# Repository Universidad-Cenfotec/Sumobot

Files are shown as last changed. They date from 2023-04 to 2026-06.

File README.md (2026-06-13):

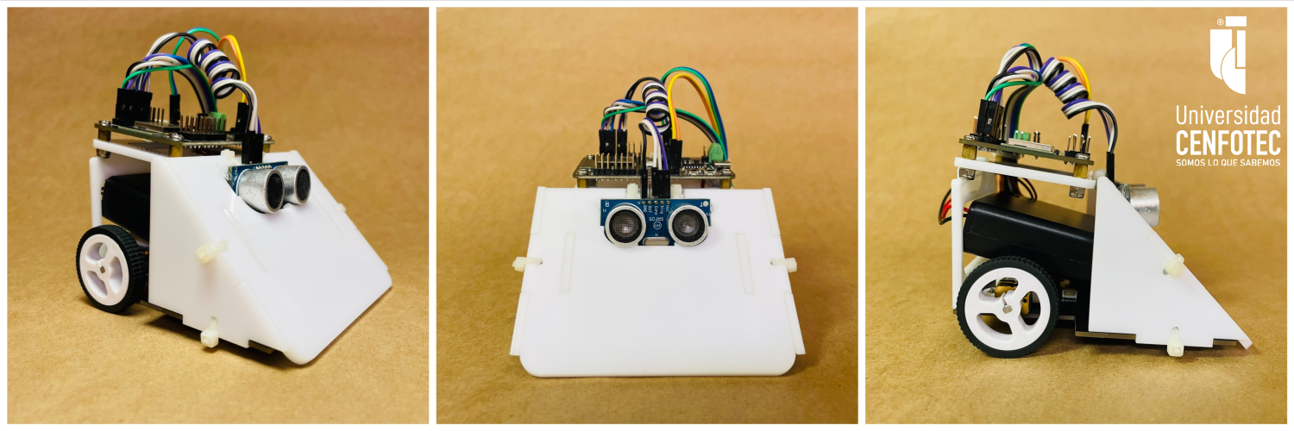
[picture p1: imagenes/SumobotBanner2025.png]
SumoBot


# ¿Que es el SumoBot de CENFOTEC? (o CenfoBot)

El Sumobot es un robot simple, 100% desarrollado en Costa Rica, para competencias colegiales de Sumobot. Fue diseñado por el profesor Tomás de Camino Beck para la Universidad Cenfotec como parte de un programa de transformación educativa, con el objetivo de ampliar las capacidades de pensamiento computacional tanto en estudiantes de colegio como en estudiantes universitarios.

> [En este enlace puede leer sobre la historia del Sumobot en sus 3 primeros años](https://crhoy.com/sumobot-una-historia-de-tecnologia-hecha-en-costa-rica/)  
> [Articulo técnico del Sumobot como plataforma de enseñanza](https://www.researchgate.net/publication/400625563_El_Sumobot_como_herramienta_de_aprendizaje_tecnologico_diseno_implementacion_y_evaluacion_en_torneos_colegiales)

El Sumobot utiliza la placa [IdeaBoard](https://github.com/CRCibernetica/circuitpython-ideaboard/wiki), desarrollada por CrCibernética. Esta placa de código abierto (Open Source) incorpora un microcontrolador ESP32 y permite la conexión sencilla de sensores y motores, así como su programación mediante USB o Wi‑Fi.

Para el montaje del robot, se emplea un *shield* de robótica especialmente diseñado por la Universidad CENFOTEC (por el profesor Tomás de Camino Beck) en colaboración con CrCibernética. Este componente puede [adquirirse en este enlace](https://www.crcibernetica.com/sumobot-shield/).

Puede ver este [video resumen](https://youtu.be/L98O-mApjXQ) de la primera competencia de Sumobot de Costa Rica, celebrada en el Maker Faire San José 2023. Y acá pueden ver un [video resumen](https://youtu.be/9zarR0cKY90?si=D4UTzPx91h4megWT) de la segunda edición en el 2024, y de la [tercera edición 2025](https://youtu.be/qRWDWPndxq8?si=iimM-hLvY60RDaJC)

[Documento técnico explicando los elementos pedagógicos del Sumobot](https://www.researchgate.net/publication/400625563_El_Sumobot_como_herramienta_de_aprendizaje_tecnologico_diseno_implementacion_y_evaluacion_en_torneos_colegiales)

---

## Contenidos de este Repositorio

- [EL espíritu del Torneo Sumobot](https://github.com/Universidad-Cenfotec/Sumobot/blob/main/espiritu_sumobot.md)
- [Componentes del Sumobot](https://github.com/Universidad-Cenfotec/Sumobot/blob/main/componentes2025.md)
- [Armado del Sumobot](https://github.com/Universidad-Cenfotec/Sumobot/blob/main/Armado%20paso%20a%20paso.md)
- [Conexiones del Sumobot](https://github.com/Universidad-Cenfotec/Sumobot/blob/main/conexiones.md)
- [Programación del Sumobot](https://github.com/Universidad-Cenfotec/Sumobot/blob/main/programacion.md)
- [Un buen código de inicio con explicaciones](https://github.com/Universidad-Cenfotec/Sumobot/tree/main/c%C3%B3digos_de_ejemplo/codigo%20inicio)
- [Códigos de ejemplo y códigos IdeaBoard](https://github.com/Universidad-Cenfotec/Sumobot/tree/main/c%C3%B3digos_de_ejemplo)
- [Sobre los 4 sensores infrarrojos](https://github.com/Universidad-Cenfotec/Sumobot/blob/main/c%C3%B3digos_de_ejemplo/sensores_infrarrojos.md)
- [Cómo calibrar los sensores infrerrojos, grabando los datos](https://youtu.be/5G9ZTyPEq5s?si=Cqf4HQZEF9e04VTD)
- [Especificaciones del Dojo](https://github.com/Universidad-Cenfotec/Sumobot/blob/main/dojo.md)
- [Reglas del Torneo Sumobot](https://github.com/Universidad-Cenfotec/Sumobot/blob/main/reglas%20de%20competencia.md)
- [Preguntas frecuentes](https://github.com/Universidad-Cenfotec/Sumobot/blob/main/FAQ.md)
- [Playlist de Videos de Sumobot](https://www.youtube.com/watch?v=Cxlyzh-E9kE&list=PLySA0noR1JGVZg5L3hGVwRD3PP2ibNYMT)

## Contenidos Avanzados
- [Programación en C/C++ (Avanzado)](https://github.com/Universidad-Cenfotec/Sumobot/tree/main/c%C3%B3digos_de_ejemplo_c%2B%2B/sumobot)
- [Control PDI de motores y navegación](https://github.com/Universidad-Cenfotec/Sumobot/blob/main/c%C3%B3digos_de_ejemplo/Control_Movimientos.md)
- [Almacenamiento de datos en el robot para análisis posterior](https://github.com/Universidad-Cenfotec/Sumobot/blob/main/c%C3%B3digos_de_ejemplo/almacenando_datos.md)
- [Ejemplo de automatización de vehiculos asistidos](https://github.com/Universidad-Cenfotec/Sumobot/tree/main/c%C3%B3digos_de_ejemplo/AGVs)
- [Sumobot con planificación autónoma con Modelos de Lenguajes (Gemini)](https://github.com/Universidad-Cenfotec/Sumobot/tree/main/c%C3%B3digos_de_ejemplo/LLM_in_the_Loop_Robotics)
- [Programación del Sumobot con bloques a través de una aplicación web](https://github.com/Universidad-Cenfotec/Sumobot/tree/main/c%C3%B3digos_de_ejemplo/codigo_bloques)

## Asistente IA para programar el Sumobot

- [GPT entrenado para programación Sumobot](https://chatgpt.com/g/g-6863f71f27b8819192a51ed05df367b0-asistente-de-programacion-sumobot-cenfotec)

## Retos

- Hacer una estrategia de "scan" del contrincante más eficiente
- Hace movimientos oscilatorios para tratar de levantar al oponente
- Utilizar giroscopios para movimientos exactos ([ver este código](https://github.com/Universidad-Cenfotec/Sumobot/blob/main/c%C3%B3digos_de_ejemplo/Control_Movimientos.md))
- Utilizar el "botón 0" para que arranque el robot apenas suelten el botón ([ver este código](https://github.com/Universidad-Cenfotec/Sumobot/blob/main/c%C3%B3digos_de_ejemplo/code_boton0.py))
- Entender que cada combate inicia diferente y aprovechar esas posiciones
- Estudiar comportameinto de sensores almacenando los datos ([ver este código](https://github.com/Universidad-Cenfotec/Sumobot/blob/main/c%C3%B3digos_de_ejemplo/almacenando_datos.md))

## Algunos Saberes Escenciales de el Sumobot

| Área de Conocimiento | Saberes Esenciales | Ejemplos desde el Kit Sumobot |
| --- | --- | --- |
| **1. Pensamiento Computacional** | - Estructuras de control<br>- Modularidad<br>- Algoritmos<br>- Programación de eventos | `code.py`, `retroceso.py`, `code_boton0.py`, `code_set_pixel_to.py`, uso de funciones en todos los scripts |
| **2. Robótica y Electrónica** | - Lectura de sensores<br>- Control de motores<br>- Interacción hardware-software <br>- Precepción del entorno  <br>- Calibración de sensores <br>- Interacción con otros agentes  <br>- Menjo de incertidumbre  | `code_ultrasonic.py`, `code_acc_motor_move.py`, `Control_Movimientos.md`, `Pixel_colores.py` |
| **3. Ciencia de Datos** | - Registro de datos<br>- Análisis y visualización<br>- Experimentación <br>- Desiciones basadas en datos | `code_storage.py`, `code_storage_IR.py`, `almacenando_datos.md`, ejemplo de uso con Google Sheets |
| **4. Matemáticas Aplicadas** | - Lógica binaria<br>- Cálculo de gradientes<br>- Estimación de distancia <br>- Sistemas de control <br>- Integral y derivada | `code_lecturaIR_4Bit.py`, `code_gradiente.py`, `Calculo _Gradiente.md`, `code_ultrasonic.py` |
| **5. Ingeniería de Sistemas** | - Diseño e integración de componentes<br>- Diagnóstico y prueba de sistemas <br>- Verificación de errores <br>- Interacción humano máquina <br>- Sistemas complejos  <br>- Programación Asistida IA <br>- Inteligencia Artificial | `code_diagnostic.py`, `SumoBot_Device_Files.zip`, `movimiento_base.md`, `libreria IdeaBoard.md` |
| **6. Habilidades Transversales (STEAM)** | - Resolución de problemas<br>- Trabajo en equipo<br>- Comunicación técnica <br>- Autodeterminación | Uso de Markdown (`*.md`), documentación clara, posibilidad de trabajo colaborativo y creativo con el robot |

---

# Una plataforma Open Source

## ¿Por qué un robot open source?

El Sumobot fue diseñado como una plataforma educativa abierta para el aprendizaje de robótica, programación y sistemas autónomos. Un robot open source permite que cualquier persona —estudiantes, docentes, clubes de robótica o investigadores— pueda construirlo, modificarlo y adaptarlo a sus propias necesidades.

En robótica educativa es fundamental que los estudiantes no solo usen la tecnología, sino que puedan comprender cómo funciona. Un robot abierto permite estudiar todos sus componentes: electrónica, sensores, control de motores, algoritmos de comportamiento y diseño mecánico. Esto convierte al robot en un laboratorio completo de aprendizaje.

Además, un diseño abierto reduce las barreras de acceso. Las instituciones educativas pueden reproducir el robot localmente utilizando componentes accesibles, lo que facilita su adopción en escuelas y colegios.

## ¿Por qué el diseño open source?

El diseño mecánico del robot también es abierto para que pueda ser reproducido mediante fabricación digital. Esto incluye archivos de diseño que permiten imprimir o fabricar las piezas del robot en impresoras 3D, cortadoras láser u otros métodos de fabricación.

Esto tiene varias ventajas educativas y técnicas:

* Permite que los estudiantes comprendan cómo el diseño físico afecta el comportamiento del robot.
* Facilita modificaciones y mejoras en la estructura del robot.
* Permite adaptar el robot a diferentes materiales o tecnologías de fabricación.
* Promueve la cultura *maker* y la experimentación.

Un robot de competencia no es solo software; el diseño físico influye directamente en su desempeño en el dojo. Tener el diseño abierto permite explorar estas decisiones de ingeniería.

## ¿Por qué el código open source?

El comportamiento del robot es controlado por software. Hacer el código open source permite que los estudiantes y participantes del torneo puedan estudiar cómo se toman las decisiones dentro del robot.

Esto permite:

* Aprender algoritmos de control para robots autónomos.
* Experimentar con diferentes estrategias de combate.
* Comprender cómo se integran sensores, actuadores y lógica de decisión.
* Desarrollar nuevas versiones del comportamiento del robot.

El objetivo no es que todos los robots ejecuten exactamente el mismo programa, sino que cada equipo pueda desarrollar su propia estrategia a partir de una base común.

## ¿Por qué un torneo open source?

El torneo también se basa en una filosofía abierta. En lugar de esconder las tecnologías o estrategias, se promueve compartir conocimiento entre equipos, docentes y estudiantes.

Esto genera varios beneficios:

* acelera el aprendizaje colectivo
* permite mejorar el robot y el torneo con el tiempo
* fomenta la colaboración entre instituciones
* convierte el torneo en una comunidad de aprendizaje

El objetivo del torneo no es solo competir, sino aprender robótica de forma práctica. Cada edición del torneo genera nuevas mejoras en el robot, en el código y en las estrategias de control.

De esta manera, el Sumobot no es solo un robot ni solo una competencia. Es una plataforma abierta de aprendizaje en robótica.

---

# Licencia

Sumobot es un robot desarrollado con el propósito de potenciar el aprendizaje de computación en colegios. Este proyecto está abierto a contribuciones y estamos encantados de recibir nuevas ideas.

Este robot está protegido por una licencia Creative Commons. Específicamente, se trata de la licencia CC BY‑NC‑SA 4.0, que significa Atribución‑NoComercial‑CompartirIgual 4.0 Internacional.

Bajo esta licencia, se permite el uso, distribución y modificación del robot, pero con las siguientes condiciones:
- **Atribución** — Debes dar el crédito correspondiente, proporcionar un enlace a la licencia e indicar si se han realizado cambios.
- **NoComercial** — No puedes utilizar el material para una finalidad comercial.
- **CompartirIgual** — Si remezclas, transformas o creas a partir del material, debes distribuir tus contribuciones bajo la misma licencia que el original.

Para obtener más detalles sobre la licencia, por favor visita [https://creativecommons.org/].

CC


# Contribuciones

Si estás interesado en contribuir al Sumobot, por favor revisa las guías de contribución disponibles en la sección de "Documentación". Todas las contribuciones son bienvenidas, sin importar cuán pequeñas sean. Juntos podemos hacer que Sumobot sea mejor para todos.

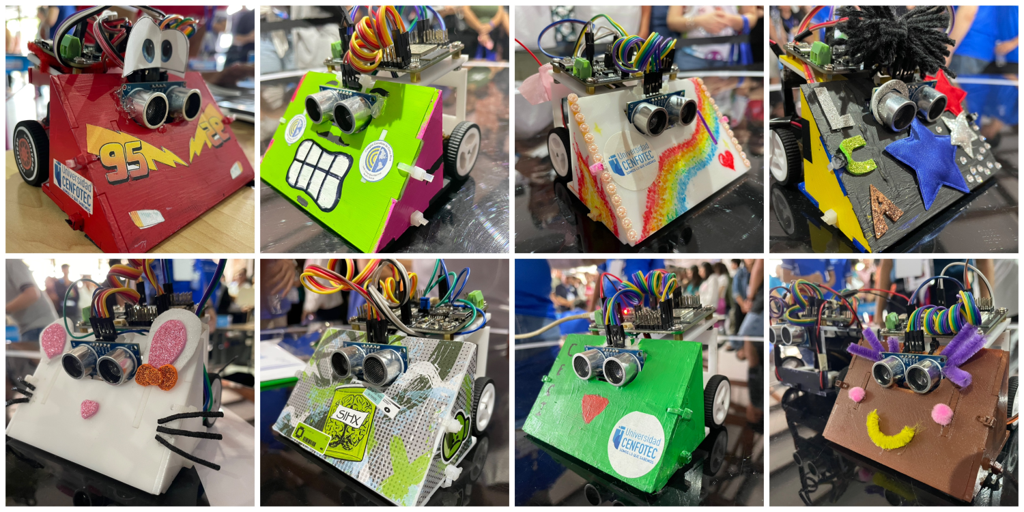
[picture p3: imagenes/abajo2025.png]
SumoBot1


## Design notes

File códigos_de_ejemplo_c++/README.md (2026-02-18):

# C++ con el FrameWork de Arduino 🍝
C++ es un versátil lenguaje de "bajo nivel", lo que significa que habla casi directo con los circuitos del chip. El framework de Arduino funciona como un traductor amigable que envuelve a C++ para que no tengas que ser un genio de la computación para encender un LED, este se encarga de exponer funciones útiles como lecturas de pines, comunicación Serial, Etc.

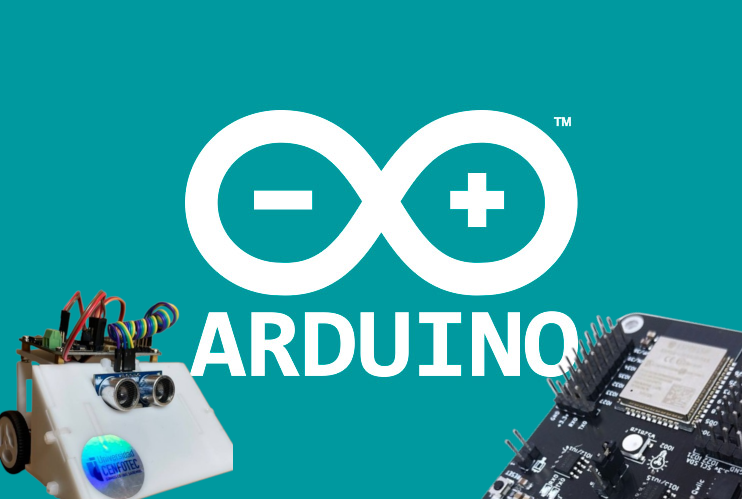
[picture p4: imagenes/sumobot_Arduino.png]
SumobotArduino


# Programar el IdeaBoard con C/C++

## Instalación de Arduino IDE
Para programar el ideaboard con C/C++ puede utilizar el Arduino IDE. [En este video se Explica como instalar y utilizar el Arduino IDE](https://youtu.be/Gd5cj3yKtPM?si=9Gexbs7unJ-1I55R)

## Dirección de Pines del IdeaBoard
Todos sketchs usan las conexiones estandar que se encuentran en el archivo [conexiones.md](https://github.com/Universidad-Cenfotec/Sumobot/blob/main/conexiones.md) para el sumobot version 2025.

Ya que no se está usando la libreria ideaboard.py para la desobfuscación de ciertos pines, tienes que referirte a los pines del ESP32 conectada a la placa en el código 

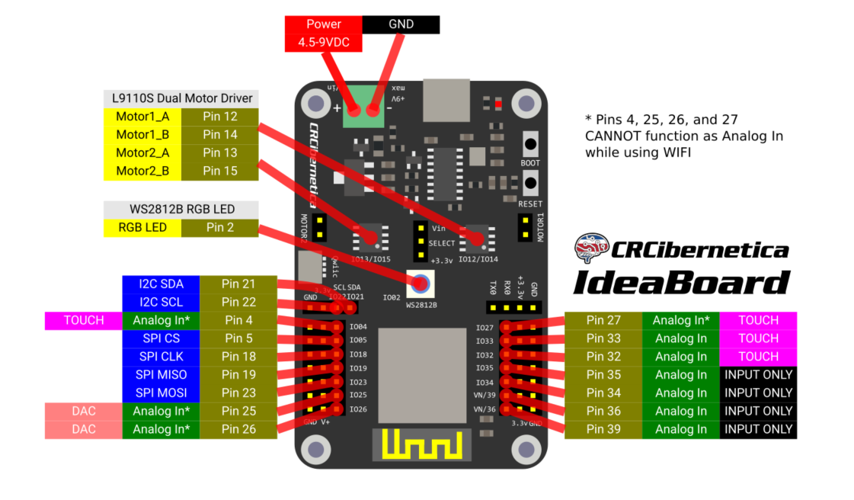
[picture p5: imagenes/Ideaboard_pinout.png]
pinout


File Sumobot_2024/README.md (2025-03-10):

## Componentes del Sumobot 2024
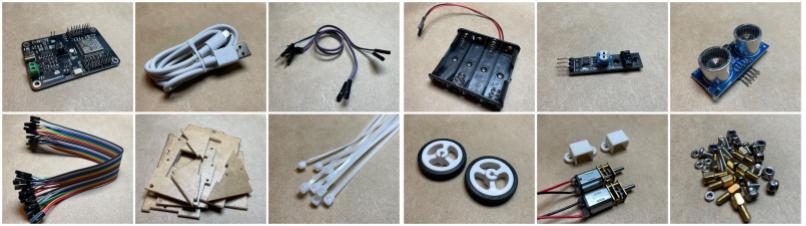
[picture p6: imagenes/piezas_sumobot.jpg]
SumoBot Parts


- [IdeaBoard (ESP32)](https://www.crcibernetica.com/crcibernetica-ideaboard/)
- Cable USB C
- Tiras de plástico de 2.5 mm
- Tornillos y tuercas para colocar la placa IdeaBoard
- Tornillos adicionales para sostener los motores
- 2 x soportes de motor microgear
- 2 x [micro motores](https://www.crcibernetica.com/micro-gearmotor/) de 200 RPM
- 2 x ruedas
- Soporte de 4 baterías AA
- [Sensor IR](https://www.crcibernetica.com/track-sensor-module/)
- [Sensor ultrasónico](https://www.crcibernetica.com/hc-sr05-ultrasonic-distance-sensor/) de distancia (HCSR04)
- Piezas de acrílico de 3 mm ([Ver archivo de corte láser](https://github.com/Universidad-Cenfotec/Sumobot/blob/main/archivos_de_fabricacion/chasis_sumobot.svg))

Todos los componentes se pueden encontrar en Costa Rica en [CrCibernética](https://www.crcibernetica.com/sumobot-universidad-cenfotec/). [Aquí pueden ver un video](https://youtu.be/N60gXp_uzeo?si=2TApsz6n20wZ9ZoX) de los componentes que vienen como parte del kit.

---

## Chasis del Sumobot 2024

El archivo "Sumobot_Chasis.svg" está en formato SVG para corte láser del chasis de Sumobot. Se puede cortar tanto en acrílico, MDF u otro material de 3 mm de espesor.

También, con el archivo [chasis_sumobot_2025_3D.stl](https://github.com/Universidad-Cenfotec/Sumobot/blob/main/archivos_de_fabricacion/chasis_sumobot2025_3D.stl) pueden imprimir el chasis en una impresora 3D. Esto facilita agregar estructuras más complejas que no son posibles en 2D.

El chasis del robot se une con tiras (gasas/zip ties) de plástico de 2.5 mm, lo que facilita el armado, la reparación o la modificación de algunas partes.

---

# Armando el Sumobot 2024

Pueden ver [este video detallado](https://youtu.be/m4y3BSPjgoc?si=vLK6NNjRJQF1DbDc) de cómo armar el Sumobot.

## Kit Sumobot
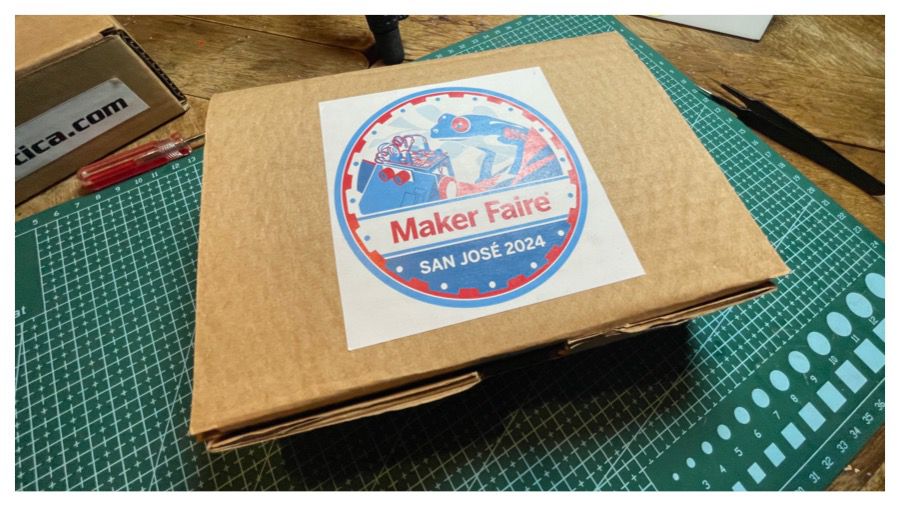
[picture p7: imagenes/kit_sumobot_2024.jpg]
Kit Sumobot


El Kit Sumobot es creación de la Universidad CENFOTEC y lo distribuye CrCibernetica.com. Si desean adquirir el kit, pueden contactar libremente a CrCibernetica.

## Esquema de conexiones Sumobot 2024

- El sensor infrarrojo se conecta en el IO033.
- El sensor ultrasónico se conecta en el IO026 (trig) e IO025 (echo).
- Los motores se conectan en Motor 1 y Motor 2 (con posiciones invertidas).

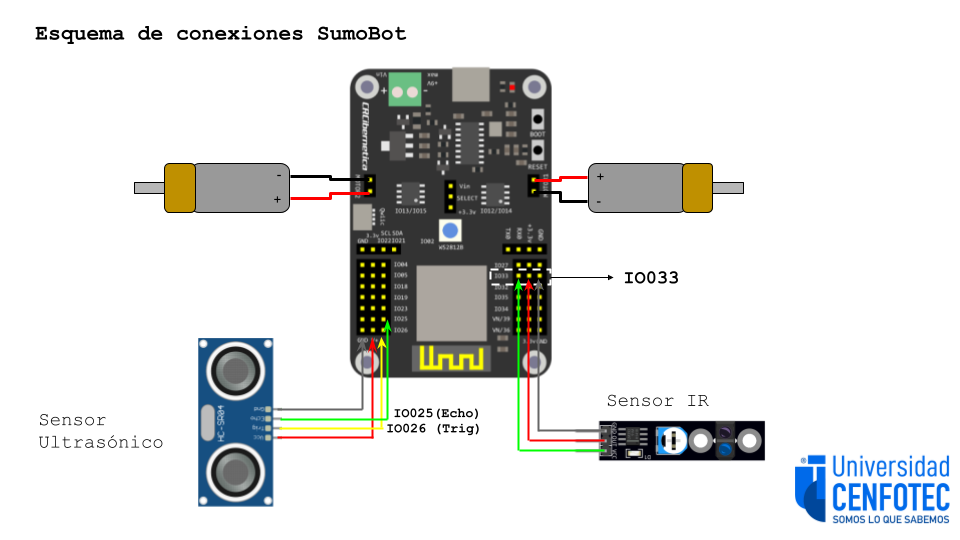
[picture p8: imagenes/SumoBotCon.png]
SumoBot_Conexions


## Baterías
Las baterías se conectan: el cable rojo al pin marcado como "+" y el negro al pin "-", como se muestra en el siguiente esquema:

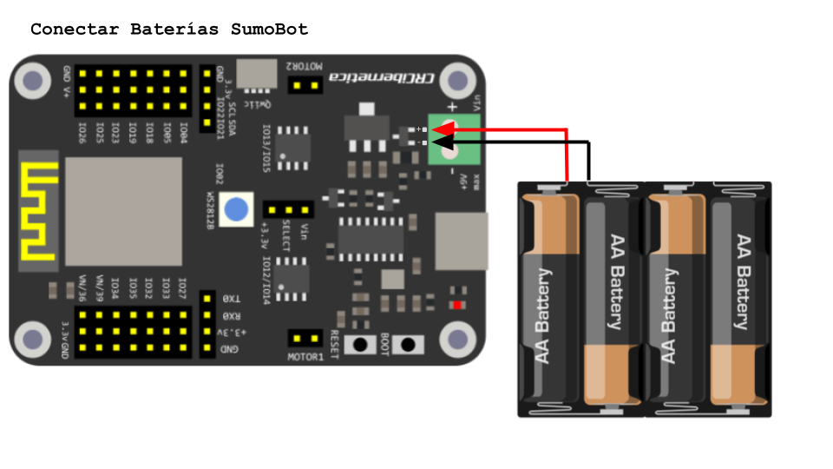
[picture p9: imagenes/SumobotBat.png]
SumoBot_baterías


## Software para programar el Sumobot 2024

Para programar el Sumobot se utiliza Thonny, el cual se puede descargar desde este [enlace](https://thonny.org/).

### Instrucciones:
- Descargar la última versión de Thonny.
- Instalar.
- Una vez instalado, ir al menú "Herramientas > Opciones" o "Tools > Options" en inglés.
- En la pestaña "Intérprete" (o "Interpreter" en inglés), seleccionar "CircuitPython (Generic)".
- ¡Listo!
- [Video con detalles](https://youtu.be/Zc3oaAbVAdc)

## Código 2024

El código "code.py" está desarrollado en CircuitPython. CircuitPython es un subconjunto de Python desarrollado para microcontroladores y facilita la portabilidad y programabilidad de dispositivos como el ESP32, entre otros. El Sumobot ya viene preparado para trabajar con CircuitPython y no es necesario cargar archivos adicionales. Si por alguna razón se debe "reflashear" el IdeaBoard, siga las instrucciones en este [enlace](https://github.com/CRCibernetica/circuitpython-ideaboard/wiki/3.-Installation).

El código "hcsr04.mpy" corresponde a la librería para el sensor de distancia, el cual se utiliza para detectar otro robot que esté al frente del Sumobot.

### Funciones Básicas 2024

- **wiggle(t, n, speed):** Hace que el bot se mueva de izquierda a derecha durante _t_ segundos, a velocidad _speed_, repitiéndolo _n_ veces.
- **forward(t, speed):** Mueve el bot hacia adelante durante _t_ segundos a velocidad _speed_.
- **backward(t, speed):** Mueve el bot hacia atrás durante _t_ segundos a velocidad _speed_.
- **left(t, speed):** Mueve el bot hacia la izquierda durante _t_ segundos a velocidad _speed_.
- **right(t, speed):** Mueve el bot hacia la derecha durante _t_ segundos a velocidad _speed_.
- **stop():** Detiene el bot.
- **randomTurn(t, speed):** Gira al azar a la izquierda o a la derecha durante _t_ segundos a velocidad _speed_.
- **lookForward():** Realiza la lectura del sensor ultrasónico y retorna la distancia en cm de lo que esté en frente del bot.
- **scan():** Rota hacia un lado hasta que detecta algo adelante o hasta que gire un número determinado de veces.
- **forwardCheck(t, speed):** Mueve hacia adelante, pero verifica, mediante el sensor IR, que no se salga del dojo. Cuando detecta el borde, realiza un movimiento hacia atrás y luego gira.

### Recuperar la configuración inicial

Si por alguna razón se desea resetear el Sumobot a los archivos iniciales, cargue, a través de Thonny en el dispositivo CircuitPython (con el Sumobot conectado), todos los archivos que vienen en el archivo ZIP "SumoBot_Device_Files.zip".

---

## Videos Instructivos 2024
- [Cómo instalar Thonny](https://youtu.be/Zc3oaAbVAdc)
- [Conectar el Sumobot a Thonny](https://youtu.be/SpIcqRKmczk)
- [Instalando las baterías del Sumobot](https://youtu.be/ndWJ0q0M8CI)
- [Calibrando el sensor infrarrojo](https://youtu.be/XXJbzzaVefk) 
- [El código principal del Sumobot](https://youtu.be/86sQCr-bjjk)
- [CircuitPython: Programando el LED RGB](https://youtu.be/5ezFqexHwQE)
- [Programando el sensor infrarrojo](https://youtu.be/1JA3G-FPpJ4)
- [Programando el sensor ultrasónico](https://youtu.be/RwY2lEPkyg8)
- [Motores DC con el Sumobot](https://youtu.be/MybJACeDIgA)

---

# Competencia SumoBot 2024
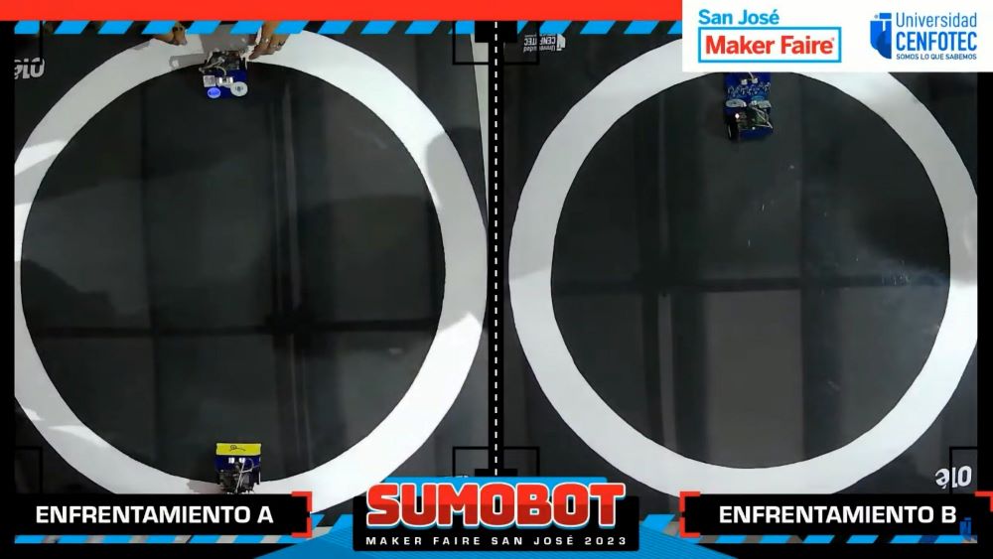
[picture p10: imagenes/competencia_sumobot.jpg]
SumoBot_Dojo


## Formato de competición 2024

- El torneo SumoBot se estructura como un torneo por eliminatoria.
- Dos robots compiten en un "dojo". El robot que sea sacado del ring, que deje de funcionar o que no tenga posibilidad de movimiento, pierde.
- Se define una llave previa en la que los equipos serán asignados al azar.
- Denominamos "set" a cada encuentro entre dos robots.
- Cada set consiste en 3 juegos (matches) de un minuto y medio, con una pausa de un minuto entre cada juego para ajustes o cambios de estrategia.
- El "dojo" es un ring circular de 80 cm de diámetro, con fondo negro y una línea de borde blanca de 5 cm. De esta manera, los robots pueden identificar cuándo están dentro o fuera del ring y detectar el borde mediante un sensor infrarrojo.
- Este archivo PDF contiene el diseño del [Mini‑Dojo](https://github.com/Universidad-Cenfotec/Sumobot/blob/main/circulo_10cmEspesor.pdf). El Mini‑Dojo se puede utilizar para probar diferentes ideas y garantizar que el robot funcione, pero siempre se debe tener en cuenta que el dojo de la competencia es mucho más grande y, además, cuenta con una lámina de acrílico de 3 mm.

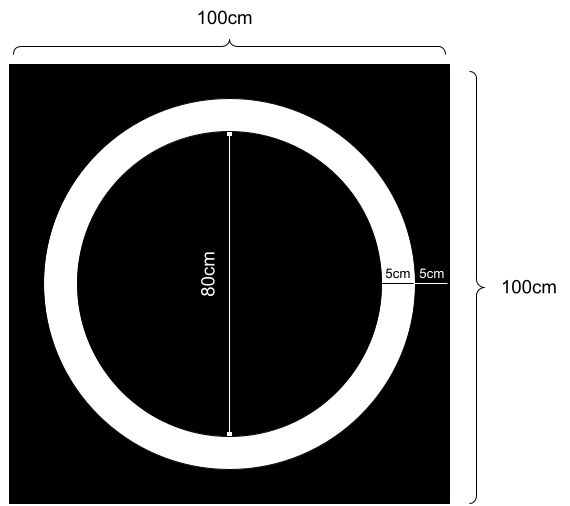
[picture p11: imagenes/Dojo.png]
Dojo


## Principios del juego 2024

- La mesa de arbitraje revisará el robot para determinar que cumple con las especificaciones requeridas.
- Son tres combates por partida, y se gana por puntos.
- Un robot perderá si es removido del dojo más allá de la línea blanca del borde o si no ejecuta ningún movimiento durante el tiempo asignado.
- Cada batalla tiene una duración máxima de 1 minuto y 30 segundos.
- En caso de empate (si ninguno de los robots es sacado del dojo), la mesa de arbitraje considerará ganador al robot con mayor número de ataques.
- Las tres acciones de batalla son: atacar, defender y buscar.
- La competencia es por eliminación, y los equipos se clasifican en pares hasta la final.
- El código de los dos primeros lugares será publicado de forma abierta en este GitHub, con el fin de ir mejorando el nivel año con año.

---

# Reglamento 2024

## DEFINICIONES:
1. **Sumobot:** El robot Sumobot es un robot de combate autónomo programado por el usuario, que deberá sacar a su rival del área de combate (dojo), ya sea empujándolo, arrastrándolo o dejándolo inhabilitado.
2. **Partida:** Enfrentamiento entre 2 robots de diferentes equipos, dividido en 3 combates.
3. **Maker Space:** Laboratorio de innovación de la Universidad CENFOTEC.
4. **GitHub:** Plataforma para crear proyectos abiertos de herramientas y aplicaciones, caracterizada, sobre todo, por sus funciones colaborativas que ayudan a que todos puedan aportar su granito de arena para mejorar el código.
5. **Mesa de arbitraje:** Persona o grupo de personas con autoridad, responsables de presidir el juego desde un punto de vista neutral y de tomar decisiones sobre la marcha que hagan cumplir las reglas de este reglamento.
6. **Dojo:** Área de combate, el espacio formado por la tarima circular y un espacio circundante denominado "área exterior de seguridad".
7. **Ronda:** Sistema en torneos en el que el perdedor de un encuentro queda inmediatamente eliminado de la competición, mientras que el ganador avanza a la siguiente fase. Se juegan rondas y, en cada una de ellas, se elimina a la mitad de los participantes hasta dejar un único competidor que se corona como campeón.

## ESPECIFICACIONES DEL ROBOT 2024
1. Los robots son entregados por la Universidad CENFOTEC. Los colegios deben armar los robots siguiendo las instrucciones publicadas por la Universidad CENFOTEC en GitHub.
2. El peso del robot, incluyendo la caja y las baterías, es de 260 g. El peso debe mantenerse siempre entre 260 y 290 gramos. Al agregar otros sensores, el peso puede aumentar ligeramente (por ejemplo, un sensor ultrasónico pesa aproximadamente 8.5 gramos).
3. No se permiten modificaciones estructurales en el robot. Se puede adaptar para colocarle más sensores, pero no se permiten agregar puntas o extensiones para otros propósitos.
4. Se pueden agregar sensores adicionales que no impliquen modificaciones en la estructura del robot.
5. No se pueden cambiar los neumáticos o las ruedas del robot, para asegurar condiciones de igualdad entre los robots y que el ganador se determine por estrategia.
6. No se pueden cambiar los motores.
7. No se puede utilizar otro tipo de baterías.
8. Cada robot será revisado antes de cada competencia.
9. En situaciones especiales respecto a las especificaciones del robot, su estructura y funcionamiento, que no estén claramente definidas en las reglas, se decidirá a criterio unificado de los jueces.

## REGLAS DEL JUEGO 2024
1. Un fiscal revisará cada robot para asegurarse de que cumple con las especificaciones requeridas. En caso de duda, será verificado por los jueces.
2. Cada partida consta de tres combates. En cada combate, a cada equipo se le asignan 3 puntos por ganar, 1 punto en caso de empate y 0 puntos por perder.
3. Al iniciar la partida, el equipo debe programar el robot para que espere 3 segundos antes de comenzar sus movimientos y actividades.
4. Un robot pierde si es removido del dojo más allá de la línea blanca del borde, si no ejecuta ningún movimiento durante el tiempo asignado o si queda inmovilizado por el oponente.
5. Cada batalla tiene una duración máxima de 1 minuto y 30 segundos.
6. En caso de empate en un combate, cada equipo gana 1 punto.
7. La competencia inicia por grupos, y las siguientes rondas son por eliminación, en las que los equipos avanzan en pares hasta la final.
8. Cada combate comienza de manera diferente: primero, con los robots frente a frente a una distancia aproximada de 10 cm; luego, espalda con espalda; y, finalmente, lado a lado, con los robots viendo en direcciones opuestas.
9. Entre cada combate se dispone de 1 minuto para revisar el robot y realizar posibles cambios.
10. Si en una partida los equipos quedan empatados por puntos, se hará la rifa por moneda.
11. De todos los equipos que perdieron en la primera ronda, se escogerá (por definir) un número de los segundos mejores.
12. Si en una partida uno de los equipos no se presenta, ganará automáticamente el que sí se presentó (obtendrá 9 puntos por partida en la primera ronda o pasará a la siguiente ronda a partir de la segunda ronda).
13. Si un equipo llega tarde a la primera partida, podrá presentarse a las siguientes, pero se le asignará la derrota en la primera partida.
14. Si en una partida ninguno de los equipos se presenta, para la siguiente ronda se seleccionarán los mejores segundos lugares.

## SANCIONES Y APELACIONES 2024
1. Si un equipo no se presenta para un "match" en el día del evento, el equipo oponente clasificará automáticamente.

## DISPOSICIONES FINALES
Este evento tiene como objetivo colaborar, apoyar y estimular a la comunidad, por lo que cada colegio representado podrá recibir apoyo de sus oponentes en el momento en que éstos lo manifiesten. Los docentes pueden ayudar y asesorar a sus equipos. Se espera que los docentes permitan y estimulen a sus estudiantes a realizar el 100% del trabajo.

---

# Preguntas Frecuentes

1. **¿El código se puede modificar?**  
   R: Sí, se puede modificar.

2. **¿Se pueden agregar partes al robot?**  
   R: No se permiten modificaciones estructurales del robot. Se puede adaptar para colocarle más sensores, pero no se permiten agregar puntas o extensiones para otros propósitos.

3. **¿Se puede modificar el hardware?**  
   R: Se pueden agregar sensores adicionales que no impliquen modificaciones en el robot (por ejemplo, modificar el chasis). Es decir, se pueden incorporar a la estructura del chasis sin agregar nada más. Cada robot será revisado antes de cada torneo de competencia.

4. **¿Se pueden agregar sensores de toque, por ejemplo?**  
   R: Se pueden agregar sensores adicionales que no impliquen modificaciones en el robot.

5. **¿Los estudiantes llevan la programación hecha o la memorizan?**  
   R: Los estudiantes llevan el programa hecho y, en el mismo evento, pueden modificar la programación. Si no cuentan con computador, se les facilitará uno en el evento.

---

# Algunas cosas por mejorar
- Algunos motores presentan problemas y generan un corto.
- Los cables de los motores deben ser más largos. Por el momento se están utilizando extensiones.

---

[Nombre del proyecto]

# Licencia

Sumobot es un robot desarrollado con el propósito de potenciar el aprendizaje de computación en colegios. Este proyecto está abierto a contribuciones y estamos encantados de recibir nuevas ideas.

Este robot está protegido por una licencia Creative Commons. Específicamente, se trata de la licencia CC BY‑NC‑SA 4.0, que significa Atribución‑NoComercial‑CompartirIgual 4.0 Internacional.

Bajo esta licencia, se permite el uso, distribución y modificación del robot, pero con las siguientes condiciones:
- **Atribución** — Debes dar el crédito correspondiente, proporcionar un enlace a la licencia e indicar si se han realizado cambios.
- **NoComercial** — No puedes utilizar el material para una finalidad comercial.
- **CompartirIgual** — Si remezclas, transformas o creas a partir del material, debes distribuir tus contribuciones bajo la misma licencia que el original.

Para obtener más detalles sobre la licencia, por favor visita [https://creativecommons.org/].

CC

# Contribuciones

Si estás interesado en contribuir al Sumobot, por favor revisa las guías de contribución disponibles en la sección de "Documentación". Todas las contribuciones son bienvenidas, sin importar cuán pequeñas sean. Juntos podemos hacer que Sumobot sea mejor para todos.

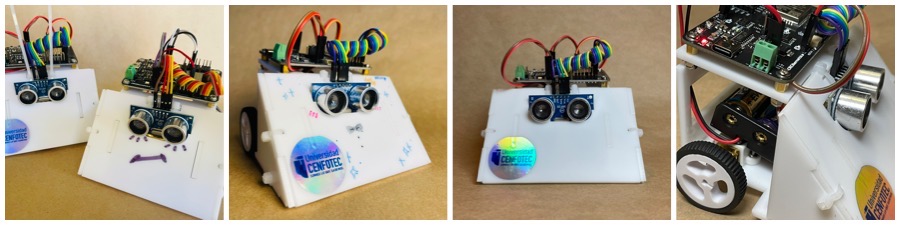
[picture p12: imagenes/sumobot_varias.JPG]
SumoBot1


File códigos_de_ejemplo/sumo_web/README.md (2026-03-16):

# Control remoto del Sumobot mediante Bluetooth Low Energy (BLE)

Fiorella Pérez López  
Universidad CENFOTEC

---

# Introducción

Este proyecto muestra cómo controlar un **Sumobot de forma remota utilizando Bluetooth Low Energy (BLE)** y una **interfaz web accesible desde el navegador**.

En lugar de utilizar un control físico o un programa instalado en la computadora, el robot puede ser controlado directamente desde una **página web interactiva**. Esta página permite enviar comandos de movimiento al robot, el cual los interpreta y ejecuta en tiempo real.

El robot utiliza un **sistema de control PDI basado en giroscopio** para mantener trayectorias rectas al avanzar o retroceder, compensando pequeñas diferencias entre los motores.

Este proyecto combina conceptos de:

- robótica móvil  
- sistemas embebidos  
- comunicación inalámbrica  
- control automático  
- interfaces web interactivas  
- desarrollo web aplicado a robótica  

---

# ¿Qué es el control mediante BLE?

Bluetooth Low Energy (BLE) es un protocolo de comunicación inalámbrica diseñado para dispositivos que requieren **bajo consumo energético**.

En este proyecto, BLE permite que un **navegador web se conecte directamente al robot** sin necesidad de instalar aplicaciones adicionales.

El proceso de comunicación ocurre de la siguiente manera:

1. El robot inicia un servicio BLE.
2. El navegador busca dispositivos BLE cercanos.
3. El usuario selecciona el robot.
4. La página web establece la conexión.
5. La interfaz envía comandos de movimiento.
6. El robot recibe los comandos y ejecuta la acción correspondiente.

Este método permite controlar el robot de forma sencilla desde distintos dispositivos.

---

# Interfaz web de control

La página se encuentra publicada mediante **GitHub Pages**, lo que permite acceder a ella desde cualquier navegador compatible.

### 🌐 Acceso a la interfaz

https://aggy2025.github.io/cenfobot-control/

## 📱 Controla el robot desde tu celular

Escanea este código QR para abrir la interfaz web del Sumobot.

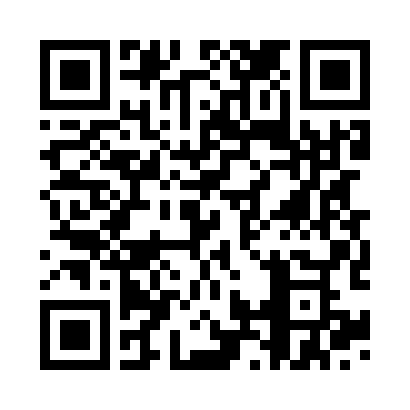
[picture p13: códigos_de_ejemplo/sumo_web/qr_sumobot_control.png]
QR Control Sumobot


No es necesario instalar ninguna aplicación.  
El control se realiza directamente desde el navegador.

---

# Compatibilidad con dispositivos

La interfaz fue diseñada para ser **responsive**, lo que significa que se adapta automáticamente al tamaño de la pantalla.

Esto permite controlar el robot desde distintos dispositivos.

| Dispositivo | Compatibilidad |
|---|---|
| Computadora (PC o laptop) | ✔ Compatible |
| Teléfono móvil | ✔ Compatible |
| Tablet | ✔ Compatible |

El control funciona en navegadores que soportan **Web Bluetooth**, como:

- Google Chrome  
- Microsoft Edge  
- Opera  

Actualmente **Safari no soporta Web Bluetooth**.

---

# Características de la interfaz

La página web incluye varios elementos para facilitar el control del robot.

Entre ellos:

- botones de dirección para controlar el movimiento
- control deslizante para ajustar la velocidad
- indicador de estado de conexión BLE
- registro de mensajes enviados al robot
- botón para limpiar el registro
- LED virtual que muestra el estado del robot

---

# Arquitectura del sistema

El sistema se compone de tres componentes principales.

### Robot Sumobot

- controla los motores
- lee el giroscopio
- aplica el control PDI
- recibe comandos BLE
- controla el LED NeoPixel

### Interfaz Web

- permite enviar comandos desde el navegador
- muestra indicadores visuales del estado del robot
- permite ajustar la velocidad
- registra los comandos enviados

### Comunicación BLE

- conecta la interfaz web con el robot
- transmite instrucciones de movimiento en tiempo real
- utiliza el servicio **BLE UART**

# Comandos enviados al robot

Los comandos enviados desde la interfaz siguen el formato:

COMANDO,VELOCIDAD

Ejemplo:
F,0.5

Esto indica que el robot debe **avanzar con una velocidad del 50%**.

---

# Instrucciones disponibles

| Comando | Acción |
|---|---|
| F | Avanzar |
| B | Retroceder |
| L | Girar izquierda |
| R | Girar derecha |
| S | Detener |

Ejemplo enviado al robot:

Ejemplo enviado al robot:

Esto indica que el robot debe **retroceder al 70% de velocidad**.

---

# Control de movimiento con giroscopio

El robot utiliza un **sensor IMU con giroscopio**, el cual permite detectar la rotación del robot mientras se mueve.

Para mantener una trayectoria recta se utiliza un **controlador PDI (Proporcional-Derivativo-Integral)**.

Este controlador ajusta dinámicamente la velocidad de los motores utilizando una corrección basada en el error de orientación.

Esto indica que el robot debe **retroceder al 70% de velocidad**.

---

# Control de movimiento con giroscopio

El robot utiliza un **sensor IMU con giroscopio**, el cual permite detectar la rotación del robot mientras se mueve.

Para mantener una trayectoria recta se utiliza un **controlador PDI (Proporcional-Derivativo-Integral)**.

Este controlador ajusta dinámicamente la velocidad de los motores utilizando una corrección basada en el error de orientación.

Si el robot comienza a desviarse hacia un lado, el sistema compensa automáticamente ajustando la velocidad de cada motor.

Esto permite:

- avanzar en línea recta  
- retroceder con estabilidad  
- reducir errores de trayectoria  

---

# Indicadores visuales

El robot utiliza un **LED NeoPixel** para indicar su estado.

| Color | Estado |
|---|---|
| Verde | Avanzando |
| Rojo | Retrocediendo |
| Cian | Girando |
| Amarillo | Detenido |
| Naranja | Calibración inicial |

La interfaz web incluye un **LED virtual sincronizado** que representa visualmente el estado del robot.

# Archivos principales del proyecto

El proyecto utiliza los siguientes archivos.

| Archivo | Descripción |
|---|---|
| index.html | Interfaz web de control publicada en GitHub Pages |
| sumobot_ble.py | Código principal del robot con comunicación BLE |
| README.md | Documentación del proyecto |

# Conclusión

Este proyecto demuestra cómo es posible integrar **robótica, comunicación inalámbrica y desarrollo web** para crear un sistema de control remoto accesible desde cualquier navegador compatible.

El uso de **BLE y Web Bluetooth** permite eliminar la necesidad de aplicaciones adicionales, facilitando la interacción entre el usuario y el robot.

Además, el uso de **control PDI con giroscopio** mejora la estabilidad del movimiento del robot, permitiendo trayectorias más precisas durante su operación.

Este tipo de sistemas representa una forma moderna de conectar **hardware físico con interfaces web interactivas**, abriendo nuevas posibilidades para proyectos educativos y de investigación en robótica.

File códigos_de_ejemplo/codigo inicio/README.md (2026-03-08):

# Código de Combate

Este código (`code.py`) es un buen punto de partida para el Sumobot. Permite entender la mayoría de funcionalidades, y cambiando parámetros o combinaciones de funciones, permite tener diferentes estrategias de combate.

# 1. Encabezado e importaciones

```python
import board
import keypad
from ideaboard import IdeaBoard
from time import sleep
from hcsr04 import HCSR04
import random
```

## Qué hace esta sección

Aquí se cargan las librerías que el programa necesita para funcionar.

## Para qué sirve cada una

### `import board`

Permite usar los pines físicos del microcontrolador con nombres como:

* `board.IO0`
* `board.IO25`
* `board.IO26`
* `board.IO36`

Es la forma de decirle al código en qué pin está conectado cada sensor o botón.

---

### `import keypad`

Se usa para leer botones de manera más cómoda.
En este caso sirve para detectar el botón **BOOT** del IdeaBoard.

---

### `from ideaboard import IdeaBoard`

Carga la clase `IdeaBoard`, que simplifica mucho el control del robot.

Con esta librería puedes usar cosas como:

* `ib.motor_1.throttle`
* `ib.motor_2.throttle`
* `ib.pixel`
* `ib.AnalogIn(...)`

O sea, te facilita manejar motores, LED y entradas analógicas.

---

### `from time import sleep`

Permite pausar el programa por cierto tiempo.

Ejemplo:

```python
sleep(0.3)
```

Eso detiene el código por 0.3 segundos.

---

### `from hcsr04 import HCSR04`

Sirve para manejar el sensor ultrasónico HC-SR04.

Con eso puedes medir distancia al frente.

---

### `import random`

Se usa para escoger direcciones al azar, por ejemplo al girar izquierda o derecha en una maniobra evasiva.

---

# 2. Creación de objetos principales

```python
sonar = HCSR04(board.IO25, board.IO26)
ib = IdeaBoard()
keys = keypad.Keys((board.IO0,), value_when_pressed=False, pull=True)
```

## `sonar = HCSR04(board.IO25, board.IO26)`

Aquí creas el objeto del sensor ultrasónico.

* `IO25` y `IO26` son los pines conectados al sensor.
* Luego puedes usar:

  ```python
  sonar.dist_cm()
  ```

  para obtener la distancia en centímetros.

---

## `ib = IdeaBoard()`

Aquí creas el objeto principal del robot.

Ese objeto `ib` controla:

* motores
* LED RGB
* entradas analógicas
* otras utilidades de la placa

---

## `keys = keypad.Keys((board.IO0,), value_when_pressed=False, pull=True)`

Esta línea configura el botón BOOT.

### Qué significa cada parte

* `board.IO0`: el botón está conectado a ese pin.
* `(board.IO0,)`: se pasa como tupla, aunque solo haya un botón.
* `value_when_pressed=False`: cuando el botón se presiona, el valor lógico será `False`.
* `pull=True`: activa una resistencia pull-up interna.

## Idea importante

Este botón se usará para que el robot **espere antes de comenzar**.

---

# 3. Configuración de sensores infrarrojos

```python
sen1 = ib.AnalogIn(board.IO36)
sen2 = ib.AnalogIn(board.IO39)
sen3 = ib.AnalogIn(board.IO34)
sen4 = ib.AnalogIn(board.IO35)

infrarrojos = [sen1, sen2, sen3, sen4]
```

## Qué hace esta sección

Configura los 4 sensores infrarrojos que detectan el borde blanco del dojo.

## Distribución

* `sen1`: adelante izquierdo
* `sen2`: adelante derecho
* `sen3`: atrás izquierdo
* `sen4`: atrás derecho

## Por qué se guardan en una lista

La lista `infrarrojos` permite recorrer los sensores fácilmente con un `for` en lugar de tratarlos uno por uno.

Eso facilita funciones como:

```python
leer_sensores(infrarrojos)
```

---

# 4. Conversión de bits a entero

```python
def arreglo_a_entero(bits):
    valor = 0
    for bit in bits:
        valor = (valor << 1) | bit
    return valor
```

## Qué hace

Convierte una lista de bits en un número entero.

Por ejemplo, si `bits = [1, 0, 1, 1]`, el resultado será:

* empieza en 0
* desplaza a la izquierda y agrega cada bit
* termina en `11` en decimal

## Para qué sirve en este robot

Los sensores infrarrojos devuelven una lista como:

```python
[0, 1, 0, 0]
```

Eso representa qué sensores detectan línea o no.
Con esta función se convierte esa combinación en un único número, para tomar decisiones más fácil.

---

# 5. Lectura de sensores infrarrojos

```python
def leer_sensores(infrarrojos, valor_critico=10000):
    return [int(sen.value < valor_critico) for sen in infrarrojos]
```

## Qué hace

Lee cada sensor infrarrojo y lo convierte a:

* `1` si detecta negro
* `0` si detecta blanco

según el umbral `valor_critico`.

## Cómo funciona

Cada sensor analógico da un valor numérico.
El código compara ese valor contra `valor_critico`.

```python
sen.value < valor_critico
```

Si se cumple, devuelve `True`, y `int(True)` es `1`.
Si no, devuelve `False`, y `int(False)` es `0`.

## Resultado típico

Puede devolver algo como:

```python
[0, 0, 1, 0]
```

---

# 6. Función `on_white`

```python
def on_white(infrarrojos, valor_critico=10000):
    sensores = leer_sensores(infrarrojos, valor_critico)
    return arreglo_a_entero(sensores) > 0
```

## Qué pretende hacer

Lee los sensores y devuelve `True` si alguno detecta una condición especial.

## Ojo con el nombre

El nombre `on_white` puede confundir un poco, porque internamente depende de cómo interpretaste los valores de los sensores.

Como en tu función:

```python
int(sen.value < valor_critico)
```

el `1` representa una condición específica, entonces `on_white()` realmente depende de cómo calibraste ese umbral.
En este código no se usa después, pero parece pensada para preguntar si algún sensor detecta borde.

---

# 7. Función `line_status`

```python
def line_status(infrarrojos, valor_critico=10000):
    sensores = leer_sensores(infrarrojos, valor_critico)
    return arreglo_a_entero(sensores)
```

## Qué hace

Devuelve un número entero que representa el estado de los 4 sensores.

## Ejemplo

Si los sensores leen:

```python
[0, 0, 0, 0]
```

entonces retorna `0`.

Si leen:

```python
[0, 0, 1, 0]
```

retorna otro valor entero distinto.

## Para qué sirve

Te permite tomar decisiones según cuál sensor detectó línea.

Por ejemplo:

* `0`: ningún sensor detecta borde
* `1,2,3`: ciertos sensores traseros detectan línea
* otros valores: podría haber sensores delanteros detectando línea

Esa lógica la usas en `forwardCheck()`.

---

# 8. Funciones de movimiento

Estas funciones controlan los motores.

---

## `forward(t, speed)`

```python
def forward(t, speed):
    ib.pixel = (0, 255, 0)
    ib.motor_1.throttle = speed
    ib.motor_2.throttle = speed
    sleep(t)
```

### Qué hace

Mueve el robot hacia adelante durante `t` segundos con velocidad `speed`.

### Detalles

* enciende el LED en verde
* ambos motores van hacia adelante
* espera `t` segundos

---

## `backward(t, speed)`

```python
def backward(t, speed):
    ib.pixel = (150, 255, 0)
    ib.motor_1.throttle = -speed
    ib.motor_2.throttle = -speed
    sleep(t)
```

### Qué hace

Mueve el robot hacia atrás.

### Detalle importante

`throttle` negativo significa reversa.

---

## `left(t, speed)`

```python
def left(t, speed):
    ib.pixel = (50, 55, 100)
    ib.motor_1.throttle = -speed
    ib.motor_2.throttle = speed
    sleep(t)
```

### Qué hace

Hace girar el robot a la izquierda.

### Cómo lo logra

* un motor gira hacia atrás
* el otro hacia adelante

Eso produce una rotación sobre su eje.

---

## `right(t, speed)`

```python
def right(t, speed):
    ib.pixel = (50, 55, 100)
    ib.motor_1.throttle = speed
    ib.motor_2.throttle = -speed
    sleep(t)
```

Hace lo contrario: gira a la derecha.

---

## `stop()`

```python
def stop():
    ib.pixel = (0, 0, 0)
    ib.motor_1.throttle = 0
    ib.motor_2.throttle = 0
```

### Qué hace

Detiene completamente el robot.

### Importancia

Es clave para:

* frenar antes de medir con ultrasonido
* detenerse antes de cambiar de maniobra
* evitar movimientos no deseados

---

# 9. Función `randomTurn`

```python
def randomTurn(t, speed):
    dir = random.choice([-1, 1])
    ib.pixel = (255, 0, 0)
    ib.motor_1.throttle = dir * -speed
    ib.motor_2.throttle = dir * speed
    sleep(t)
```

## Qué hace

Escoge aleatoriamente entre girar izquierda o derecha.

## Cómo funciona

`random.choice([-1, 1])` elige:

* `-1`
* o `1`

Eso cambia el signo en la velocidad de los motores y provoca giro a un lado u otro.

## Para qué sirve

Después de detectar peligro de salir del dojo, el robot puede retroceder y luego girar en una dirección aleatoria para reubicarse.

Eso evita que siempre haga la misma maniobra.

---

# 10. Función `lookForward`

```python
def lookForward():
    stop()
    dist = sonar.dist_cm()
    sleep(0.2)
    return dist
```

## Qué hace

Mide la distancia al frente con el ultrasónico.

## Paso por paso

1. Detiene el robot.
2. Lee la distancia con:

   ```python
   sonar.dist_cm()
   ```
3. Espera un poco.
4. Retorna la distancia.

## Por qué primero hace `stop()`

Porque si el robot está vibrando o moviéndose, la medición puede ser menos estable.

---

# 11. Función `scan`

```python
def scan():
    stop()
    maxCount = 10
    count = 0
    dist = lookForward()
    while count < maxCount and (dist > 30 or dist == -1):
        left(0.2, 0.2)
        count += 1
        dist = lookForward()
    stop()
    if count == maxCount:
        return False
    else:
        return True
```

## Qué hace

Busca un oponente girando poco a poco hacia la izquierda.

## Lógica

* empieza detenido
* mide al frente
* mientras no vea nada cercano:

  * gira un poco
  * vuelve a medir
* si encuentra algo antes de llegar al máximo de intentos, retorna `True`
* si no encuentra nada, retorna `False`

## Condición de búsqueda

```python
(dist > 30 or dist == -1)
```

Significa:

* si el objeto está a más de 30 cm, todavía no está cerca
* si el sensor devuelve `-1`, no detectó nada útil

## Observación

En tu código principal esta función no se está usando todavía, pero es una buena base para una estrategia de búsqueda.

---

# 12. Función `wiggle`

```python
def wiggle(t, n, speed):
    for i in range(n):
        ...
```

## Qué hace

Hace que el robot se mueva alternando izquierda y derecha varias veces.

## Para qué puede servir

* desatascarse
* buscar al oponente
* generar movimiento agresivo
* ajustar orientación

## Cómo funciona

Dentro del `for`, el robot:

* gira a un lado
* gira al otro
* se detiene
* vuelve a girar

Es una oscilación.

---

# 13. Función `wiggle_forward`

```python
def wiggle_forward(t, n, speed):
    for i in range(n):
        ...
        forward(0.3, 1)
        ...
```

## Qué hace

Es parecida a `wiggle`, pero incluye un avance hacia adelante.

## Para qué sirve

Tu comentario lo sugiere bien: cuando detecta línea atrás, el robot puede aprovechar y lanzarse hacia adelante con fuerza, porque atrás está en riesgo pero al frente todavía puede avanzar para mantenerse en combate.

## Idea estratégica

Si los sensores traseros ven blanco, la mejor respuesta no siempre es retroceder.
A veces conviene **avanzar fuerte** para no salir por atrás.

---

# 14. Función `forwardCheck`

```python
def forwardCheck(t, speed, th):
    d = int(t / 0.01)
    for i in range(d):
        status = line_status(infrarrojos, th)
        print(status)
        if status == 0:
            forward(0.1, speed)
        elif status >= 1 and status <= 3:
            wiggle_forward(0.1, 4, 1)
        else:
            stop()
            sleep(0.3)
            backward(1, 0.3)
            randomTurn(1, 0.3)
```

## Esta es una de las funciones más importantes

Hace que el robot avance, **pero vigilando constantemente los sensores IR** para no salirse del dojo.

---

## Paso 1: dividir el tiempo

```python
d = int(t / 0.01)
```

Divide el tiempo `t` en pequeños pasos.

La idea es no avanzar "a ciegas" durante todo el tiempo, sino revisar los sensores frecuentemente.

---

## Paso 2: revisar sensores en cada iteración

```python
status = line_status(infrarrojos, th)
print(status)
```

Lee el patrón de sensores y lo imprime para depuración.

---

## Caso 1: `status == 0`

```python
if status == 0:
    forward(0.1, speed)
```

Significa que no se detecta línea peligrosa.
Entonces avanza.

---

## Caso 2: `status >= 1 and status <= 3`

```python
elif status >= 1 and status <= 3:
    wiggle_forward(0.1, 4, 1)
```

Según tu lógica, esto representa que se detectó línea atrás.

Entonces el robot hace una maniobra agresiva hacia adelante.

---

## Caso 3: cualquier otro caso

```python
else:
    stop()
    sleep(0.3)
    backward(1, 0.3)
    randomTurn(1, 0.3)
```

Aquí el robot interpreta una situación de riesgo más seria, posiblemente línea al frente o combinación peligrosa.

Entonces:

1. se detiene
2. espera un poco
3. retrocede
4. gira aleatoriamente

Esto busca sacarlo de la zona de peligro.

---

# 15. Función `esperar_boton`

```python
def esperar_boton():
    print("Esperando botón...")
    ib.pixel = (255, 100, 0)

    while True:
        event = keys.events.get()
        if event and event.released:
            print("Botón soltado. Iniciando...")
            ib.pixel = (0, 255, 0)
            sleep(0.2)
            ib.pixel = (0, 0, 0)
            return
```

## Qué hace

Esta función detiene el inicio del robot hasta que el botón BOOT sea:

1. presionado
2. y luego soltado

## Cómo funciona

### `keys.events.get()`

Busca un evento del botón.

Puede ser:

* presionado
* soltado
* o ninguno

### `if event and event.released:`

Solo actúa cuando detecta que el botón fue soltado.

## Por qué usar `released` y no `pressed`

Porque así el robot no arranca justo cuando lo estás tocando, sino cuando ya lo liberaste.

Eso es útil en competencia: puedes tenerlo listo y soltarlo exactamente cuando quieres iniciar.

## `return`

Cuando detecta la liberación, sale de la función y el programa continúa normalmente.

---

# 16. Variable de umbral

```python
th = 2950
```

## Qué hace

Define el umbral para los sensores infrarrojos.

Ese número separa dos condiciones:

* superficie oscura
* línea blanca

## Importancia

Este valor casi siempre necesita calibración real en tu robot, con tus sensores y tu dojo.

Si está mal calibrado:

* puede creer que está sobre blanco cuando no lo está
* o no detectar la línea a tiempo

---

# 17. Inicio del programa antes del bucle principal

```python
stop()
esperar_boton()
```

## Qué hace

Antes de arrancar:

1. detiene motores por seguridad
2. espera el botón

## Resultado

El robot queda quieto al encenderse y **solo empieza cuando sueltas el botón**.

---

# 18. Bucle principal

```python
while True:
    distancia = sonar.dist_cm()
    if distancia > -1 and distancia < 30:
        right(0.1, 0.2)
        forwardCheck(0.2, 1, th)
        stop()
        sleep(0.3)
    else:
        stop()
        sleep(0.3)
        right(0.1, 0.2)
    stop()
```

## Esta sección es la estrategia principal del robot

Se repite indefinidamente.

---

## Paso 1: medir distancia

```python
distancia = sonar.dist_cm()
```

El ultrasónico revisa si hay un objeto al frente.

---

## Caso 1: detecta algo cerca

```python
if distancia > -1 and distancia < 30:
```

Significa:

* la medición es válida (`> -1`)
* hay algo a menos de 30 cm

Probablemente un oponente.

### Entonces hace:

```python
right(0.1, 0.2)
forwardCheck(0.2, 1, th)
stop()
sleep(0.3)
```

#### `right(0.1, 0.2)`

Hace un pequeño ajuste a la derecha.

#### `forwardCheck(0.2, 1, th)`

Avanza agresivamente, pero cuidando no salirse del dojo.

#### `stop()` y `sleep(0.3)`

Se detiene un momento antes de volver a decidir.

---

## Caso 2: no detecta nada

```python
else:
    stop()
    sleep(0.3)
    right(0.1, 0.2)
```

Si no hay oponente cerca:

* se detiene
* espera
* gira un poco a la derecha

## Interpretación estratégica

Está buscando oponente girando poco a poco.

---

## `stop()` final

```python
stop()
```

Asegura que al terminar cada iteración no queden motores encendidos accidentalmente.

---

# 19. Resumen global de la estrategia

Tu robot hace esto:

1. se enciende
2. queda esperando el botón
3. cuando sueltas el botón, arranca
4. mide con ultrasónico
5. si detecta rival cerca:

   * ajusta dirección
   * avanza controlando línea
6. si no detecta rival:

   * gira para buscarlo
7. si detecta borde con IR:

   * reacciona según la posición del peligro

---

# 20. Fortalezas del código

Este código tiene varias cosas buenas:

* separa el movimiento en funciones claras
* usa el ultrasónico para buscar rival
* usa infrarrojos para no salirse
* agrega inicio con botón
* tiene maniobras de recuperación
* la lógica está modularizada

---

# 21. Cosas que podrías mejorar después

Hay varios puntos mejorables:

## A. `forwardCheck()` no revisa cada 0.01 s realmente

Aunque calculas:

```python
d = int(t / 0.01)
```

adentro llamas `forward(0.1, speed)`, que ya duerme 0.1 segundos.
Entonces la revisión no es tan rápida como parece.

---

## B. El robot gira casi siempre a la derecha

En el ciclo principal, si detecta o no detecta rival, igual hay bastante tendencia a girar a la derecha.

Podría volverse predecible.

---

## C. `scan()` está definida pero no se usa

Podrías integrarla para hacer una búsqueda más inteligente.

---

## D. El nombre `on_white()` puede ser confuso

Sería bueno renombrarla según la lógica real del sensor.

---

## E. Hay muchos `sleep()`

Eso simplifica el código, pero hace que el robot sea menos reactivo.

---

# 22. Idea conceptual del programa

En una frase:

**Este código implementa un Sumobot que espera una señal de inicio con el botón BOOT, busca oponentes con ultrasonido y evita salir del dojo usando 4 sensores infrarrojos.**

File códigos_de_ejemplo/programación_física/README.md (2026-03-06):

# Programación física del Sumobot usando sensores infrarrojos

**Fiorella Pérez López**  
Universidad CENFOTEC

---

# Introducción

Este ejemplo muestra cómo utilizar los **sensores infrarrojos del Sumobot** para implementar un sistema de **programación física del robot**.

En lugar de escribir código en una computadora para definir cada movimiento que ejecutará el robot, los estudiantes pueden **programarlo colocando patrones físicos blanco/negro bajo los sensores**.

El robot interpreta estos patrones como **códigos binarios de 4 bits** y ejecuta acciones.

Este enfoque permite introducir conceptos de programación mediante **interacción tangible**, lo que lo hace especialmente útil para **niños o estudiantes que comienzan en robótica**.

---

# ¿Qué es programación física?

La **programación física** consiste en utilizar **objetos o patrones reales** para representar instrucciones de un programa.

En este ejemplo el proceso ocurre de la siguiente manera:

- Cada patrón blanco/negro representa un **número binario**
- El robot **lee ese patrón con sensores infrarrojos**
- El robot **interpreta el código**
- El robot **ejecuta una acción**

De esta forma, los estudiantes pueden **programar el robot sin escribir código**, utilizando únicamente **patrones físicos sobre el suelo o una cuadrícula de programación**.

---

# Lectura de sensores infrarrojos

El robot utiliza **cuatro sensores infrarrojos** ubicados en la parte inferior.

Cada sensor detecta si la superficie debajo es:

- blanca
- negra

Esta información se convierte en un **bit binario**.

| Superficie | Bit |
|---|-----|
| Blanco | 1 |
| Negro | 0 |

Al utilizar **cuatro sensores**, el robot genera un **código binario de 4 bits**.

Ejemplo:

Patrón detectado:

⬜ ⬜ ⬛ ⬛

Código generado:
  **1100**

# Interpretación de códigos binarios

Cada combinación de bits corresponde a una **acción del robot**.

Los sensores infrarrojos detectan blanco o negro y generan un código de **4 bits**, el cual se interpreta como una instrucción.

## Códigos utilizados en este ejemplo

| Código | Acción |
|---|---|
| 1100 | Avanzar |
| 0011 | Retroceder |
| 1001 | Girar derecha |
| 0110 | Girar izquierda |
| 1110 | Giro 180° |
| 0101 | LED verde |
| 0010 | LED rojo |
| 0001 | LED azul |
| 0111 | Celebración |
| 0000 | Detener |
| 1111 | Iniciar programación |

---

# Posibles combinaciones no utilizadas

Un sistema de **4 bits permite 16 combinaciones posibles**.

En este ejemplo no todas las combinaciones se utilizan, lo que permite **extender el sistema con nuevas funciones**.

| Código | Posible uso futuro |
|---|---|
| 1010 | Cambiar velocidad |
| 1011 | Repetir instrucción |
| 0100 | Pausa programada |
| 1101 | Ejecutar bucle |

Estas combinaciones podrían utilizarse para **agregar nuevas capacidades al robot en futuras versiones del proyecto**.

---

# Archivos principales del proyecto

El sistema se compone de tres archivos principales.

| Archivo | Descripción |
|---|---|
| `README.md` | Documentación del proyecto y explicación del sistema |
| `robot_programable.py` | Código principal del robot con programación física |
| `prueba_sensores_ir.py` | Programa de prueba para calibrar sensores infrarrojos |

El archivo de prueba de sensores genera automáticamente un archivo llamado:
  **datos_bits.txt**
Este archivo guarda registros de lectura de sensores para **ajustar correctamente los umbrales de detección de blanco y negro**.

### Ejemplo de contenido generado en `datos_bits.txt`

```txt
------ Lectura de sensores ------
Sensor 1 (Delantero izquierdo) : valor=2581 -> bit=1
Sensor 2 (Delantero derecho)   : valor=62655 -> bit=0
Sensor 3 (Trasero izquierdo)   : valor=31357 -> bit=0
Sensor 4 (Trasero derecho)     : valor=2819 -> bit=1
Combinación binaria detectada: 1001
---------------------------------

------ Lectura de sensores ------
Sensor 1 (Delantero izquierdo) : valor=2561 -> bit=1
Sensor 2 (Delantero derecho)   : valor=62655 -> bit=0
Sensor 3 (Trasero izquierdo)   : valor=31218 -> bit=0
Sensor 4 (Trasero derecho)     : valor=2819 -> bit=1
Combinación binaria detectada: 1001
---------------------------------

------ Lectura de sensores ------
Sensor 1 (Delantero izquierdo) : valor=2541 -> bit=1
Sensor 2 (Delantero derecho)   : valor=62377 -> bit=0
Sensor 3 (Trasero izquierdo)   : valor=2819 -> bit=1
Sensor 4 (Trasero derecho)     : valor=2819 -> bit=1
Combinación binaria detectada: 1011
---------------------------------

------ Lectura de sensores ------
Sensor 1 (Delantero izquierdo) : valor=2541 -> bit=1
Sensor 2 (Delantero derecho)   : valor=62417 -> bit=0
Sensor 3 (Trasero izquierdo)   : valor=2819 -> bit=1
Sensor 4 (Trasero derecho)     : valor=2819 -> bit=1
Combinación binaria detectada: 1011
---------------------------------

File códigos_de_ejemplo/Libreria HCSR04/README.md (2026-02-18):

# Archivos `.mpy` 🐍

Los archivos `.mpy` son archivos de código precompilado utilizados por **MicroPython** y **CircuitPython**.  
Funcionan como módulos o librerías convencionales de Python, pero al estar precompilados, su ejecución es más rápida en un microcontrolador en comparación con un archivo `.py` convencional.  
Sin embargo, debido a su naturaleza, presentan ciertas **limitaciones e incompatibilidades**.

---

## Incompatibilidad entre versiones

### **CircuitPython**

En CircuitPython existen dos versiones mayores al momento de escribir esto: **9.x y 10.x**.
El bytecode entre estas dos versiones es igual, por lo que una libreria `.mpy` para **Circuitpython 9.x** funcionará de la misma forma y sin problemas en una instalación de **Circuitpython 10.x**.

##### Versiones de Legado, Circuitpython
Algunas placas pueden estar usando una versión de legado de Circuitpython, como las versiones **8.x**
Un archivo `.mpy` compilado para una versión **8.x**, **no** funcionará en una instalación de **9.x** o superior. 
Recomendamos actualizar el firmware de la placa a una versión mas reciente.

Si intentas ejecutar un código que importa un archivo `.mpy` incompatible, aparecerá el siguiente error:

```
incompatible .mpy file
```
(O su equivalente en el idioma de tu firmware).

### **MicroPython**

Si estás usando **MicroPython**, consulta la siguiente tabla de compatibilidad entre versiones:

| Versión de MicroPython | Versión de `.mpy` |
|---|---|
| v1.23.0 y posteriores  | 6.3 |
| v1.22.x | 6.2 |
| v1.20 - v1.21.0 | 6.1 |
| v1.19.x | 6 |
| v1.12 - v1.18 | 5 |
| v1.11 | 4 |
| v1.9.3 - v1.10 | 3 |
| v1.9 - v1.9.2 | 2 |
| v1.5.1 - v1.8.7 | 0 |

[Fuente](https://docs.micropython.org/en/latest/reference/mpyfiles.html)

---

## **¿Cómo saber qué versión usar?**

### **CircuitPython**
Al conectar tu dispositivo con CircuitPython a **Thonny** u otro IDE para acceder al REPL, deberías ver un mensaje similar a este en la consola:

``` python
]0;🐍Wi-Fi: apagado | REPL | 8.2.0\

Adafruit CircuitPython 8.2.0 on 2023-07-05; CRCibernetica IdeaBoard with ESP32
```

En este caso, la versión es **8.2.0**, por lo que se debe usar un archivo `.mpy` compatible con **8.x**.  
Lo importante es el primer número: por ejemplo, si la versión fuera **10.0.3**, se necesitaría un archivo `.mpy` de **9.x** o **10.x**.

## **MicroPython**
Cuando accedas al REPL de micropython escribe el siguiente código y presiona *Enter*.

``` python
import os
print(os.uname())
```

Una vez hecho esto un mensaje como este deberá aparecer:

```python
(sysname='esp32', nodename='esp32', release='1.25.0-preview', version='8987b39e0 on 2025-02-18', machine="CRCibernetica's IdeaBoard with ESP32-WROOM-32E")
```
Aquí, `release` indica la versión de micropython que está corriendo el microcontrolador. [Ver la tabla de compatibilidad de MicroPython](#tabla-compatibilidad)

## Incompatibilidad entre **CircuitPython** y **MicroPython**

Aunque **CircuitPython** es un proyecto hijo de **MicroPython**, los archivos `.mpy` **no son compatibles entre ambas plataformas** debido a diferencias en el formato de bytecode y en la máquina virtual subyacente.

Si vas a implementar o utilizar una librería para un dispositivo, **siempre verifica si está diseñada para CircuitPython o MicroPython**, ya que usar un `.mpy` de una plataforma en la otra causará errores.

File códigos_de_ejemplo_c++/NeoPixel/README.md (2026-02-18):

# 💡 NeoPixel (ESP32) — Control de colores por comandos desde el Monitor Serial

**Autora:** Fiorella Pérez López  
**Universidad CENFOTEC**

Este programa permite **controlar un LED NeoPixel (RGB direccionable)** escribiendo **comandos de texto** desde el **Monitor Serial**.

Es ideal para aprender:
- Uso básico de **LEDs RGB**
- Comunicación **Serial**
- Uso de **librerías externas**
- Cómo interpretar comandos escritos por el usuario

El LED cambia de color según la palabra que se escriba, lo que lo hace muy intuitivo y visual 🎨✨

---

## 🧠 ¿Qué hace este código?

El programa espera que el usuario escriba un **color** en el Monitor Serial.

Cuando recibe un comando:
- Cambia el color del LED NeoPixel
- Muestra mensajes de ayuda si el comando no existe
- Permite apagar el LED y **detener el programa** escribiendo `STOP`

---

## 📚 Librerías utilizadas

Este proyecto usa una librería externa:

### Adafruit NeoPixel
```cpp
#include <Adafruit_NeoPixel.h>
```

### Cómo instalarla
1. Abre **Arduino IDE**
2. Ve a **Sketch → Include Library → Manage Libraries**
3. Busca **Adafruit NeoPixel**
4. Instálala

---

## 🎯 Comandos disponibles

Desde el **Monitor Serial**, escribe uno de estos comandos y presiona **Enter**:

| Comando | Color |
|---|---|
| `rojo` | 🔴 Rojo |
| `verde` | 🟢 Verde |
| `azul` | 🔵 Azul |
| `amarillo` | 🟡 Amarillo |
| `celeste` | 🟦 Celeste |
| `lila` | 🟣 Lila |
| `blanco` | ⚪ Blanco |
| `stop` | ⛔ Apaga el LED y detiene el programa |

👉 El programa **no distingue mayúsculas**, así que `RoJo` o `ROJO` también funcionan.

---

## 🕹️ Funciones importantes

### `setColor(r, g, b)`

Enciende el LED con un color RGB:

- `r` → rojo (0–255)
- `g` → verde (0–255)
- `b` → azul (0–255)

Ejemplo:
```cpp
setColor(255, 0, 0); // rojo
```

---

### `apagarLed()`

Apaga completamente el LED NeoPixel.

---

## ⌨️ Uso con Arduino IDE

1. Instala **Arduino IDE**
2. Instala la librería **Adafruit NeoPixel**
3. Conecta el ESP32 por USB
4. Abre `NeoPixel.ino`
5. Selecciona:
   - **Tools → Board → ESP32**
   - **Tools → Port → tu puerto**
6. Presiona **Upload**

### Para controlar el LED:
1. Abre **Serial Monitor**
2. Baud rate: **115200**
3. Escribe un comando (ejemplo: `rojo`)
4. Presiona **Enter**

---

## ❗ Errores comunes

### El LED no enciende
- Asegúrate de que la librería esté instalada

### El comando no responde
- Revisa que el baud rate sea **115200**
- Presiona **Enter** después de escribir
- Usa palabras exactas (rojo, verde, etc.)

---

## 🌟 Ideas de mejora

- Agregar más colores
- Usar números en vez de texto (`1 = rojo`, `2 = verde`, etc.)
- Controlar varios LEDs
- Cambiar brillo del LED
- Combinar con sensores o botones

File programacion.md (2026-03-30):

# Programación del Sumobot

Hay tres manera de programar el Sumobot, una es con una interfáz de bloques, una interfaz web que no requiere instalación, y otra es directamente en Python también a través del browser

> [Este video explica](https://youtu.be/lS5O-A5Uo8o?si=VfWL0nDUsuCoXepT)

## Interfaz de programación con bloques

<a href="https://ideascratch.crcibernetica.com/" target="_blank">
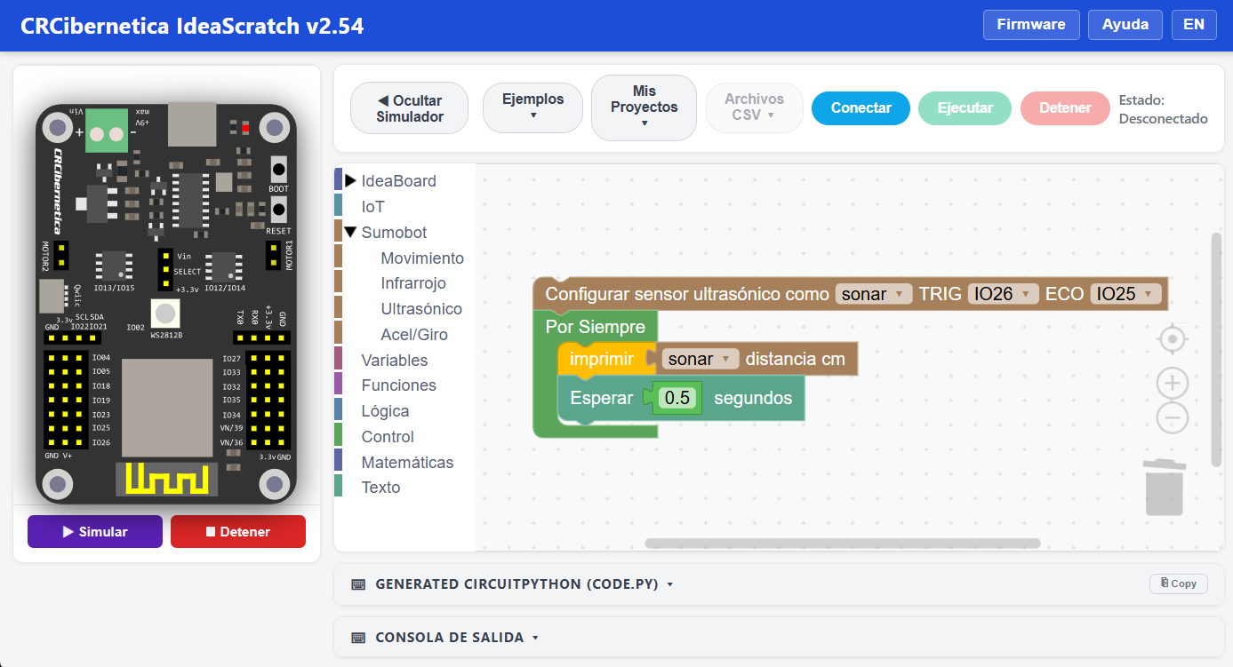
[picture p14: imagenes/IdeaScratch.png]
  
</a>

[En este link, pueden utilizar la plataforma web de programación con bloques del Sumobot](https://ideascratch.crcibernetica.com/).  No requiere instalación. Pronto publicaremos una guía básica

## Plataforma web para programar en CircuitPython el Sumobot

<a href="https://ideacode.crcibernetica.com/" target="_blank">
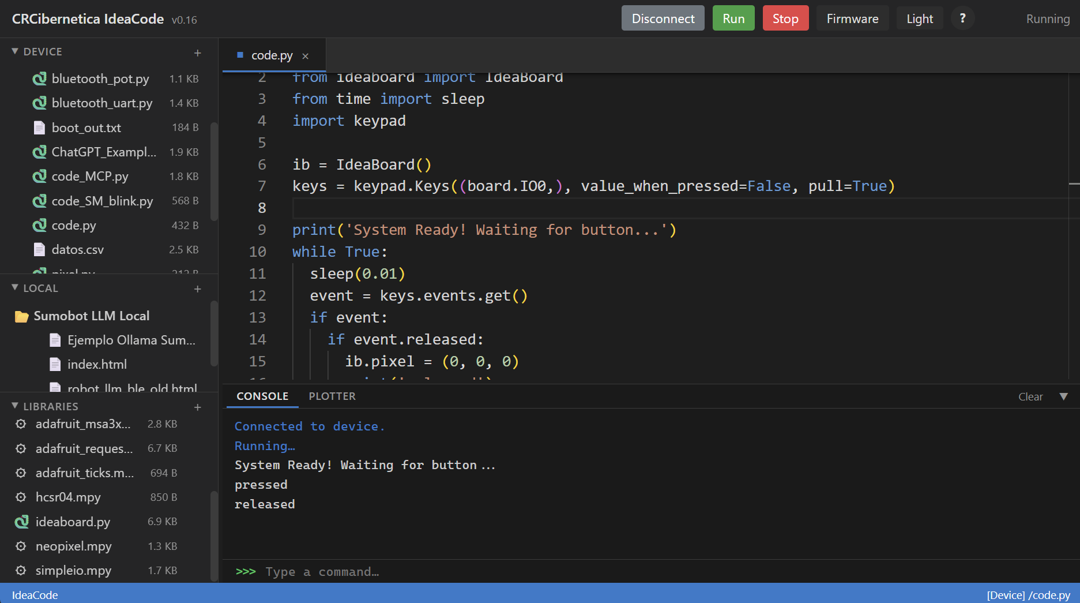
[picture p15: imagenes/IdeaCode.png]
  
</a>

[En este link, pueden utilizar la plataforma web de programación en CircuitPython del Sumobot](https://ideacode.crcibernetica.com/).  No requiere instalación. Pronto publicaremos una guía básica

> [Aistente IA para programación en Python del Sumobot](https://chatgpt.com/g/g-6863f71f27b8819192a51ed05df367b0-asistente-de-programacion-sumobot-cenfotec)

## Software para programar en CircuitPython el Sumobot y otras placas

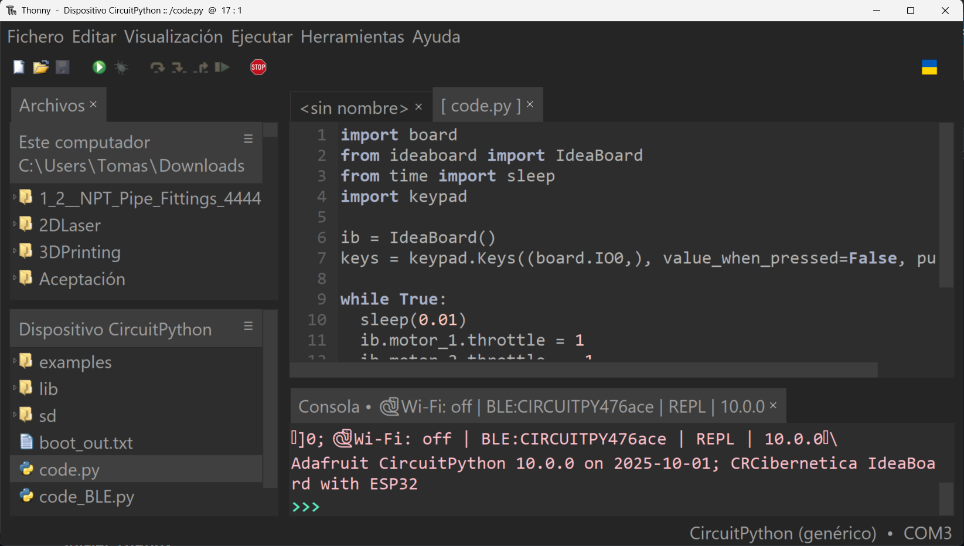
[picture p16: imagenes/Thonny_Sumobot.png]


Para programar el Sumobot se utiliza Thonny, el cual se puede descargar desde este [enlace](https://thonny.org/).

### Instrucciones Rápidas:
- Descargar la última versión de Thonny.
- Instalar.
- Una vez instalado, ir al menú "Herramientas > Opciones" o "Tools > Options" en inglés.
- En la pestaña "Intérprete" (o "Interpreter" en inglés), seleccionar "CircuitPython (Generic)".
- ¡Listo!
- [Video con detalles](https://youtu.be/Zc3oaAbVAdc)

### Instruciones más detalladas:
- [Ver este enlace](https://github.com/Universidad-Cenfotec/Sumobot/blob/main/instala_thonny.md)

### Iniciar Thonny
- [Seguir intrucciones acá](https://github.com/Universidad-Cenfotec/Sumobot/blob/main/uso_thonny.md)
- [Ver video explicativo](https://youtu.be/EOnnslZhL2c?si=IYAHV_utJocjeJvx)

##  Resetear (Flashear) el IdeaBoard

Para resetear el IdeaBoard, se hace fácilmente a través de esta página:  [IdeaBoard Flasher](https://crcibernetica.github.io/ideaboard-terminal/) Asegurese que Thonny esté CERRADO, cuando intente reflashear o el flasher no va a encontrar el puerto cn el IdeaBoard.

En [este link hay un video que explica como hacerlo](https://youtu.be/sa7HqL8b7Vo?si=5yNcEPUFerEBaM1g)

## Código

> [Puede utilizar este asistente IA para ayudar a programar el Sumobot](https://chatgpt.com/g/g-6863f71f27b8819192a51ed05df367b0-asistente-de-programacion-sumobot-cenfotec)

El código "code.py" está desarrollado en CircuitPython. CircuitPython es un subconjunto de Python desarrollado para microcontroladores y facilita la portabilidad y programabilidad de dispositivos como el ESP32, entre otros. El Sumobot ya viene preparado para trabajar con CircuitPython y no es necesario cargar archivos adicionales. Si por alguna razón se debe "reflashear" el IdeaBoard, siga las instrucciones en este [enlace](https://github.com/CRCibernetica/circuitpython-ideaboard/wiki/3.-Installation).

El código "hcsr04.mpy" corresponde a la librería para el sensor de distancia, el cual se utiliza para detectar otro robot que esté al frente del Sumobot.

Un buen punto para comenzar es [este código](https://github.com/Universidad-Cenfotec/Sumobot/blob/main/c%C3%B3digos_de_ejemplo/code_scan.py).  En el el robot busca al enemigo, si lo encuentra ataca, y mantiene revisando si se sale del dojo.  Este código tiene mucho para mejorar pero les da un comienzo útil

### Funciones Básicas

- **wiggle(t, n, speed):** Hace que el bot se mueva de izquierda a derecha durante _t_ segundos, a velocidad _speed_, repitiéndolo _n_ veces.
- **forward(t, speed):** Mueve el bot hacia adelante durante _t_ segundos a velocidad _speed_.
- **backward(t, speed):** Mueve el bot hacia atrás durante _t_ segundos a velocidad _speed_.
- **left(t, speed):** Mueve el bot hacia la izquierda durante _t_ segundos a velocidad _speed_.
- **right(t, speed):** Mueve el bot hacia la derecha durante _t_ segundos a velocidad _speed_.
- **stop():** Detiene el bot.
- **randomTurn(t, speed):** Gira al azar a la izquierda o a la derecha durante _t_ segundos a velocidad _speed_.
- **lookForward():** Realiza la lectura del sensor ultrasónico y retorna la distancia en cm de lo que esté en frente del bot.
- **scan():** Rota hacia un lado hasta que detecta algo adelante o hasta que gire un número determinado de veces.
- **forwardCheck(t, speed):** Mueve hacia adelante, pero verifica, mediante el sensor IR, que no se salga del dojo. Cuando detecta el borde, realiza un movimiento hacia atrás y luego gira.

### Recuperar la configuración inicial

Si por alguna razón se desea resetear el Sumobot a los archivos iniciales, cargue, a través de Thonny en el dispositivo CircuitPython (con el Sumobot conectado), todos los archivos que vienen en el archivo ZIP "SumoBot_Device_Files.zip".

---

## Videos Instructivos de Programación

Constantemente estaremos actualizando links cuando se vayan creando más videos:

- [Instalación de Thonny](https://youtu.be/Zc3oaAbVAdc?si=447Po0KyL_0hDAhJ)
- [Programación del Sumobot con Thonny](https://youtu.be/EOnnslZhL2c?si=rmjno9d8OHmJu21c)
- [Programación del NeoPixel](https://youtu.be/4abUHAFZwrY?si=RmHJYj71lK2cA2_J)
- [Programación de sensores Infrarrojos](https://youtu.be/1eArcnWW8Ek?si=TjnI8ONcFrolIb8A)
- [Programación de Motores](https://youtu.be/UMIWmT1n-kc?si=BwKY2DNXiGDF-0Ws)
- [Programación de Sensor Ultrasónico](https://youtu.be/RwY2lEPkyg8?si=KfbUV8WfN8I7yd2R)

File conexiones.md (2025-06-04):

# Conexiones del Sumobot

## Baterías

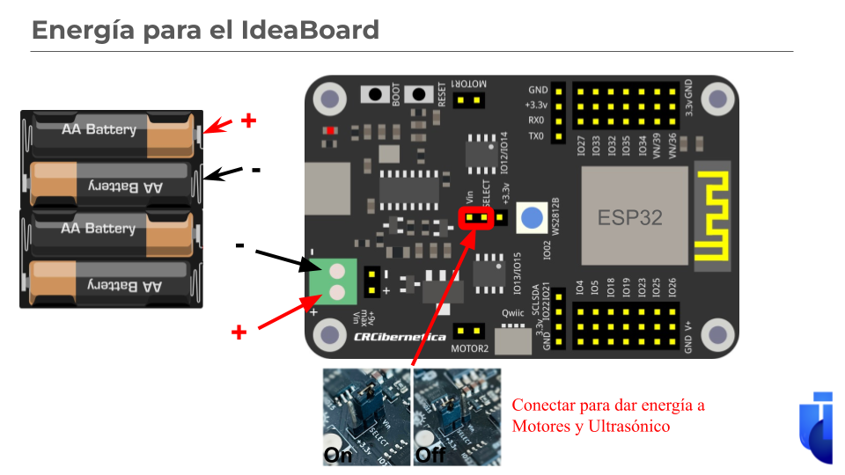
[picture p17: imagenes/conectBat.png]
bat


## Cable Qwiic

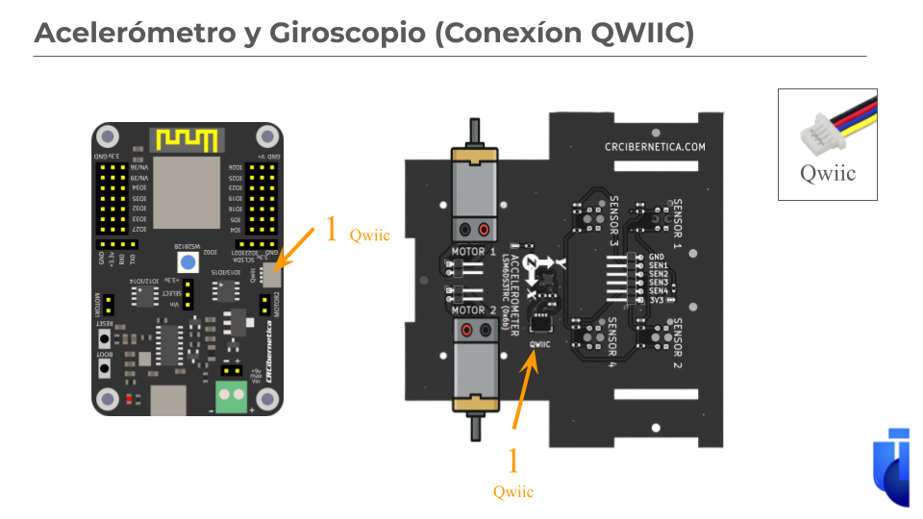
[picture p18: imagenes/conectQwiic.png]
qwiic


## Sensor Ultrasónico

Para que funcione el sensor Ultrasónico debe estar el "jumper" entre "SELECT" y "Vin"

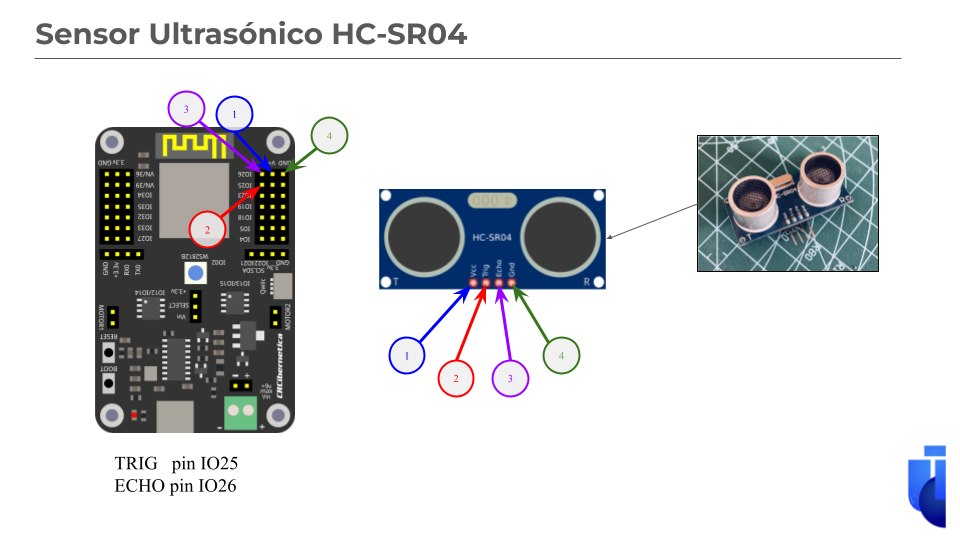
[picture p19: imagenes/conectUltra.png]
ultra


## Sesnsores Infrarrojos

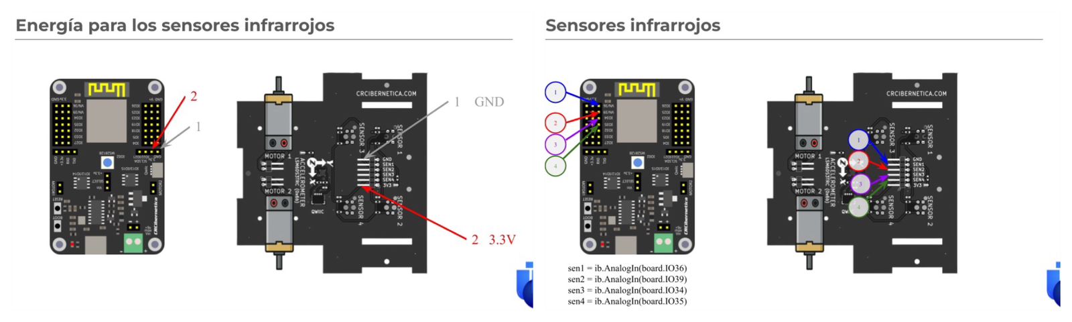
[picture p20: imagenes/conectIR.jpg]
IR


## Motores

Para que funcionen los motores debe estar el "jumper" entre "SELECT" y "Vin". Pruebe los motores moviéndolos hacia adelante, si alguno se mueve alrevés, simplemente cambie los cables 1 y 2 para el motor 1 o 3 y 4 para el motor 2

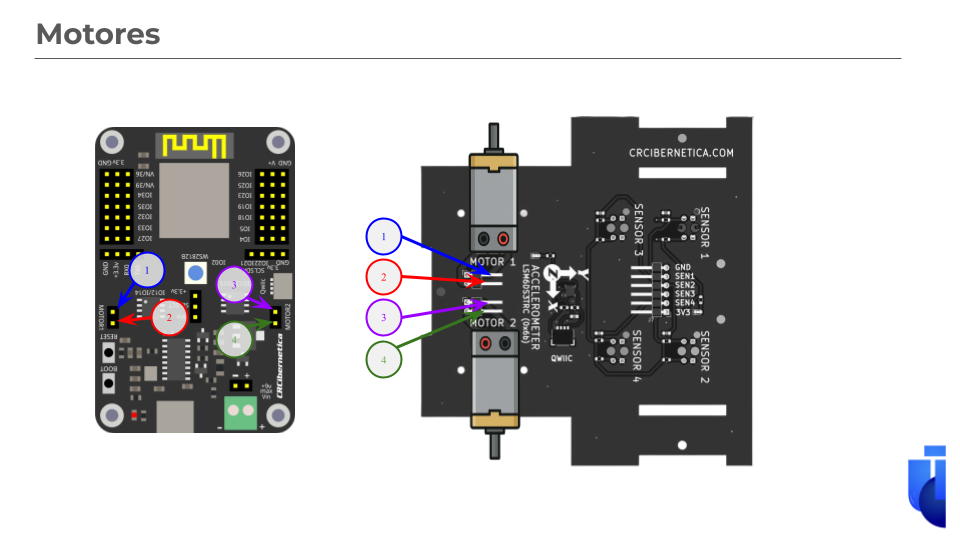
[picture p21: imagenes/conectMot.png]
mot


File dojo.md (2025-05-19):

# Espedificaciones del dojo

La siguiente imágen muestra las especificaciones del Dojo  

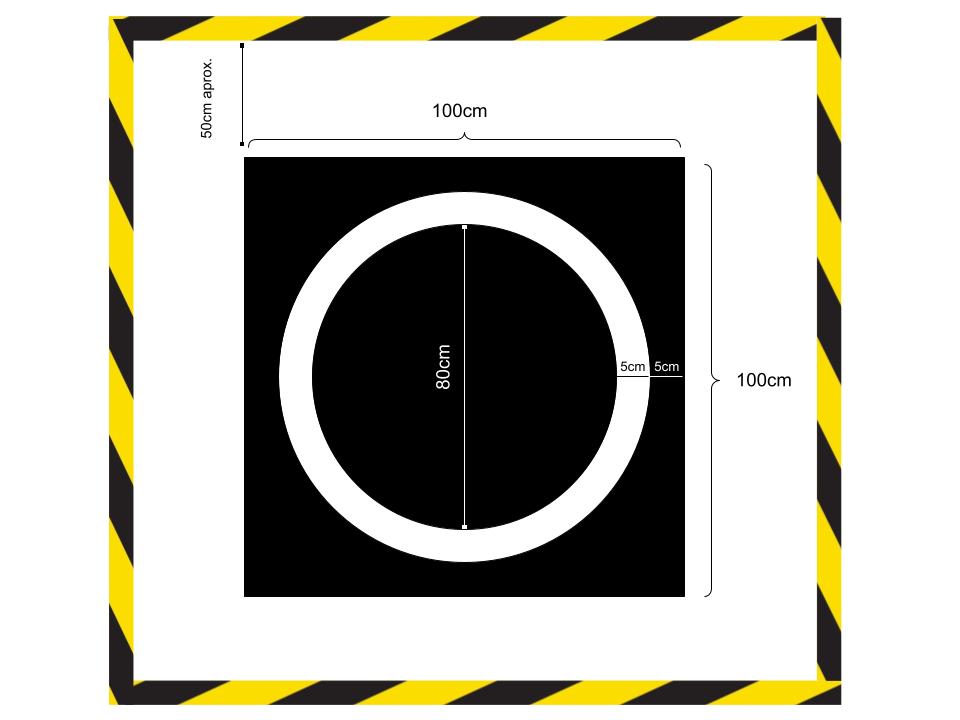
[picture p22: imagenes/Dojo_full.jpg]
dojo


El área de competencia, conocida como **dojo**, está definida para nuestro formato de competencia, y no necesariamente corresponde a torneos internacionales.  Fue ajustada para poder hacer del torneo algo divertido de aprendizaje mas que solamente de competición. A continuación se detallan sus dimensiones:

## Dimensiones Generales del Dojo:

* **Área cuadrada externa (zona negra)**:

  * **Lado**: 100 cm
  * **Color**: negro
  * Cubierta de acrílico: El dojo oficial tiene una cubierta de acrílico transparente. Esta cubierta permite una suerficie suave libre de imperfecciones para que los robots se muevan libemente (deben tener eso en cuenta para la calibración de sensores)

* **Círculo de combate (interior del anillo blanco)**:

  * **Diámetro exterior**: 90 cm
  * **Ancho del borde blanco**: 5 cm
  * **Diámetro interior**: 80 cm
  * **Color del borde**: blanco brillante para fácil detección por sensores

* **Zona de seguridad (marco de advertencia)**:

  * **Ancho aproximado del borde amarillo/negro**: 50 cm desde el borde del área negra
  * **Función**: delimitar el área de seguridad para jueces y público, evitar interferencia de personas con sensores, y reforzar visualmente los límites

## Notas adicionales:

* El borde blanco debe ser uniforme y claramente visible.
* La superficie debe ser plana y firme para asegurar condiciones justas de movilidad para los robots.
---
## Archivo con Dojo Oficial

- [Este es una archivo **SVG**](https://github.com/Universidad-Cenfotec/Sumobot/blob/main/archivos_de_fabricacion/Dojo_Oficial_Sumobot_CENFOTEC.svg), con el Dojo oficial que puede ser utilizado para corte e impresión
- Acá hay una versión [**PDF**](https://github.com/Universidad-Cenfotec/Sumobot/blob/main/archivos_de_fabricacion/Dojo_Oficial_Sumobot_CENFOTEC.pdf) del mismo archivo

--- 
## Construccion de Dojo de Práctica

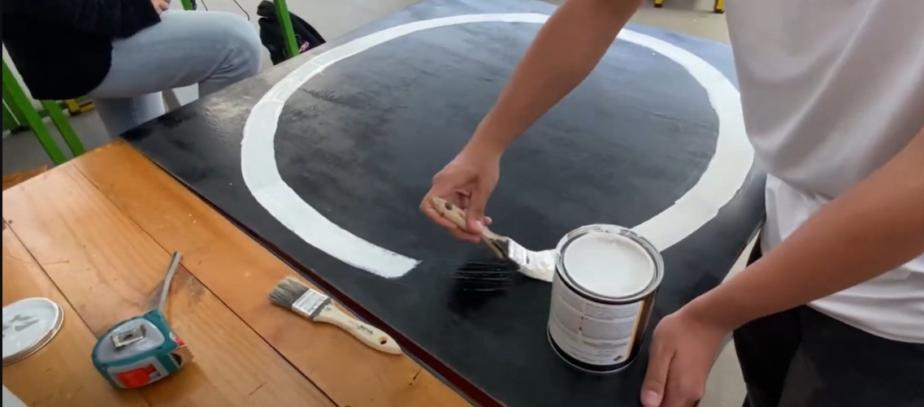
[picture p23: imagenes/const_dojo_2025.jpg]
dojo


Para practicar con los robots, se puede construir un dojo fácilmente. Estudiantes de CENFOTEC explican en este video como se puede construir un Dojo, con materiales sencillos y de bajo costo.

- [Video explicando como construir un Dojo con madera y pintura](https://youtu.be/kQZlyKjGssc?si=kFoVl_klJZuh9psP)
- [Video explicando un Dojo simple con cartulina negra y tape](https://youtu.be/-dgud9MdbUs?si=pPz8vjGYUujdG94s)

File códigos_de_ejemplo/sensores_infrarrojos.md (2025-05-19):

# Lectura de Sensores Infrarrojos como Código 4bits

Tomás de Cámino Beck, Ph.D.  
UNiversidad CENFOTEC

**Introducción**

En el código

### Explicación del Código: Lectura de 4 Sensores en un Sumobot

Código Ejemplo de lectura de 4 sensores IR:
```python
# Tomás de Camino Beck
# Universidad Cenfotec

# Importa los módulos necesarios
import board               # Permite acceder a los pines de entrada/salida del microcontrolador
from time import sleep     # Permite usar la función sleep para pausar el programa
from ideaboard import IdeaBoard   # Importa la clase IdeaBoard para controlar los sensores y actuadores

# Crea una instancia de la IdeaBoard para controlar el hardware conectado
ib = IdeaBoard()

# Configura los pines analógicos donde están conectados los sensores infrarrojos
sen1 = ib.AnalogIn(board.IO36)  # SENSOR 1 (adelante izquierdo) pin IO36
sen2 = ib.AnalogIn(board.IO39)  # SENSOR 2 (adelante derecho) pin IO39
sen3 = ib.AnalogIn(board.IO34)  # SENSOR 3 (atrás izquierdo) pin IO34
sen4 = ib.AnalogIn(board.IO35)  # SENSOR 4 (atrá derecho) pin IO35

# Crea una lista con los sensores infrarrojos para poder recorrerlos fácilmente
infrarrojos = [sen1, sen2, sen3, sen4]

#funcion que convierte a entero base 10
# Utiliza desplazamiento de bits
def arreglo_a_entero(bits):
    valor = 0
    for bit in bits:
        valor = (valor << 1) | bit
    return valor

# revisa los cuatro sensores IR, y genera un
# arreglo de 0 y 1s (0-blanco, 1-negro)
def leer_sensores(infrarrojos,valor_critico=3000):
    return [int(sen.value < valor_critico) for sen in infrarrojos]

# Bucle infinito que lee e imprime los valores de los sensores continuamente
while True: 
    estado_sensores =leer_sensores(infrarrojos,3500)
    print(estado_sensores)
    print(arreglo_a_entero(estado_sensores))
    sleep(0.1)
```

[Este código](https://github.com/Universidad-Cenfotec/Sumobot/blob/main/c%C3%B3digos_de_ejemplo/code_lecturaIR_4Bit.py) permite leer **cuatro sensores infrarrojos (IR)** colocados en las esquinas del sumobot. Estos sensores ayudan a detectar el borde del **dojo**, que normalmente es una superficie **negra con bordes blancos**. La idea es que el robot pueda **reconocer cuándo se está saliendo del área de combate** y reaccionar.

---

###  ¿Qué hace cada parte?

#### 1. **Inicialización del hardware**

```python
from ideaboard import IdeaBoard
ib = IdeaBoard()
```

Aquí se activa la placa "IdeaBoard", que nos permite controlar sensores, motores, etc.

#### 2. **Lectura de sensores**

```python
sen1 = ib.AnalogIn(board.IO36)  # Sensor frontal izquierdo
sen2 = ib.AnalogIn(board.IO39)  # Sensor frontal derecho
sen3 = ib.AnalogIn(board.IO34)  # Sensor trasero izquierdo
sen4 = ib.AnalogIn(board.IO35)  # Sensor trasero derecho
```

Cada sensor IR está conectado a un pin del microcontrolador. Estos sensores detectan **reflexión de luz**:

* **Negro (dojo)** → poca reflexión → valor **bajo**
* **Blanco (borde)** → mucha reflexión → valor **alto**

Los sensores se agrupan en una lista:

```python
infrarrojos = [sen1, sen2, sen3, sen4]
```

---

### ¿Cómo se detecta si el sensor ve negro o blanco?

```python
def leer_sensores(infrarrojos, valor_critico=3000):
    return [int(sen.value < valor_critico) for sen in infrarrojos]
```

* Si el valor del sensor es **menor que 3000**, se interpreta como **negro** (dentro del dojo), y se pone un **0**.
* Si es mayor, se interpreta como **blanco** (borde), y se pone un **1**.

Ejemplo:
Supongamos que los sensores leen:
`[negro, blanco, blanco, negro]`
→ Esto se convierte en:
`[0, 1, 0, 0]`

---

### Convertir los bits a un número entero

```python
def arreglo_a_entero(bits):
    valor = 0
    for bit in bits:
        valor = (valor << 1) | bit
    return valor
```

Este truco convierte la lista de bits `[1, 0, 0, 1]` en un número entero.
¿Cómo lo hace?

* Comienza con `valor = 0`
* Por cada bit en la lista:

  * Desplaza `valor` una posición a la izquierda (como multiplicar por 2)
  * Luego suma el bit

Ejemplo paso a paso:

```
[1, 0, 0, 1]
1) valor = 0 << 1 = 0 | 1 = 1
2) valor = 1 << 1 = 2 | 0 = 2
3) valor = 2 << 1 = 4 | 0 = 4
4) valor = 4 << 1 = 8 | 1 = 9
```

Resultado final: **9**

Entonces, el patrón `[1, 0, 0, 1]` representa el número **9**.

---

### Bucle principal

```python
while True: 
    estado_sensores = leer_sensores(infrarrojos, 3500)
    print(estado_sensores)               # Ejemplo: [1, 0, 0, 1]
    print(arreglo_a_entero(estado_sensores))  # Ejemplo: 9
    sleep(0.1)
```

Este bucle:

1. **Lee los sensores**
2. **Muestra el estado en forma de bits** (0 y 1)
3. **Convierte ese estado en un número entero**
4. **Repite cada 0.1 segundos**

---

### ¿Para qué sirve esto en el Sumobot?

* Cada **combinación de sensores** nos dice dónde está el robot con respecto al borde.
* Al convertir ese patrón en un número, el robot puede decidir **qué hacer** más fácilmente (avanzar, girar, retroceder, etc.).

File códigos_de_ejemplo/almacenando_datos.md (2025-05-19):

# Almacenando Datos en el Sumobot

Tomás de Camino Beck, Ph.D  
Universidad CENFOTEC

**Introducción**

Este documento describe el funcionamiento del programa [`code_storage.py`](https://github.com/Universidad-Cenfotec/Sumobot/blob/main/c%C3%B3digos_de_ejemplo/code_storage.py), un ejemplo práctico diseñado para enseñar a estudiantes de colegio cómo **registrar y almacenar datos de sensores en un robot** utilizando un microcontrolador con ESP32.

El objetivo principal de este código es que los estudiantes aprendan a **medir información del entorno** (como la distancia a un objeto usando un sensor ultrasónico) y a **guardar esos datos en un archivo** dentro del robot. Esta técnica es fundamental para:

* **Analizar patrones de movimiento.**
* **Estudiar el entorno del robot.**
* **Diseñar estrategias y planificar comportamientos autónomos.**

Se hace un ejemplo con el sensor ultrasónico que mide la distancia a un objeto, y el programa guarda estas mediciones repetidamente en un archivo llamado `datos.csv`. Esta recopilación de datos puede luego ser descargada y analizada con herramientas como Excel o Python, permitiendo a los estudiantes observar cómo se comporta el robot y cómo reacciona a su entorno.

El código está pensado como punto de partida para desarrollar ideas más avanzadas, como navegación inteligente, reconocimiento de obstáculos o toma de decisiones basada en datos reales. Los estudiantes pueden modificarlo para registrar otras variables, como velocidad, giros o estados internos del robot.

---

## ¿Qué hace este código?

Este código permite que un **robot con un ESP32 y un sensor ultrasónico** mida distancias y guarde esos datos en un archivo llamado `datos.csv`. De esta forma, el robot puede “recordar” lo que midió para que después un humano analice esa información.

Es como si el robot llevara un cuaderno de apuntes y escribiera en él la distancia que ve hacia adelante, una y otra vez.

---

## Explicación paso a paso

### 1. **Importación de librerías**

```python
import board
import time
import os
from ideaboard import IdeaBoard
```

Estas líneas cargan funciones necesarias para usar el hardware:

* `board`: para acceder a los pines del ESP32.
* `time`: para usar pausas (como `sleep()`).
* `os`: para manipular archivos.
* `IdeaBoard`: es la clase que permite controlar sensores y motores conectados a la placa.

---

### 2. **Inicializar la placa y abrir el archivo**

```python
ib = IdeaBoard()
file = open("/datos.csv", "w")
file.write("tiempo,distancia\n")
```

* Se crea una conexión con la **IdeaBoard**.
* Se abre (o crea) un archivo `datos.csv` para escribir los datos.
* Se escribe la primera línea del archivo, que es el **encabezado**: `"tiempo,distancia"` (esto es útil si después se analiza con Excel o Google Sheets).

---

### 3. **Bucle principal**

```python
for i in range(100):
    distancia = ib.ultrasonic()
    tiempo_actual = time.monotonic()
    file.write(f"{tiempo_actual},{distancia}\n")
    print(f"Distancia: {distancia} cm")
    time.sleep(0.1)
```

Esto se repite 100 veces:

* `ib.ultrasonic()` mide la distancia con el sensor ultrasónico (en centímetros).
* `time.monotonic()` obtiene el tiempo en segundos desde que el código empezó a correr.
* `file.write(...)` guarda el tiempo y la distancia en el archivo, separados por una coma.
* `print(...)` muestra la distancia en la consola (opcional para monitorear).
* `time.sleep(0.1)` espera 0.1 segundos (100 milisegundos) antes de volver a medir.

**Así el robot mide 100 veces durante 10 segundos aproximadamente.**

---

### 4. **Cerrar el archivo**

```python
file.close()
```

Esto es muy importante. Cierra el archivo para que todos los datos se guarden correctamente.

---

## ¿Y luego qué se hace con `datos.csv`?

Este archivo se puede descargar desde el robot a una computadora y abrir con herramientas como:

* **Excel** o **Google Sheets** → Para hacer gráficos de distancia vs tiempo.
* **Python** con pandas y matplotlib → Para hacer análisis más avanzados.

---

## ¿Para qué sirve esto en robótica?

* Observar cómo varía la distancia cuando el robot se mueve.
* Detectar patrones (por ejemplo: “cada 3 segundos hay un obstáculo”).
* Ver cómo responde el sensor a diferentes objetos o ambientes.
* Planificar rutas más eficientes o programar reacciones automáticas.

---

## Resumen visual

| Parte del código | ¿Qué hace? |
| --- | --- |
| `ib.ultrasonic()`  | Mide la distancia al frente |
| `time.monotonic()` | Registra cuánto tiempo ha pasado |
| `file.write(...)`  | Guarda tiempo y distancia en un archivo |
| `file.close()` | Finaliza y asegura el guardado del archivo |

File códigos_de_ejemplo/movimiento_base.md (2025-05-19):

# Código Base para el Sumobot

Tomás de Camino Beck, Ph.D  
Universidad CENFOTEC

Se explica detalladamente ["code_scan.py"](https://github.com/Universidad-Cenfotec/Sumobot/blob/main/c%C3%B3digos_de_ejemplo/code_scan.py) que sirve de base para comenzar a planear más estrategias del sumobot.  A partir de este código pueden ènsar en estrategias de ataque, de defensa, en diferentes posiciones de inicio, etc.

##  **Explicación general de las funciones (antes del `while True:`)**

Estas funciones preparan al robot para **moverse**, **detectar el borde del dojo con sensores infrarrojos** y **detectar al enemigo con un sensor ultrasónico**:

* **`arreglo_a_entero(bits)`**: convierte una lista de ceros y unos (de sensores IR) a un número binario en base 10. Así se representa fácilmente qué sensores detectan negro o blanco.

* **`leer_sensores()`**: lee los 4 sensores infrarrojos. Devuelve 1 si detecta blanco (borde), 0 si detecta negro (dentro del dojo).

* **`on_white()`**: retorna `True` si al menos un sensor detecta blanco (está tocando el borde).

* **`line_status()`**: devuelve el número entero que representa el estado de los sensores IR. Permite saber la posición del robot respecto al borde.

* **Funciones de movimiento (`forward()`, `backward()`, `left()`, `right()`)**: hacen que el robot se mueva en distintas direcciones por cierto tiempo y velocidad.

* **`stop()`**: detiene el robot.

* **`randomTurn()`**: gira en una dirección aleatoria (izquierda o derecha).

* **`wiggle()`**: "sacude" el robot moviéndolo rápido a los lados, útil para provocar al enemigo o moverse si está atascado.

* **`lookForward()`**: usa el sensor ultrasónico para medir qué tan lejos está el objeto al frente.

* **`scan()`**: hace que el robot gire poco a poco hasta encontrar un objeto frente a él (el enemigo). Si no lo encuentra después de 10 giros pequeños, devuelve `False`.

* **`forwardCheck()`**: avanza con cuidado **verificando constantemente los sensores infrarrojos**. Si detecta borde blanco, **reacciona retrocediendo y girando aleatoriamente**.

---

## **Explicación detallada del código principal**

Este es el **bucle principal**, donde el robot entra en acción constantemente:

```python
while True:
```

El robot repite las siguientes acciones **infinitamente** (hasta que se apague):

1. **Mide la distancia al frente** con el sensor ultrasónico:

   ```python
   distancia = sonar.dist_cm()
   ```

   * Si hay un objeto (otro robot) **a menos de 30 cm**, y no es una lectura inválida (`-1`):

     ```python
     if (distancia > -1 and distancia < 30):
     ```

     * Llama a `forwardCheck(0.2, 1, th)`, que avanza 0.2 segundos a velocidad máxima, **pero siempre verificando con sensores IR que no se salga del dojo**.
     * Luego se detiene y espera 0.3 segundos.

     ```python
     forwardCheck(0.2,1,th)
     stop()
     sleep(0.3)
     ```

2. **Si no detecta al enemigo**:

   ```python
   else:
       stop()
       sleep(0.3)
       right(0.1,0.2)
   ```

   * El robot se detiene, espera un poco y luego **gira a la derecha lentamente** para buscar al oponente.
   * Esto simula que está “escaneando” el entorno en busca de otro robot.

3. Al final de cada ciclo se asegura de que el robot esté en pausa un instante:

   ```python
   stop()
   ```

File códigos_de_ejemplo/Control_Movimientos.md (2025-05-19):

# Control de Movimientos Usando PDI y Giroscopio

Creado por Tomás de Camino Beck, Ph.D.  
Universidad CEFOTEC

**Introducción**

Este documento presenta una explicación del código [**`code_PDI.py`**](https://github.com/Universidad-Cenfotec/Sumobot/blob/main/c%C3%B3digos_de_ejemplo/code_PDI.py), diseñado como una herramienta educativa para introducir conceptos básicos de teoría de control aplicada a la robótica. Se trata de un código en desarrollo, pensado para ser utilizado como punto de partida en la construcción de robots móviles capaces de navegar de manera más precisa.

El objetivo principal es que los estudiantes comprendan cómo ajustar y experimentar con diferentes parámetros de control para lograr un movimiento estable y eficiente. Aunque el código simplifica muchos aspectos del comportamiento real de un robot, ofrece una base sólida para aprender sobre navegación, sensores y sistemas de control como el **PDI (Proporcional, Derivativo e Integral)**.

Es importante destacar que este programa requiere ajustes para adaptarse a cada robot específico. Parte del aprendizaje consiste en enfrentar este reto, probando, midiendo y afinando el comportamiento del robot. Por ello, se recomienda que los estudiantes participen activamente en la mejora y personalización del código.

---

## ¿Qué hace este programa?

Este programa controla un robot con dos ruedas usando una placa **ESP32** y un sensor llamado **giroscopio** (en este caso, el sensor LSM6DS3TRC). Tiene dos funciones principales:

* **Girar un ángulo exacto**.
* **Moverse en línea recta sin desviarse**.

---

## ¿Qué es un giroscopio?

El **giroscopio** mide qué tan rápido está girando el robot. Se mide en radianes por segundo (rad/s), como si dijera “estás girando a la derecha o izquierda a tal velocidad”. Usando esta información, el robot puede calcular cuánto ha girado, ¡sin necesidad de sensores externos!

---

## ¿Qué es el “drift”?

El **drift** es como un pequeño error constante que tiene el sensor. Si el robot está quieto, el sensor debería decir “0”, pero a veces da un número pequeño distinto de cero. Por eso, se mide el **drift al inicio** y luego se resta cada vez que usamos el giroscopio.

```python
drift = calibrar_drift(sensor, 5)
```

Esto mide el error promedio durante 5 segundos.

---

## ¿Cómo gira el robot exactamente?

La función `girar_grados(sensor, grados, drift)` hace que el robot gire una cantidad específica de grados. Lo hace así:

1. Enciende los motores en direcciones opuestas para que el robot gire.
2. Usa el giroscopio para ir sumando cuánto ha girado.
3. Cuando se acerca al final, **desacelera** para no pasarse.
4. Se detiene exactamente cuando ha girado lo necesario.

Esto se parece a cómo giramos nosotros para mirar algo exacto: primero rápido, luego despacio al acercarse al ángulo deseado.

---

## ¿Cómo avanza recto?

La función `straight_move(velocidad, duracion, drift)` hace que el robot avance en línea recta por cierto tiempo. Pero si un motor va un poquito más rápido que el otro, el robot se desviaría. Aquí entra en juego el **control PDI**.

---

## ¿Qué es el control PDI? (Explicación sencilla)

Un control **PDI** (Proporcional, Derivativo e Integral) es como un pequeño "cerebro matemático" que:

* **P (Proporcional):** Corrige según cuánto se está desviando ahora.
* **D (Derivativo):** Corrige si la desviación está aumentando muy rápido.
* **I (Integral):** Corrige errores acumulados con el tiempo.

Así, el robot **corrige en tiempo real** su rumbo. Si empieza a girar un poco hacia un lado, ajusta la velocidad de cada motor para seguir recto.

Ejemplo de vida real: imagina que caminas en línea recta con los ojos cerrados. Al mínimo desvío, mueves un poco tus pies para corregir. Eso es un control PDI.

---

## ¿Qué hace el programa al final?

En la parte principal (`while True:`):

1. Calibra el sensor de giroscopio.
2. Avanza recto 5 segundos.
3. Espera 1 segundo y repite.

Esto permite probar que el robot va recto gracias al giroscopio y al control PDI.

---

## Resumen visual:

| Parte del código | ¿Qué hace? |
| --- | --- |
| `calibrar_drift()` | Mide el error del giroscopio estando quieto |
| `girar_grados()` | Gira una cantidad precisa de grados |
| `straight_move()`  | Avanza en línea recta corrigiendo el rumbo  |
| `sensor.gyro[2]` | Mide el giro en el plano del robot |
| `PDI` | Controla corrección con matemáticas simples |

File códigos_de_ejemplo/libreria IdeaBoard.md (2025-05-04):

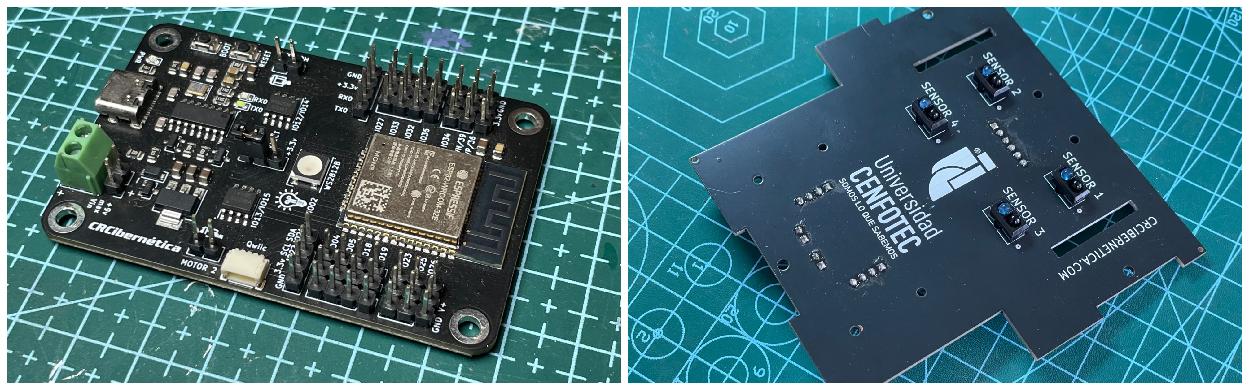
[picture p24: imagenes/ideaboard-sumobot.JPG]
SumoBot
 

# Uso de la librería IdeaBoard

El Sumobot utiliza la placa IdeaBoard, que es una placa que utiliza el ESP32, pero agrega drivers de motores, y pines para poder conectar gran cantidad de sensores digitales y analógicos.

Esta guía explica cómo utilizar la librería **IdeaBoard**, que incluye funciones para:

- Controlar los motores incorporados
- Cambiar el color del LED RGB
- Controlar servomotores
- Leer entradas digitales y analógicas
- Generar salidas digitales y analógicas
- Utilizar una función especial llamada `map_range` para ajustar valores entre distintos rangos

> **Nota**: Este documento es una traducción con modificación del documento de apoyo del IdeaBoard. Mayores detalles, los pueden [encontrar acá](https://github.com/CRCibernetica/circuitpython-ideaboard/wiki)

---

## Introducción

Para comenzar a usar las funciones de la IdeaBoard, primero debemos crear un objeto que nos permitirá acceder a todas sus funcionalidades.

```python
from ideaboard import IdeaBoard

ib = IdeaBoard()
````

---

## Control de motores

La IdeaBoard tiene dos motores llamados `motor_1` y `motor_2`. Estos se controlan con la propiedad **throttle**.

* `1.0` significa velocidad máxima hacia adelante
* `-1.0` significa velocidad máxima hacia atrás
* `0` detiene el motor con freno
* `None` deja el motor libre (sin freno)

Ejemplo:

```python
from ideaboard import IdeaBoard

ib = IdeaBoard()

ib.motor_1.throttle = 1.0  # Avanzar
ib.motor_2.throttle = -1.0 # Retroceder
```

---

## LED RGB (Neopixel)

La IdeaBoard tiene un LED de colores. Puedes encenderlo con diferentes colores usando `ib.pixel`.

Los colores se definen como una combinación de Rojo (R), Verde (G) y Azul (B), con valores entre 0 y 255.

Ejemplo:

```python
from ideaboard import IdeaBoard

ib = IdeaBoard()

ib.brightness = 0.2  # Ajusta la intensidad del brillo (0.0 a 1.0)

# Definir colores
AZUL = (0, 0, 255)
VERDE = (0, 255, 0)
ROJO = (255, 0, 0)

ib.pixel = AZUL  # Enciende el LED en azul
```

### Efecto arcoiris

El efecto arcoiris permite mostrar colores de manera cíclica usando valores entre 0 y 255.

```python
from ideaboard import IdeaBoard
from time import sleep

ib = IdeaBoard()

while True:
    for i in range(256):
        ib.arcoiris = i
        sleep(0.01)
```

---

## Servomotores

Los servos permiten mover objetos a posiciones precisas. Se controlan usando el ángulo entre **0** y **180** grados.

Ejemplo:

```python
import board
from ideaboard import IdeaBoard
from time import sleep

ib = IdeaBoard()

servo1 = ib.Servo(board.IO4)

while True:
    servo1.angle = 10   # Mover a 10 grados
    sleep(2)
    servo1.angle = 170  # Mover a 170 grados
    sleep(2)
```

---

## Entradas digitales (Digital In)

Esto te permite **leer botones o sensores digitales** (encendido/apagado).

* `pull=ib.UP` o `pull=ib.DOWN` configuran resistencias internas para estabilizar la señal (opcional).
* `.value` devuelve el estado actual (True o False).

Ejemplo:

```python
import board
import time
from ideaboard import IdeaBoard

ib = IdeaBoard()

entrada = ib.DigitalIn(board.IO27)

while True:
    print(entrada.value)
    time.sleep(0.5)
```

---

## Salidas digitales (Digital Out)

Esto se usa para **encender o apagar dispositivos** como LEDs o relés.

* `.value = True` activa la salida
* `.value = False` apaga la salida

Ejemplo:

```python
import board
import time
from ideaboard import IdeaBoard

ib = IdeaBoard()

salida = ib.DigitalOut(board.IO27)

while True:
    salida.value = True   # Encender
    time.sleep(0.5)
    salida.value = False  # Apagar
    time.sleep(0.5)
```

---

## Entradas analógicas (Analog In)

Permite **leer sensores analógicos** como potenciómetros.

* `.value` devuelve un número de 0 a 65535 que representa la lectura del sensor.

Ejemplo:

```python
import board
import time
from ideaboard import IdeaBoard

ib = IdeaBoard()

entrada = ib.AnalogIn(board.IO33)

while True:
    print(entrada.value)
    time.sleep(0.5)
```

---

## Salidas analógicas (Analog Out)

Puedes **generar señales analógicas** (0 a 3.3V) para controlar dispositivos como luces LED suavemente.

> Solo los pines `board.IO25` y `board.IO26` permiten salida analógica.

Ejemplo:

```python
import time
import board
from ideaboard import IdeaBoard

ib = IdeaBoard()

dac = ib.AnalogOut(board.IO26)

dac.value = 32768  # Produce aproximadamente 1.60V en el pin IO26
```

---

## Función Map Range

Esta función ajusta valores de un rango a otro. Útil para convertir valores de sensores a rangos comprensibles, como mover un servo según un potenciómetro.

Ejemplo:

```python
import board
from ideaboard import IdeaBoard
from analogio import AnalogIn

ib = IdeaBoard()

pot = AnalogIn(board.IO33)
servo = ib.Servo(board.IO4)

while True:
    val = pot.value
    val = ib.map_range(val, 0, 65535, 0, 180)  # Convierte valor del potenciómetro a grados del servo
    servo.angle = val
```

---

## Notas finales

Esta guía está pensada para ayudarte a iniciar con **IdeaBoard** de manera sencilla.
Puedes combinar estas funciones para crear proyectos más complejos como robots, sistemas de luces inteligentes o control de sensores.

---

# Placa Sumobot + IdeaBoard

## Sensores infrarrojos

La placa de Sumobot cuenta con 4 sensores infrarojos en la parte inferior. Este es un código de ejemplo de como se pueden leer los datos de el sensor.  Se asume que los sensores 1 a 4, están conectados a los pines 36,39,34 y 35

```python
import board
from time import sleep
from ideaboard import IdeaBoard

ib = IdeaBoard()

sen1 = ib.AnalogIn(board.IO36)  # SENSOR 1 (adelante izquierdo) pin IO36
sen2 = ib.AnalogIn(board.IO39)  # SENSOR 2 (adelante derecho) pin IO39
sen3 = ib.AnalogIn(board.IO34)  # SENSOR 3 (atrás izquierdo) pin IO34
sen4 = ib.AnalogIn(board.IO35)  # SENSOR 4 (atrá derecho) pin IO35

infrarrojos = [sen1, sen2, sen3, sen4]

while True: 
    for i, sen in enumerate(infrarrojos, start=1):
        print(f"SENSOR {i}: {sen.value}")
    
    print("_________")
    
    sleep(0.5)
```

Los detalles de conexión de la placa, los puede encontrar en [esta guia](https://github.com/Universidad-Cenfotec/Sumobot/blob/main/Guia%20de%20Conexiones%20Sumobot.pdf)

## Acelerómetro y Giroscopio 

La placa del Sumobot, cuenta con un acelerómetro y giroscopio, que se conecta a través de una una conexión Qwiic que requiere un cable especial que se entrega con el Kit de Sumobot. Detalles de las conexiones las puede ver en  [esta guia](https://github.com/Universidad-Cenfotec/Sumobot/blob/main/Guia%20de%20Conexiones%20Sumobot.pdf)

Este código simplificado muestra lo siguiente que:

- Inicializa el acelerómetro y giroscopio LSM6DS3TRC
- Lee datos del acelerómetro y del giroscopio
- Muestra las lecturas en consola
- Explica paso a paso cómo usar cada parte

```python
# Ejemplo básico para leer acelerómetro y giroscopio con el sensor LSM6DS3TRC

import board
import time
import math
from adafruit_lsm6ds import Rate, AccelRange, GyroRange
from adafruit_lsm6ds.lsm6ds3trc import LSM6DS3TRC

# Inicializamos el bus I2C del microcontrolador
i2c = board.I2C()

# Inicializamos el sensor LSM6DS3TRC en la dirección I2C por defecto (0x6B)
sensor = LSM6DS3TRC(i2c, 0x6B)

# Configuramos la sensibilidad del acelerómetro y giroscopio
sensor.accelerometer_range = AccelRange.RANGE_8G  # Hasta ±8G para aceleraciones fuertes
sensor.gyro_range = GyroRange.RANGE_2000_DPS      # Hasta ±2000 grados por segundo para giros rápidos
sensor.accelerometer_data_rate = Rate.RATE_104_HZ # 104 lecturas por segundo
sensor.gyro_data_rate = Rate.RATE_104_HZ          # Igual que acelerómetro para sincronizar

# Función para convertir radianes a grados (opcional, útil para giroscopio)
def radianes_a_grados(radianes):
    return radianes * (180 / math.pi)

print("Iniciando lectura de acelerómetro y giroscopio...")

# Bucle principal
while True:
    # Leer aceleración (X, Y, Z) en metros por segundo cuadrado (m/s²)
    accel_x, accel_y, accel_z = sensor.acceleration
    print(f"Acelerómetro -> X: {accel_x:.2f} m/s², Y: {accel_y:.2f} m/s², Z: {accel_z:.2f} m/s²")
    
    # Leer velocidad angular (X, Y, Z) en radianes por segundo (rad/s)
    gyro_x, gyro_y, gyro_z = sensor.gyro
    print(f"Giroscopio -> X: {radianes_a_grados(gyro_x):.2f} °/s, Y: {radianes_a_grados(gyro_y):.2f} °/s, Z: {radianes_a_grados(gyro_z):.2f} °/s")
    
    print("-----------------------------------------")
    
    # Esperar un poco antes de la siguiente lectura
    time.sleep(0.5)
```

### Explicación del código

**1. Importar librerías**
Se usan `board` para acceder al bus I2C, `time` para esperar entre lecturas y `math` para conversiones. La librería `adafruit_lsm6ds` se usa para controlar el sensor.

**2. Inicializar el sensor**
Se crea una instancia del sensor en la dirección I2C estándar `0x6B`.
Si el sensor está conectado correctamente, comenzará a responder.

**3. Configurar rangos y tasas de datos**
Se ajustan los rangos de acelerómetro y giroscopio para que tengan buena sensibilidad y se evita ruido excesivo.

**4. Leer datos**
En cada ciclo se leen las aceleraciones en X, Y, Z y las velocidades angulares.
Las velocidades angulares se convierten de radianes/segundo a grados/segundo para que sean más fáciles de interpretar.

**5. Mostrar los datos**
Se imprimen en la consola cada medio segundo.

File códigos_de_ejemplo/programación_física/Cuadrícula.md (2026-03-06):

# Cuadrícula de programación (ejemplo)

Para mostrar cómo funciona la programación física del robot se utiliza una **cuadrícula de ejemplo de 4 × 4 casillas**.

Cada casilla contiene un **patrón blanco y negro** que representa un **código binario de 4 bits**.  
Cuando el robot se coloca sobre una casilla, sus **cuatro sensores infrarrojos inferiores** leen el patrón y lo interpretan como una instrucción.

## Características de la cuadrícula

- Tamaño de la cuadrícula: **4 × 4 casillas**
- Tamaño de cada casilla: **6 cm × 6 cm**
- Material utilizado: **cartón con pintura blanca y negra en aceite**

Esta cuadrícula funciona como un **ejemplo visual de cómo programar el robot utilizando patrones físicos**.

Los estudiantes pueden mover el robot de una casilla a otra para generar distintas instrucciones, permitiendo experimentar con la programación sin necesidad de escribir código.

## Ejemplo de lectura de un patrón

Cada sensor detecta si la superficie es blanca o negra:

| Superficie | Bit |
|---|---|
| Blanco | 1 |
| Negro | 0 |

Si el robot detecta el siguiente patrón:

⬜ ⬜ ⬛ ⬛

El código binario generado es:

```
1100
```

Ese código es interpretado por el programa del robot como una **instrucción específica**, por ejemplo avanzar.

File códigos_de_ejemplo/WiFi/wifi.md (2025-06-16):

# Control Remoto SumoBot - IdeaBoard ESP32

Este proyecto básico demuestra cómo utilizar una placa **IdeaBoard con ESP32** y CircuitPython para controlar un robot SumoBot mediante una interfaz web alojada directamente en el dispositivo.

---

## 1. Archivos principales del proyecto

- `wifiApp.py`: Contiene toda la lógica de conexión Wi-Fi, control de motores y servidor web embebido.
- `buscar_ip_sumobot.py`: Utilidad que se ejecuta en tu computadora (por ejemplo, con Visual Studio Code) para encontrar la dirección IP del SumoBot en tu red local.

---

## 2. Instalación de los archivos en la placa IdeaBoard

### Subir el archivo principal

1. Abre Thonny y asegúrate de que tu IdeaBoard esté conectada.
2. Carga el archivo `wifiApp.py` en la raíz del dispositivo.
3. En el archivo `code.py` (también en la raíz de la placa), agrega la siguiente línea para importar el módulo de control:

```python
import wifiApp
```

> Esto hará que se inicie automáticamente el servidor web del SumoBot al encender la placa.

---

## 3. Instalación de la librería necesaria

Este proyecto requiere la librería `adafruit_httpserver`, que no viene incluida por defecto.

### Paso 1: Descargar el paquete de librerías

Descarga el bundle oficial de Adafruit para CircuitPython desde el siguiente enlace:

🔗 [Descargar Adafruit CircuitPython Bundle](https://github.com/adafruit/Adafruit_CircuitPython_Bundle/releases/download/20250614/adafruit-circuitpython-bundle-9.x-mpy-20250614.zip)

### Paso 2: Copiar la librería a la placa

1. Extrae el archivo ZIP descargado.
2. Ubica la carpeta `adafruit_httpserver` dentro del directorio `lib` extraído.
3. En Thonny:
   - Abre el **Explorador de archivos**.
   - En la **parte superior izquierda**, navega en tu PC hasta la carpeta `adafruit_httpserver`.
   - En la **parte inferior izquierda**, entra a la carpeta `/lib` de la IdeaBoard.
   - Haz clic derecho sobre la carpeta `adafruit_httpserver` (en tu PC) y selecciona la opción **Upload to /lib**.

---

## 4. Uso de `buscar_ip_sumobot.py`

Para encontrar rápidamente la URL del panel de control del SumoBot en tu red local:

1. Ejecuta el script `buscar_ip_sumobot.py` desde tu PC.
2. El script escaneará tu red doméstica en busca de dispositivos que estén sirviendo contenido en el puerto **80** (puerto por defecto del servidor web del robot).

### Salida esperada:

```bash
Escaneando red 192.168.1.0/24 buscando dispositivos con puerto 80 abierto...
Dispositivos con puerto abierto encontrados:
http://192.168.1.87:80
```

Haz clic sobre esa URL para abrir directamente el panel de control web del robot.

---

## 5. Variables de entorno para conexión Wi-Fi

El archivo `wifiApp.py` utiliza dos variables críticas para conectarse a la red Wi-Fi:

```python
ssid = os.getenv("CIRCUITPY_WIFI_SSID")
password = os.getenv("CIRCUITPY_WIFI_PASSWORD")
```

### ¿Qué hacen?

- `CIRCUITPY_WIFI_SSID`: Define el nombre de tu red Wi-Fi.
- `CIRCUITPY_WIFI_PASSWORD`: Define la contraseña de tu red.

### ¿Dónde se configuran?

En el archivo `settings.toml`, ubicado en la raíz del dispositivo:

```toml
CIRCUITPY_WIFI_SSID = "NombreDeTuRedWiFi"
CIRCUITPY_WIFI_PASSWORD = "TuContraseñaWiFi"
```

⚠️ **Nota**: Este archivo debe crearse con cuidado y no debe compartirse públicamente.

---

## 6. ¿Qué demuestra este proyecto?

Este es un ejercicio introductorio para mostrar las capacidades de la placa **IdeaBoard con ESP32**:

- Conexión automática a redes Wi-Fi.
- Servidor web embebido con controles de movimiento del robot.
- Interfaz futurista y responsiva desde cualquier navegador.
- Posibilidad de expandirse para consumir **APIs externas** (por ejemplo, clima, sensores remotos, dashboards) y mostrar datos en tiempo real.

¡Una poderosa demostración de cómo tu IdeaBoard puede interactuar con el mundo a través de la red local! 🌐🤖

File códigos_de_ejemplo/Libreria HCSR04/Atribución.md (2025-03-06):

The MIT License (MIT)

Copyright (c) 2017 Mike Mabey

Permission is hereby granted, free of charge, to any person obtaining a copy of this software and associated documentation files (the "Software"), to deal in the Software without restriction, including without limitation the rights to use, copy, modify, merge, publish, distribute, sublicense, and/or sell copies of the Software, and to permit persons to whom the Software is furnished to do so, subject to the following conditions:

The above copyright notice and this permission notice shall be included in all copies or substantial portions of the Software.

THE SOFTWARE IS PROVIDED "AS IS", WITHOUT WARRANTY OF ANY KIND, EXPRESS OR IMPLIED, INCLUDING BUT NOT LIMITED TO THE WARRANTIES OF MERCHANTABILITY, FITNESS FOR A PARTICULAR PURPOSE AND NONINFRINGEMENT. IN NO EVENT SHALL THE AUTHORS OR COPYRIGHT HOLDERS BE LIABLE FOR ANY CLAIM, DAMAGES OR OTHER LIABILITY, WHETHER IN AN ACTION OF CONTRACT, TORT OR OTHERWISE, ARISING FROM, OUT OF OR IN CONNECTION WITH THE SOFTWARE OR THE USE OR OTHER DEALINGS IN THE SOFTWARE.

El código para la libreria para el sensor HCSR-04 fue creada por Mike Mabey y otros contribuyentes del repositorio [CircuitPython_HCSR04](https://github.com/mmabey/CircuitPython_HCSR04) en GitHub

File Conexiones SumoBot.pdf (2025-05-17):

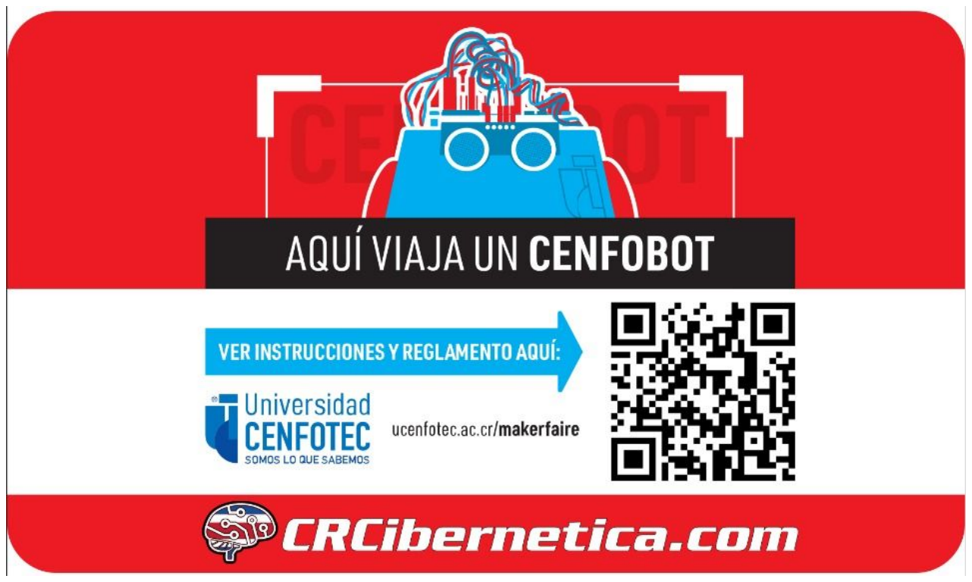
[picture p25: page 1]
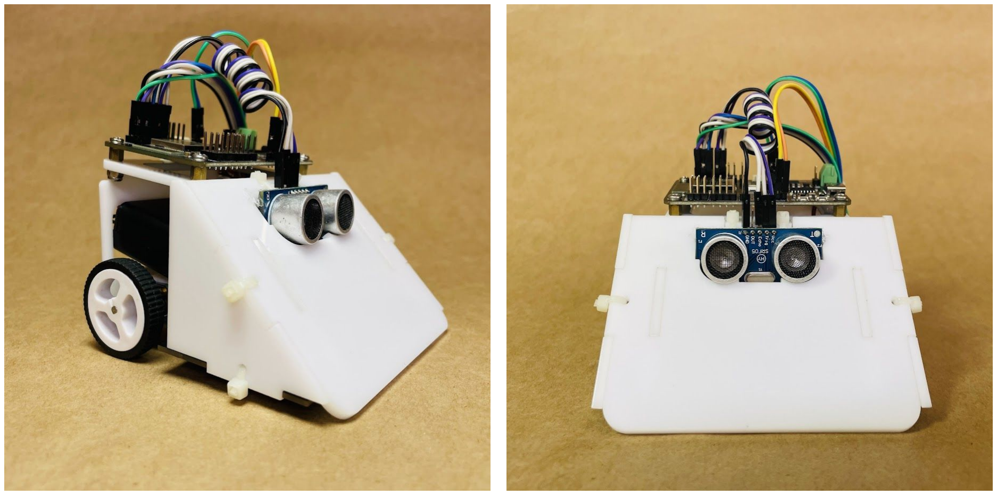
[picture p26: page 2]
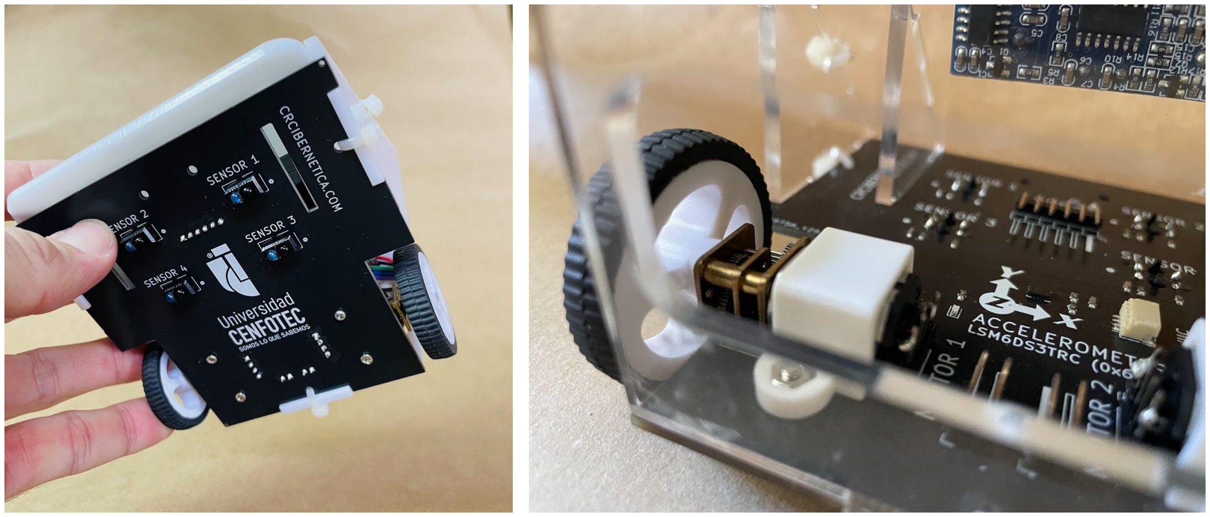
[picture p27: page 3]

## Placa Sumobot


## IdeaBoard


Energía para el IdeaBoard

+

+

Conectar para dar energía a Motores y Ultrasónico
On | Off

ESP32

## Conexiones Sensores Infrarrojos


Sensores infrarrojos

Cables “Jumper”


1 GND 2

1

2 3.3V

Energía para los sensores infrarrojos


Sensores infrarrojos

1

2

3

4

sen1 = ib.AnalogIn(board.IO36) sen2 = ib.AnalogIn(board.IO39) sen3 = ib.AnalogIn(board.IO34) sen4 = ib.AnalogIn(board.IO35)

1

2

3

4

## Conexión Ultrasónico

TRIG pin IO25 ECHO pin IO26

Sensor Ultrasónico HC-SR04

## Conexión Acelerómetro-Giroscopio


Cable Qwiic

Acelerómetro y Giroscopio (Conexíon QWIIC)


1 Qwiic

Acelerómetro y Giroscopio (Conexíon QWIIC)

1

Qwiic

Qwiic

## Conexión Motores


Motores

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

https://github.com/Universidad-Cenfotec/Sumobot/

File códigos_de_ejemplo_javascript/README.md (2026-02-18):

# ☕ Espruino 🟡
Logotipo del Proyecto Espruino

Espruino es un **intérprete de JavaScript para microcontroladores**. Permite programar placas como ESP32 usando **JavaScript directamente**, sin necesidad de compilar código en C/C++ como en Arduino.

La idea principal de Espruino es hacer el desarrollo **rápido, interactivo y educativo**, muy similar a trabajar con Python en MicroPython o CircuitPython, pero usando JavaScript.

Estos ejemplos usan **Espruino** como entorno principal para controlar el **SumoBot de la Universidad CENFOTEC con** la **IdeaBoard de CRCibernética**.

---

## ¿Por qué usar Espruino?

* ✅ JavaScript real (no es un lenguaje nuevo)
* ✅ REPL interactivo (ejecutar código en vivo)
* ✅ Ideal para educación y prototipado rápido
* ✅ Compatible con ESP32, ESP8266, STM32, entre otros
* ✅ Soporta módulos reutilizables

Si ya sabes JavaScript para web, **la curva de aprendizaje es muy baja**.

---

## Instalación del firmware de Espruino

Antes de usar Espruino, la placa debe tener el **firmware de Espruino** instalado.

Para el *ESP32* esto es bastante directo, se puede usar el flasher en linea que que provee [Espruino](https://www.espruino.com/Espressif+Flash)

---

## Editores disponibles

Espruino puede usarse de varias formas, dependiendo de tu estilo de trabajo.

---

### 🌐 Editor Web de Espruino

Disponible en:

[https://www.espruino.com/ide/](https://www.espruino.com/ide/)

Características:

* Editor en el navegador
* Consola REPL integrada
* Envío de código en tiempo real
* Soporte automático para módulos

Ideal para:

* Pruebas rápidas
* Clases
* Primeros pasos

---

### 🖥️ IDE de Escritorio (Espruino IDE)

Aplicación de escritorio (Windows, Linux, macOS).

Ventajas:

* Mejor manejo de archivos
* Soporte para proyectos grandes
* Carga de módulos locales
* Consola estable

Recomendado cuando el proyecto empieza a crecer.

---

## Módulos en Espruino

Espruino soporta el uso de módulos mediante `require()`, similar a Node.js.

```js
const ib = require("ideaboard").connect();
```

Existen **tres formas principales** de usar módulos.

---

### 1️⃣ Módulos desde Internet (Repositorio oficial)

Espruino tiene un **repositorio oficial de módulos**.

Cuando haces:

```js
require("HC-SR04")
```

El IDE:

* Descarga el módulo automáticamente
* Lo guarda en la placa
* Lo ejecuta en memoria

✔ Fácil
✔ Rápido
✔ Ideal para aprendizaje

⚠️ Requiere conexión a internet

---

### 2️⃣ Módulos locales (IDE de Escritorio exclusivamente)

Puedes descargar un módulo manualmente y usarlo desde tu computadora.
Para esto debes seguir los paso en esta parte de la [documentación](https://www.espruino.com/Modules#from-a-local-folder), aunque se avisa que esté se encuentra en inglés y contiene lenguaje técnico.

Ejemplo:

```js
require("./ideaboard.js")
```

Ventajas:

* Funciona sin internet
* Control total del código
* Ideal para desarrollo y depuración

---

### 3️⃣ Módulos subidos al almacenamiento de la placa

También puedes **subir archivos `.js` directamente a la memoria interna** de la placa.

Ejemplo:

```js
require("ideaboard")
```

⚠️ Importante:

* El **editor puede marcar errores** (archivo no encontrado)
* El **código SÍ funcionará correctamente en la placa**
* Es una limitación del análisis estático del editor
* Para usarlo como otro modulo, deben ser guardados sin la extensión **.js**

Este método es común en proyectos finales o distribuidos.

---

## Diferencias clave con Arduino

| Arduino | Espruino |
| --- | --- |
| Compilación | Interpretado |
| C / C++ | JavaScript |
| Carga lenta | Ejecución inmediata |

En Espruino, un loop típico se ve así:

```js
setInterval(function () {
  // código repetitivo
}, 50);
```

Esto es equivalente a:

```python
while True:
    pass
```

---

## Recursos útiles

* Documentación oficial: [https://www.espruino.com/Reference](https://www.espruino.com/Reference)
* IDE Web: [https://www.espruino.com/ide/](https://www.espruino.com/ide/)
* Repositorio de módulos: [https://www.espruino.com/Modules](https://www.espruino.com/Modules)

---

✨ Si vienes de Arduino, MicroPython o CircuitPython, Espruino es una forma excelente de **pensar diferente**, sin dejar de aprender electrónica y robótica.

<pre>
 _____                 _
|   __|___ ___ ___ _ _|_|___ ___
|   __|_ -| . |  _| | | |   | . |
|_____|___|  _|_| |___|_|_|_|___|
          |_|
</pre>

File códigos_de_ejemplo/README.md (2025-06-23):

# Contenidos de este directorio

| Archivo | Descripción |
|---|---|
| [`Libreria HCSR04`](https://github.com/Universidad-Cenfotec/Sumobot/blob/main/c%C3%B3digos_de_ejemplo/Libreria%20HCSR04) | Librería para el sensor ultrasónico HCSR04. |
| [`Control_Movimientos.md`](https://github.com/Universidad-Cenfotec/Sumobot/blob/main/c%C3%B3digos_de_ejemplo/Control_Movimientos.md) | Documento con instrucciones o ejemplos sobre control de motores con giroscópio. |
| [`SumoBot_Device_Files.zip`](https://github.com/Universidad-Cenfotec/Sumobot/blob/main/c%C3%B3digos_de_ejemplo/SumoBot_Device_Files.zip) | Archivos relacionados al dispositivo Sumobot (versión antigua). |
| [`almacenando_datos.md`](https://github.com/Universidad-Cenfotec/Sumobot/blob/main/c%C3%B3digos_de_ejemplo/almacenando_datos.md) | Explicación sobre cómo almacenar datos en un archivo dentro del Sumobot. |
| [`code.py`](https://github.com/Universidad-Cenfotec/Sumobot/blob/main/c%C3%B3digos_de_ejemplo/code.py) | Código principal de ejemplo para el Sumobot. |
| [`code_4IR.py`](https://github.com/Universidad-Cenfotec/Sumobot/blob/main/c%C3%B3digos_de_ejemplo/code_4IR.py) | Lectura de 4 sensores infrarrojos. |
| [`code_PDI.py`](https://github.com/Universidad-Cenfotec/Sumobot/blob/main/c%C3%B3digos_de_ejemplo/code_PDI.py) | Código pra contro con PDI de movimientos directos y giros. |
| [`code_acc.py`](https://github.com/Universidad-Cenfotec/Sumobot/blob/main/c%C3%B3digos_de_ejemplo/code_acc.py) | Lectura de datos del acelerómetro. |
| [`code_acc_motor_move.py`](https://github.com/Universidad-Cenfotec/Sumobot/blob/main/c%C3%B3digos_de_ejemplo/code_acc_motor_move.py) | Movimiento del motor basado en lectura del acelerómetro. |
| [`code_boton0.py`](https://github.com/Universidad-Cenfotec/Sumobot/blob/main/c%C3%B3digos_de_ejemplo/code_boton0.py) | Lectura de botón físico "BOOT" conectado al IdeaBoard. |
| [`code_diagnostic.py`](https://github.com/Universidad-Cenfotec/Sumobot/blob/main/c%C3%B3digos_de_ejemplo/code_diagnostic.py) | Diagnóstico general del sistema, sin necesidad de acelerómetro. |
| [`code_lecturaIR_4Bit.py`](https://github.com/Universidad-Cenfotec/Sumobot/blob/main/c%C3%B3digos_de_ejemplo/code_lecturaIR_4Bit.py) | Lectura digital de sensores IR y conversión a valor binario de 4 bits. |
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

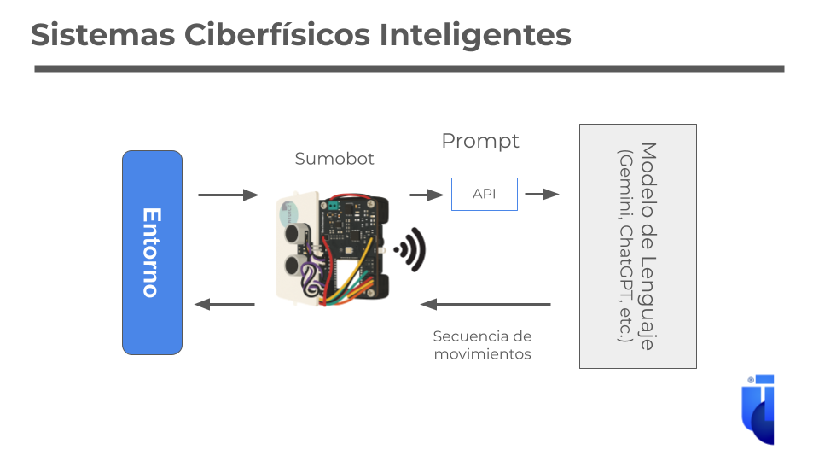
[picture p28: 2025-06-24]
códigos_de_ejemplo/LLM_in_the_Loop_Robotics/ArqSumobotGemini.png

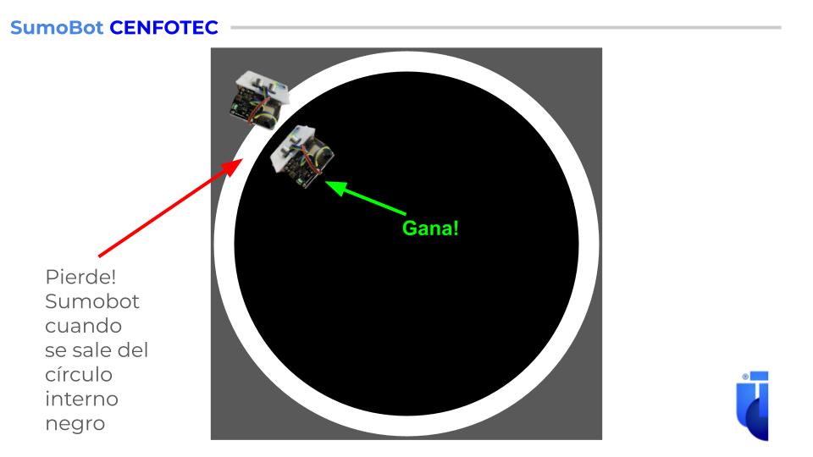
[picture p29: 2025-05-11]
imagenes/gana_pierde.jpg

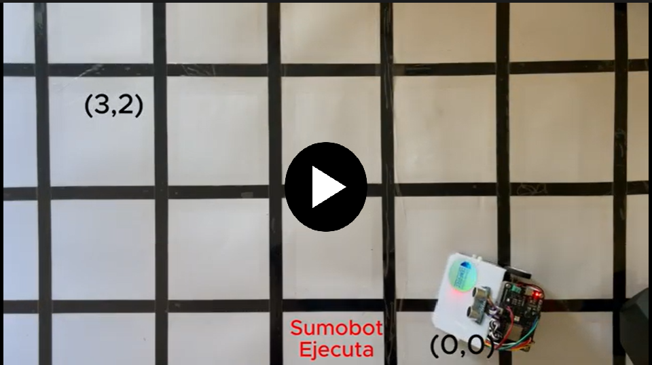
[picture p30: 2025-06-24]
códigos_de_ejemplo/LLM_in_the_Loop_Robotics/SumoBotGemini2.png

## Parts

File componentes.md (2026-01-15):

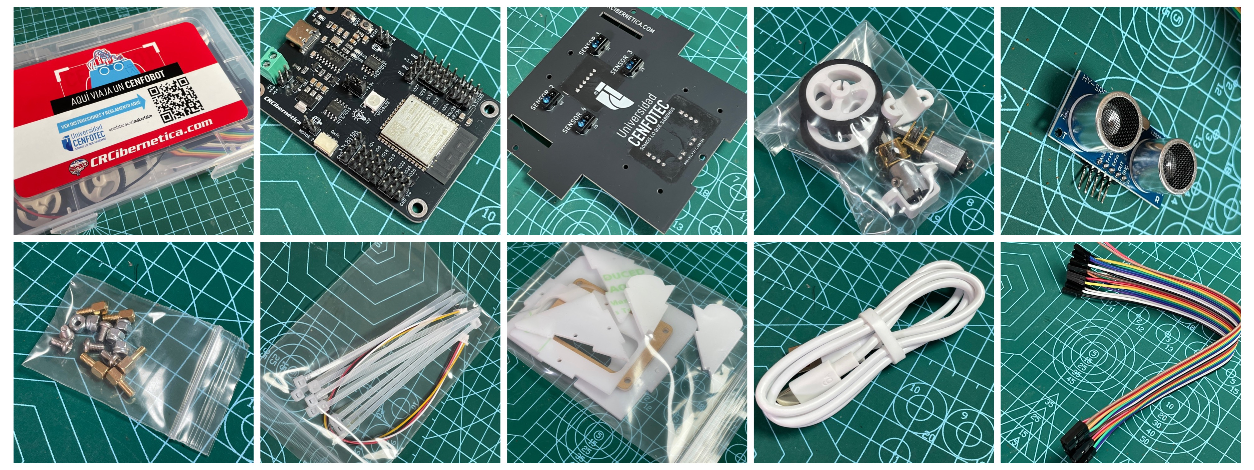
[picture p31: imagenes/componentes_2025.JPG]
componentes


# Componentes del Sumobot 

¡Descubrí el nuevo SumoBot !

El SumoBot de 2025 trae muchas mejoras respecto al modelo del 2024. Ahora tiene una nueva placa base especialmente diseñada para su chasis, lo que le da más fuerza y estabilidad. Además, el robot cuenta con cuatro sensores infrarrojos que le permiten detectar la línea blanca del dojo en diferentes posiciones, un acelerómetro y un giroscopio que mejoran su navegación y precisión.

También se mejoró la forma en que los motores se conectan al chasis, haciendo que el robot sea más confiable en las competencias y evitando los problemas de conexión que se dieron en el pasado.

¡Prepárate para construir, programar y competir con la nueva generación de SumoBots en el torneo 2025!

Todos los componentes se pueden encontrar en Costa Rica en [CrCibernética](https://www.crcibernetica.com/sumobot-universidad-cenfotec/).

## Kit Sumobot 2025

El kit incluye:

1. Placa o Shield PCB que sirve como base del chasis ([Hecho en COsta Rica por CrCibernética](https://www.crcibernetica.com/sumobot-shield/)).
2. Placa IdeaBoard con microcontrolador ESP32 ([Hecho en Costa Rica por CrCibernetica](https://www.crcibernetica.com/crcibernetica-ideaboard/?searchid=2395932&search_query=ideaboard))
3. Piezas del cuerpo del robot hechas en acrílico blanco.  
4. Tiras de plástico para el ensamblaje.  
5. Cables ["jumper"](https://www.crcibernetica.com/female-to-female-jumper-wire-40-pcs-in-one-bunch/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) para conexiones eléctricas.  
6. Cable [Qwiic](https://www.crcibernetica.com/stemma-qt-qwiic-jst-sh-4-pin-cable-20cm/?searchid=2395934&search_query=Qwiic) para conexión rápida de sensores.  
7. Sensor [ultrasónico](https://www.crcibernetica.com/hc-sr05-ultrasonic-distance-sensor/?searchid=2395935&search_query=ultrasonic) para detección de objetos.  
8. Caja para baterías AA.  
9. Motores [Microgear](https://www.crcibernetica.com/micro-gearmotor/?searchid=0&search_query=motor) de 200 RPM y asas de plástico.

---
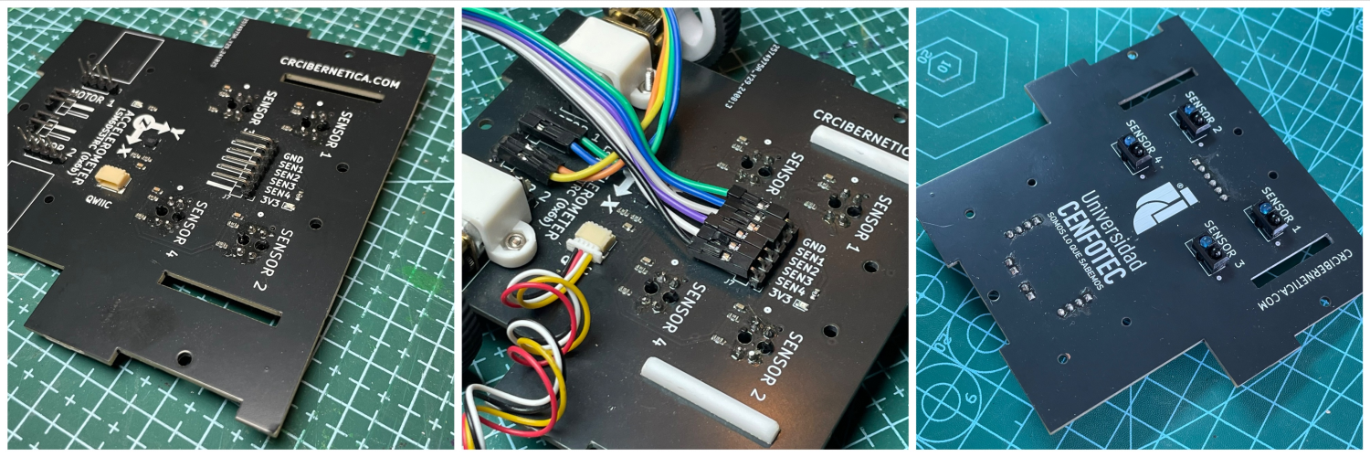
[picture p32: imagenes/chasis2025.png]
Chasis


## Chasis del Sumobot 

¿Cómo es el chasis del SumoBot?

El chasis del SumoBot es una placa PCB especial que ya incluye los sensores infrarrojos, el acelerómetro y el giroscopio. Todo está integrado para que sea mucho más fácil conectar los sensores directamente al microcontrolador y trabajar en tu robot sin complicaciones.

---

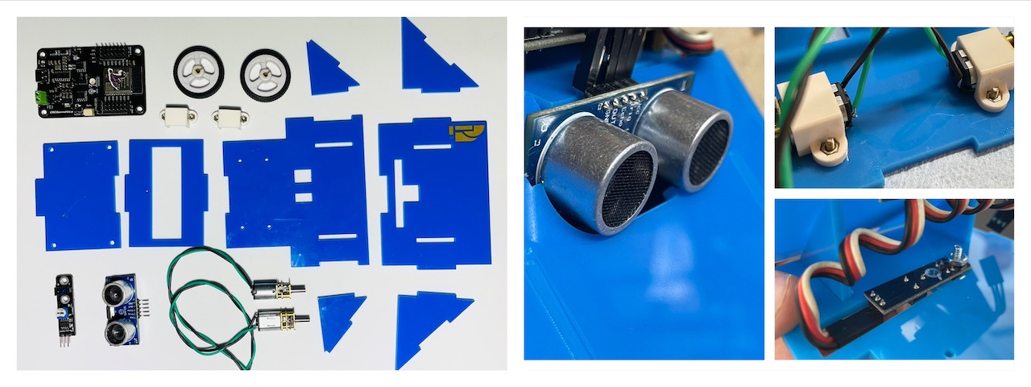
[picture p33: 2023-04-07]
imagenes/SumoBot_Parts.JPG

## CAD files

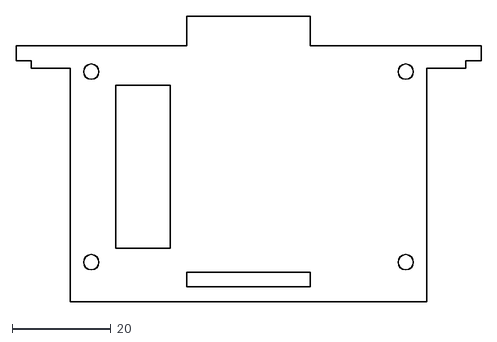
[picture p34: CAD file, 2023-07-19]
archivos_de_fabricacion/FeeCAD_model/DXF/techo.dxf
94.2 x 57.8

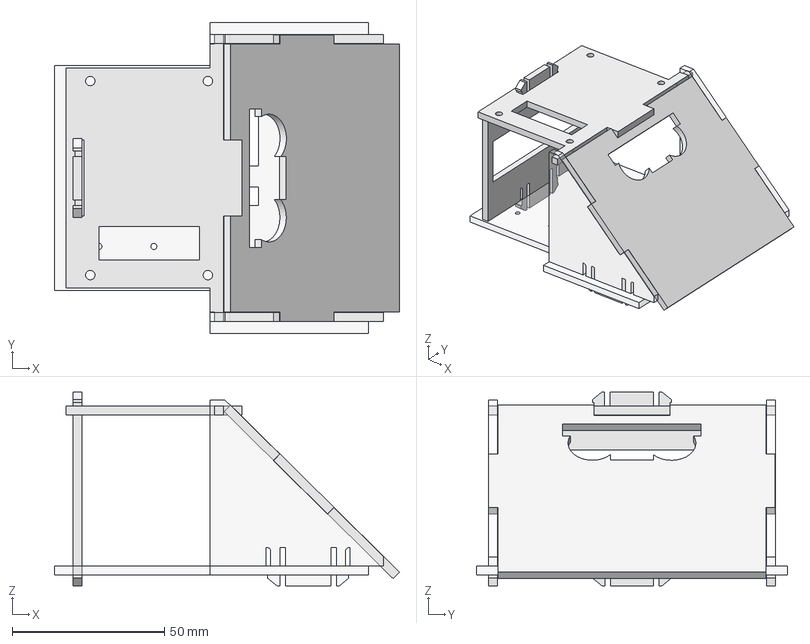
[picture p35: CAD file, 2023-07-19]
archivos_de_fabricacion/FeeCAD_model/Sumobot_acrilic_3mm.FCStd
113.2 x 102.0 x 63.5 mm
Lateral001

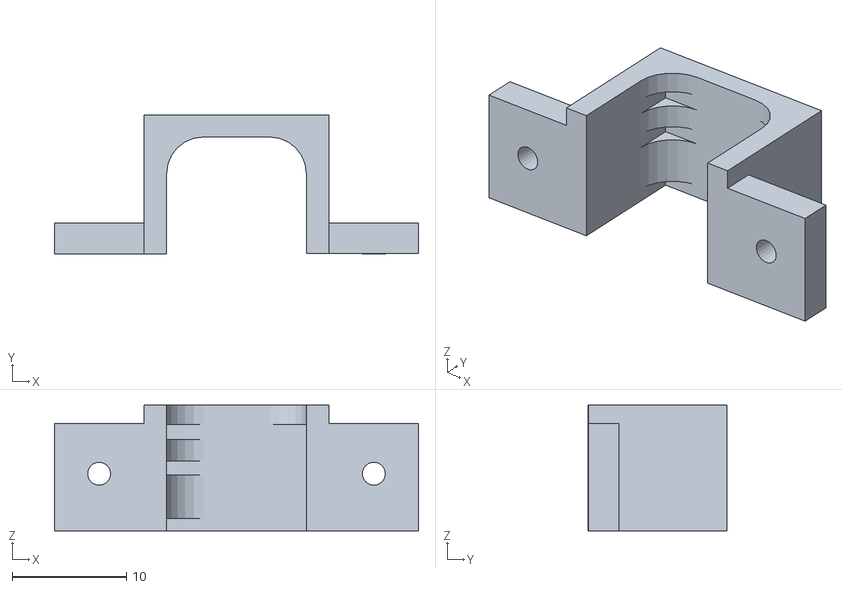
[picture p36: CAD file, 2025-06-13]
archivos_de_fabricacion/soporte_motores.stl
31.8 x 12.1 x 11.0

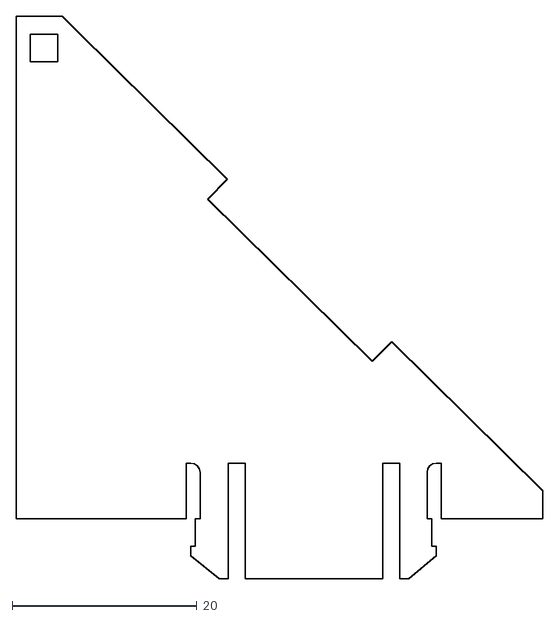
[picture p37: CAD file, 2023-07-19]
archivos_de_fabricacion/FeeCAD_model/DXF/laterales.dxf
57.0 x 60.9

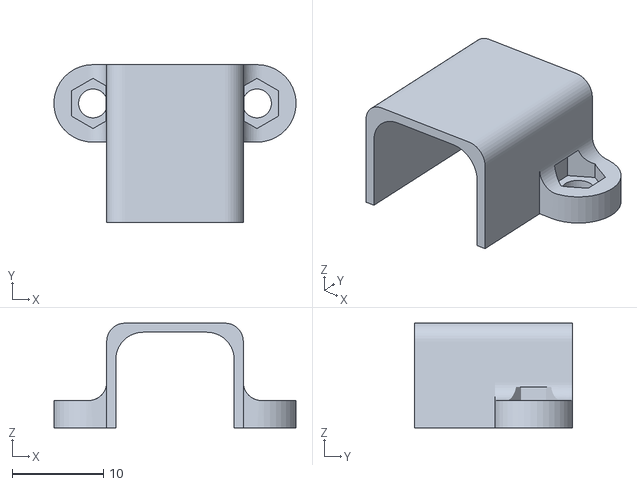
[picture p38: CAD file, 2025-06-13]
archivos_de_fabricacion/MOTOR_BRACKET.stl
26.6 x 17.3 x 11.5

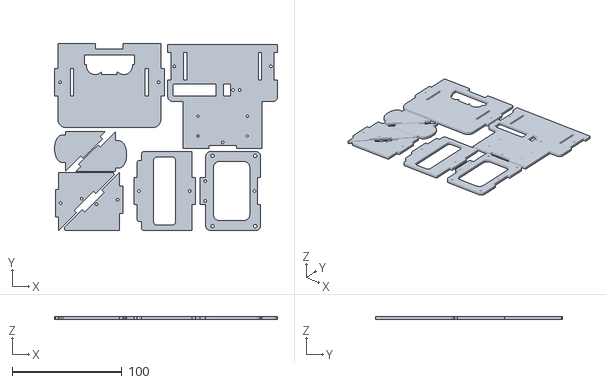
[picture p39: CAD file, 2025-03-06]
archivos_de_fabricacion/Chasis_Sumobot_3D_2025.stl
203.1 x 170.4 x 3.00

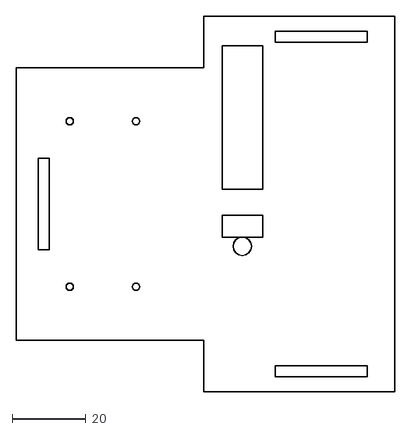
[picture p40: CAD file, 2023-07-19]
archivos_de_fabricacion/FeeCAD_model/DXF/base.dxf
103.0 x 102.0

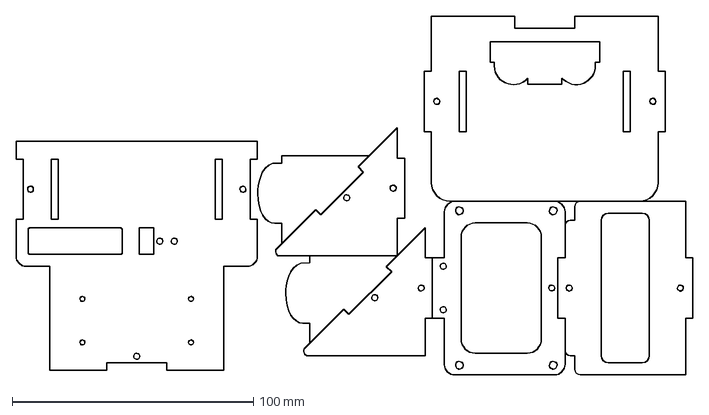
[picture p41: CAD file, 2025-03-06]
archivos_de_fabricacion/chasis_sumobot.dxf
280.5 x 148.7 mm

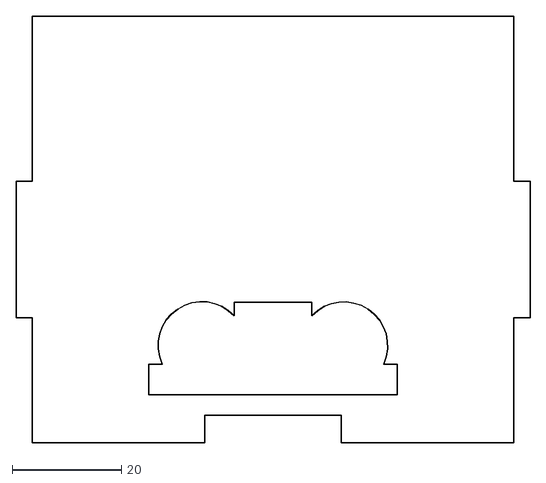
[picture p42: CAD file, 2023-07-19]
archivos_de_fabricacion/FeeCAD_model/DXF/pala.dxf
94.0 x 78.0

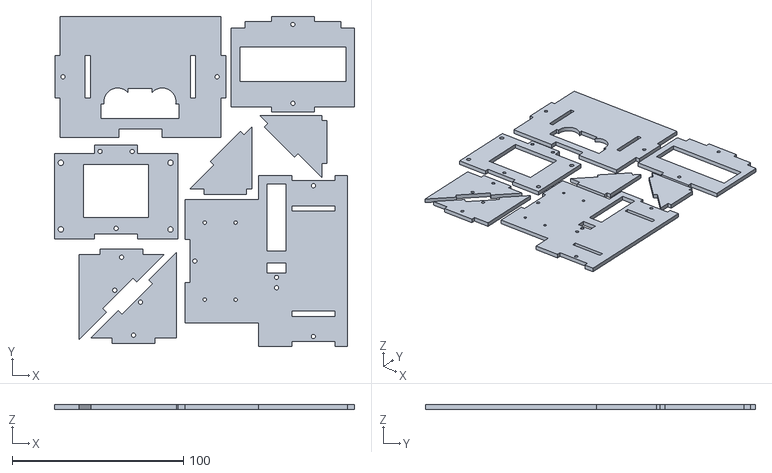
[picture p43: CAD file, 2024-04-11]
archivos_de_fabricacion/chasis_sumobot2024_3D.stl
175.2 x 193.0 x 3.00

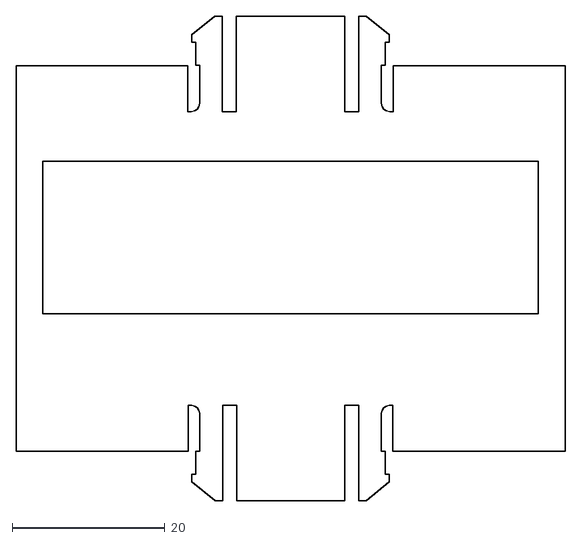
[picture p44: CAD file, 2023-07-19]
archivos_de_fabricacion/FeeCAD_model/DXF/pared_trasera.dxf
72.0 x 63.5

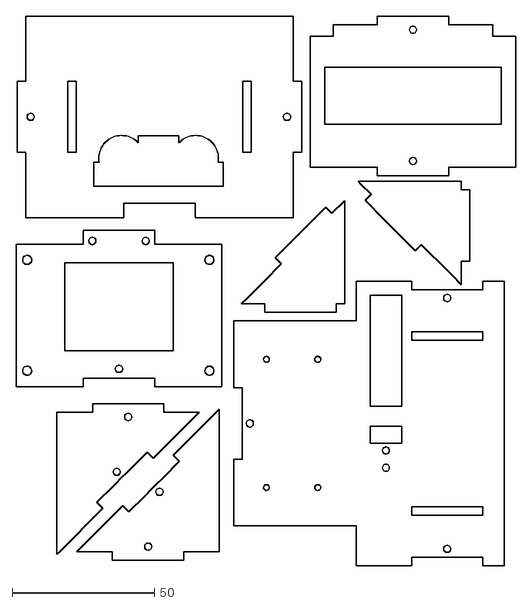
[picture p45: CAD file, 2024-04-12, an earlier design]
archivos_de_fabricacion/Old/chasis_sumobot.dxf
175.2 x 193.0

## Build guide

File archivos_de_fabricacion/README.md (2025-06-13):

# Archivos de fabricación del Chasis del SumoBot – Universidad CENFOTEC

## 📁 Archivos de fabricación del Chasis

### 🔹 1. **chasis_sumobot_2025.svg**
- **Formato:** SVG (Scalable Vector Graphics)
- Diseño vectorizado del SumoBot. Puede ser exportado a otros formatos mediante software de diseño como [Inkscape](https://inkscape.org/es/) o Adobe Illustrator.

### 🔹 2. **chasis_sumobot_2025_LaserCutOptimized.svg**
- **Formato:** SVG (Scalable Vector Graphics)
- Diseño optimizado para corte en máquina láser, maximizando el uso del material.

### 🔹 3. **chasis_sumobot.dxf**
- **Formato:** DXF (Drawing Exchange Format)
- Archivo CAD que define dimensiones, cortes y perforaciones. Es compatible con la mayoría de los programas de corte láser. Basado en **chasis_sumobot_2025_LaserCutOptimized.svg**.
**chasis_sumobot.dxf**
### 🔹 4. **Sumobot_LaserCut.rld**
- **Formato:** RLD
- Archivo nativo de corte láser, desarrollado para RDWorks. Puede ser usado directamente en muchas máquinas de corte láser sin necesidad de conversión. Basado en **chasis_sumobot.dxf**.

### 🔹 5. **chasis_sumobot2025_3D.stl**
- **Formato:** STL (STereoLithography)
- Modelo 3D del chasis para impresión 3D.

### 🔹 6. **MOTOR_BRACKET.stl**
- **Formato:** STL (STereoLithography)
- Modelo 3D de los soportes para los micro motores para impresión 3D. utilizan tornillos estandar #2 para fijación, también puede conseguir los soportes y tornillos en [CRCibernética.](https://www.crcibernetica.com/micro-gearmotor-support-bracket/?searchid=2426159&search_query=bracket)
- **Atribución:** Este modelo 3D fue creado por Bruce Bell y publicado en [Thingiverse.](https://www.thingiverse.com/thing:252470)

---

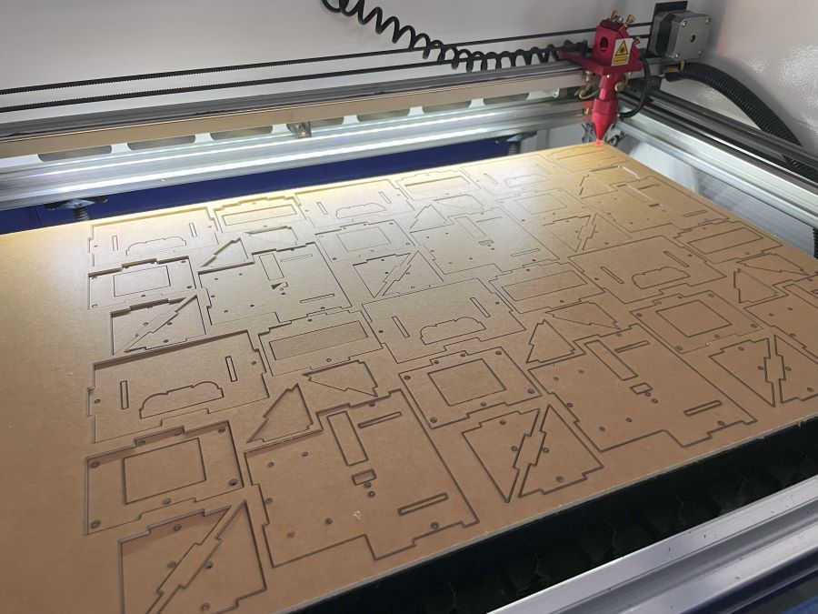
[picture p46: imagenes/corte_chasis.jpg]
Imagen Corte


---

## 🛠️ Modificación del Chasis 🤖
Si deseas modificar el diseño o separar partes, puedes usar el siguiente enlace a Tinkercad:

🔗 [Abrir en Tinkercad](https://www.tinkercad.com/things/2SyTLlaZ3rV-sumobot6?sharecode=ivtFQecJ67wsbuyDAFKAAIibqH1ZuByYk1oDVZOuIXM)

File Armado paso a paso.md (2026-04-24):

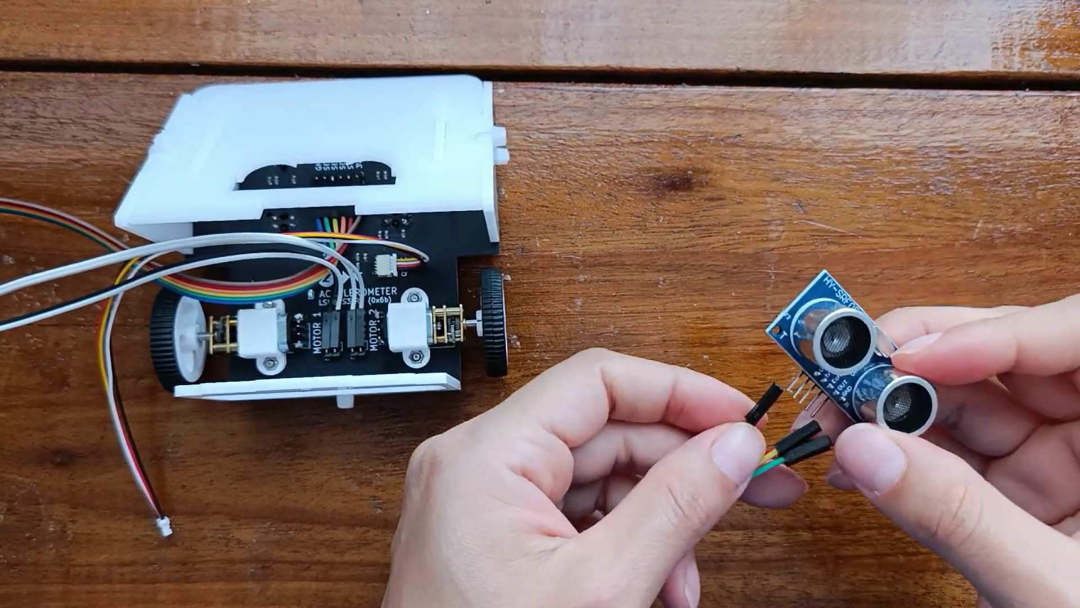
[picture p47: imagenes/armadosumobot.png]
armado

# Armando el Sumobot

¿Qué tan fácil es armar el SumoBot? ¡Muy fácil! No necesitás pegamento ni materiales especiales: todo lo que ocupás viene incluido en el kit.
La única herramienta que vas a necesitar es un desatornillador Phillips para colocar la IdeaBoard en el robot, y un cautín para soldar los motores.
Todo lo demás se ensambla usando las tiras de plástico que ya vienen en el paquete.

¡Así que podés concentrarte en construir, programar y competir!

## Armando el Sumobot

- Para armar el sumobot pueden seguir las [instrucciones en este video](https://youtu.be/Cxlyzh-E9kE?si=Whpzej_X_6gWu1zQ)
- En la siguientes secciones se detallan algunos de los pasos de soldado de motores y esquema de conexiones

Claro, aquí tienes una **versión ordenada y clara, paso a paso**, del **ensamblaje del Sumobot CENFOTEC**, sin necesidad de imágenes:

---

### **Materiales necesarios antes de comenzar**

* Desatornillador pequeño
* Soldador y estaño (ver video anterior para instrucciones)
* Pinzas o tijera
* Componentes del kit (motores, llantas, placa inferior y superior, sensores, caja de baterías, tornillos, tuercas, soportes, IdeaBoard)

---

### **1. Armado de la parte inferior (placa sumobot)**

1. Saca todas las piezas pequeñas del empaque con cuidado (tornillos, tuercas, motores, llantas, etc.).
2. Coloca los **motores** sobre la **placa inferior** en la posición adecuada.
3. Utiliza los **soportes plásticos** para sujetar los motores a la placa.
4. Inserta los tornillos y tuercas, ajustando lo suficiente para que quede firme pero no demasiado apretado.
5. Repite el proceso con el segundo motor.
6. **Solda los cables** a los motores ([ver video de don Tomás si no sabes cómo hacerlo](https://youtu.be/R4Um8DInFHk?si=ON4kUQGllQKRUqAh)).

---

### **2. Conexión de los sensores y cables**

qwiic

7. Usa el cable Qwiic para conectar el **acelerómetro** a la placa IdeaBoard.
8. Inserta los cables (conectores Dupont) del **sensor de infrarrojo** (cuatro sensores + GND + VCC) con mucho cuidado.
9. Usa **seis cables jumper (Dupont)** en total para conectar sensores y acelerómetro.
10. Conecta los motores a la placa usando **dos cables jumper** para cada motor (Motor 1 y Motor 2).

IR

---

### **3. Colocación de las llantas**

11. Busca la parte plana del eje del motor.
12. Alinea esa parte con el orificio de la llanta y empuja con firmeza hasta que encaje.
13. Repite con la segunda llanta.

---

### **Armado de la estrutura del Sumobot**

14. Retira el plástico protector de las piezas acrílicas.
15. Atornilla los **soportes** (espaciadores) a los cuatro extremos de la placa inferior.
16. Coloca la **IdeaBoard** sobre los espaciadores y atorníllala con tornillos pequeños.
17. Si deseas, puedes **pintar o decorar** el chasis antes o después de ensamblarlo.

---

### 5. Montaje del chasis lateral y frontal**

18. Toma las piezas laterales del chasis y únelas usando **gasillas**, ajustándolas bien.
19. Repite el proceso para el lado contrario.
20. Coloca la **pieza frontal**, asegurándola también con gasillas.
21. Recorta los sobrantes de gasilla con tijera o pinzas.

---

### **6. Ensamblaje final del cuerpo**

22. Coloca las **dos piezas verticales de soporte** en la placa inferior (las que sostendrán la tapa superior).
23. Sobre estas piezas, coloca la **placa superior**, asegurándola cuidadosamente.
24. Usa gasillas para sujetar firmemente la tapa superior.
25. Asegura la **pieza trasera** con gasilla.

---

### **7. Conexión del sensor ultrasónico**

26. Toma **cuatro cables jumper** y conéctalos al sensor ultrasónico.
27. Conecta los cables a la **placa IdeaBoard**, siguiendo la guía del GitHub o el archivo “Guía de Conexiones” ([puedes ponerle pausa al video o descargar el PDF](https://github.com/Universidad-Cenfotec/Sumobot/blob/main/Conexiones%20SumoBot.pdf)).
28. Asegúrate de no forzar los pines al insertar.

ultra

---

### **8. Conexión de la caja de baterías**

29. Afloja los tornillos de la entrada de energía en la placa.
30. Conecta el **cable negro (negativo)** y el **rojo (positivo)** con ayuda del desatornillador.
31. Ajusta para que queden bien prensados.
32. Inserta la **caja de baterías** dentro del chasis, organizando bien los cables para que no estorben.
33. Verifica que el **interruptor de encendido** esté accesible.


---
### **9. Acomodando Baterías**

<p align="center">
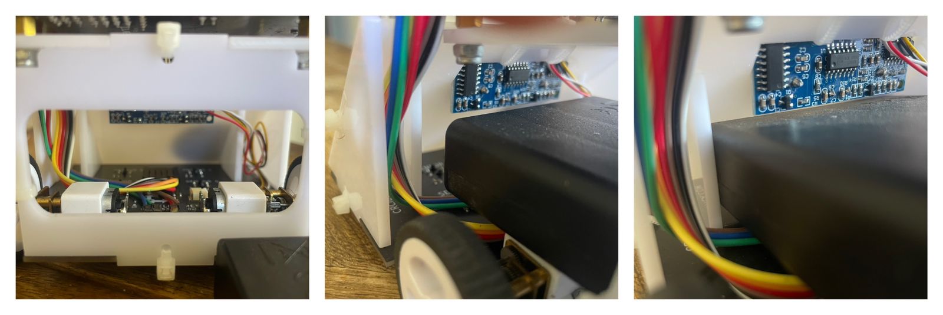
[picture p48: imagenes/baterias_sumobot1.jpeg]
  
</p>

Las baterías se colocan dentro del Sumobot. Asegúrese de que los cables queden pegados a la placa, de modo que permitan el paso adecuado de las baterías, tal como se observa en la imagen.

<p align="center">
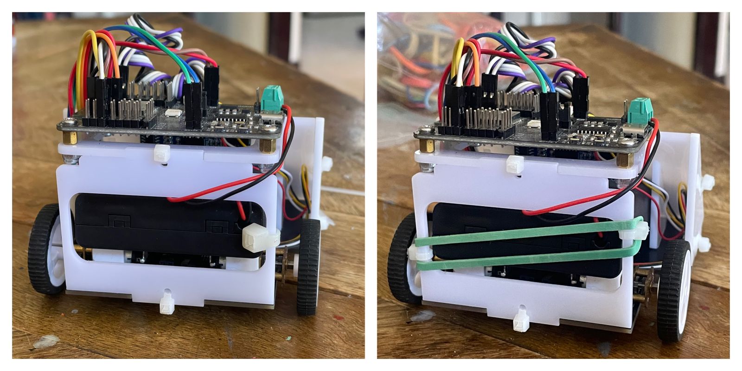
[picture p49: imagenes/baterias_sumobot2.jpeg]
  
</p>

Para fijar las baterías, puede utilizar una tira de plástico que las presione lateralmente, o bien sujetarlas con un elástico, como se muestra en la fotografía.

---
### **10. Revisión final**

34. Conecta el cable USB-C a la placa IdeaBoard para verificar que la luz de encendido funcione.
35. Asegúrate de que todas las conexiones estén firmes y bien organizadas.

---

### ¡Listo!

Has terminado de armar el **Sumobot CENFOTEC**. Ahora puedes continuar con la programación y pruebas de movimiento.

## Esquema de conexiones 2025

Una guia completa de las conexiones del SumoBot ls pueden encontrar en [este documento](https://github.com/Universidad-Cenfotec/Sumobot/blob/main/Conexiones%20SumoBot.pdf)

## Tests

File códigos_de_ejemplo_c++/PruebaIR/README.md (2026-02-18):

# 👀 PruebaIR (ESP32) — Lectura de sensores infrarrojos con indicador NeoPixel

**Universidad CENFOTEC**  

Este programa sirve para **probar y entender sensores infrarrojos (IR)** conectados al ESP32.  
Lee **4 sensores analógicos**, muestra sus valores en el **Monitor Serial** y utiliza un **LED NeoPixel** como indicador visual:

- 🔴 **Rojo** → el sensor detecta **NEGRO**
- 🔵 **Azul claro** → el sensor detecta **BLANCO**

Además, el programa puede **detenerse escribiendo `STOP`** desde el Monitor Serial.

Es ideal como práctica previa para robots **seguidor de línea** o **sumo**.

---

## 🧠 ¿Qué hace este código?

El programa realiza un ciclo continuo donde:

1. Lee los 4 sensores IR uno por uno
2. Imprime el valor de cada sensor en el Monitor Serial
3. Decide si el sensor ve **blanco o negro** usando un valor umbral
4. Cambia el color del LED NeoPixel según el resultado
5. Permite detener todo el programa con el comando `STOP`

---

## 📚 Librerías utilizadas

Este proyecto usa una librería externa:

### Adafruit NeoPixel
```cpp
#include <Adafruit_NeoPixel.h>
```

📦 Para instalarla:
1. Abre **Arduino IDE**
2. Ve a **Sketch → Include Library → Manage Libraries**
3. Busca **Adafruit NeoPixel**
4. Instálala

---

## 🎯 Concepto clave: blanco vs negro

El programa usa un **valor crítico**:

```cpp
const int valor_critico = 1000;
```

- Si la lectura es **mayor** → NEGRO
- Si la lectura es **menor** → BLANCO

💡 Este valor **depende mucho** del:
- Tipo de sensor
- Altura del sensor sobre el suelo
- Iluminación del ambiente
- Color del piso

👉 Es normal tener que ajustarlo.

---

## 🕹️ Funcionamiento del LED

El LED NeoPixel se usa como **semáforo visual**:

| Color | Significado |
|-----|---|
| 🔴 Rojo | Sensor detecta NEGRO |
| 🔵 Azul claro | Sensor detecta BLANCO |
| ⚫ Apagado | Programa detenido |

Esto permite entender el comportamiento **sin mirar la computadora**.

---

## ⌨️ Control por Monitor Serial

Durante la ejecución puedes escribir:

```text
STOP
```

Al presionar **Enter**:
- El LED se apaga
- El programa se detiene
- El ESP32 queda esperando reinicio

⚠️ Para volver a ejecutar el programa debes **reiniciar la placa**.

---

## 🧪 Cómo usar el programa (Arduino IDE)

1. Instala **Arduino IDE**
2. Instala la librería **Adafruit NeoPixel**
3. Conecta el ESP32 por USB
4. Abre `PruebaIR.ino`
5. Selecciona:
   - **Tools → Board → ESP32**
   - **Tools → Port → tu puerto**
6. Presiona **Upload**

### Para ver los datos:
- Abre **Serial Monitor**
- Baud rate: **115200**

---

## ❗ Errores comunes

### Siempre detecta blanco o negro
- Ajusta `valor_critico`
- Revisa la altura del sensor
- Prueba sobre diferentes superficies

### El LED no enciende
- Revisa que la librería esté instalada

### STOP no funciona
- Usa **115200 baud**
- Escribe STOP y presiona **Enter**

---

## 🌟 Ideas de mejora

- Usar **un LED por sensor**
- Mostrar combinaciones de sensores
- Enviar datos en formato tabla por Serial
- Integrar motores para seguimiento de línea
- Reemplazar delays por temporizadores

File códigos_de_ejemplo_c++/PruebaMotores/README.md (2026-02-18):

# 🔧 PruebaMotores (ESP32) — Control básico de un motor con velocidad y dirección

**Universidad CENFOTEC**  
**Autora:** Mariana Cubero  

Este programa es una **prueba simple de motores**, pensada para aprender cómo:

- Encender y apagar un motor
- Cambiar el **sentido de giro** (adelante / atrás)
- Variar la **velocidad** usando valores entre `-1` y `1`
- Usar **PWM** de forma básica en un ESP32

Es un excelente primer paso antes de hacer robots más complejos 🚗🤖

---

## 🧠 ¿Qué hace este código?

El programa prueba **un solo motor (Motor A)** usando diferentes valores de velocidad:

- `1` → máxima velocidad hacia adelante
- `0` → motor detenido
- `-1` → máxima velocidad hacia atrás
- `0.5` → velocidad media hacia adelante
- `-0.5` → velocidad media hacia atrás

Cada estado dura **2 segundos**, para que el comportamiento sea fácil de observar.

> 📝 Aunque hay pines definidos para el **Motor B**, este código se enfoca únicamente en probar el **Motor A**.

---

## 📚 Librerías usadas

Este programa **no usa librerías externas**.  
Solo funciones básicas del entorno Arduino:

- `pinMode()`
- `digitalWrite()`
- `analogWrite()`
- `delay()`
- `Serial.begin()`

---

## 🕹️ Concepto clave: velocidad entre -1 y 1

La función principal del programa es:

```cpp
bool moveMotor1(float s);
```

El valor `s` representa:

| Valor de `s` | Comportamiento |
|---|---|
| `1` | Máxima velocidad hacia adelante |
| `0.5` | Velocidad media hacia adelante |
| `0` | Motor detenido |
| `-0.5` | Velocidad media hacia atrás |
| `-1` | Máxima velocidad hacia atrás |

Si `s` está fuera del rango `[-1, 1]`, la función devuelve `false` y **no mueve el motor**.

---

## 🔁 ¿Cómo se controla el motor?

El motor tiene **dos pines**:

- Uno controla el giro hacia adelante
- El otro controla el giro hacia atrás

El código:
- Usa **PWM (`analogWrite`)** en un pin
- Apaga el otro pin con `LOW`

Así se controla:
- Dirección
- Velocidad

---

## 🧮 Función `motorMap()`

```cpp
int motorMap(float value, float fromLow, float fromHigh, float toLow, float toHigh)
```

Esta función convierte un número flotante (por ejemplo `0.5`) en un valor de **PWM (0 a 255)**.

Ejemplo:
- `0.5` → aproximadamente `127`
- `1.0` → `255`

Es similar a la función `map()` de Arduino, pero adaptada para valores decimales.

---

## 🧪 Qué verás al ejecutarlo

El motor:

1. Gira fuerte hacia adelante
2. Se detiene
3. Gira fuerte hacia atrás
4. Se detiene
5. Gira lento hacia adelante
6. Se detiene
7. Gira lento hacia atrás
8. Se detiene

Cada paso dura **2 segundos**.

---

## 🧰 Cómo usarlo en Arduino IDE

1. Instala **Arduino IDE**
2. Instala soporte para **ESP32**
3. Conecta el ESP32 por USB
4. Abre `PruebaMotores.ino`
5. Selecciona:
   - **Tools → Board → ESP32**
   - **Tools → Port → tu puerto**
6. Presiona **Upload**

Opcional:
- Abre el **Serial Monitor**
- Baud rate: **115200**

---

## ❗ Errores comunes

### El motor no se mueve
- Revisa tener el jumper de la placa en Vin-Select y que tenga las baterias conectadas y encendidas.

### El motor gira al revés
- Dale la vuelta a los cables del motor.

### Velocidad extraña
- Algunos drivers no responden igual al PWM
- Ajusta valores o prueba otro pin PWM

---

## 🌟 Ideas de mejora

- Agregar control del **Motor B**
- Controlar ambos motores con una sola función
- Controlar velocidad desde el **Monitor Serial**
- Usar botones o joystick

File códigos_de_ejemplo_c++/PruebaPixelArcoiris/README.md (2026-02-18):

# 🌈 PruebaPixelArcoiris (ESP32 / Arduino) — LED NeoPixel con efecto arcoíris

**Autora:** Fiorella Pérez López  
**Universidad CENFOTEC**

Este programa controla un **LED NeoPixel (RGB direccionable)** para mostrar un **efecto de arcoíris continuo**.  
Además, permite **detener el programa escribiendo un comando desde el Monitor Serial**, lo cual lo hace ideal para aprender:

- LEDs RGB
- Uso de librerías externas
- Comunicación por **Serial**
- Control básico de efectos visuales

Es un excelente primer ejemplo para introducir **iluminación programable** de forma visual y divertida 🌈

---

## 🧠 ¿Qué hace este código?

El programa:

1. Inicializa un LED NeoPixel incorporada en la IdeaBoard
2. Genera colores del arcoíris usando una función matemática
3. Cambia el color del LED suavemente
4. Escucha comandos escritos por el usuario en el **Monitor Serial**
5. Si el usuario escribe `STOP`, el programa se detiene por completo

---

## 📚 Librerías utilizadas

Este proyecto **usa una librería externa**:

### Adafruit NeoPixel
```cpp
#include <Adafruit_NeoPixel.h>
```

📦 Para instalarla:
1. Abre **Arduino IDE**
2. Ve a **Sketch → Include Library → Manage Libraries**
3. Busca **Adafruit NeoPixel**
4. Instálala

---

## 🕹️ Funciones importantes (explicadas fácil)

### `Wheel(byte WheelPos)`

Esta función convierte un número entre **0 y 255** en un color RGB.

- Primero pasa de **rojo → verde**
- Luego de **verde → azul**
- Finalmente de **azul → rojo**

Esto permite crear un **arcoíris suave**, sin saltos bruscos de color.

---

### Comunicación Serial

En el `loop()` el programa revisa:

```cpp
if (Serial.available()) {
  comando = Serial.readStringUntil('\n');
}
```

Esto permite que el usuario escriba texto en el **Monitor Serial**.

Si el texto es:

```text
STOP
```

El programa entra en:

```cpp
while (true);
```

Eso significa:
➡️ El microcontrolador **queda detenido para siempre** (hasta reiniciar).

---

## 🌈 Efecto arcoíris

El efecto se genera con este ciclo:

```cpp
for (int i = 0; i < 256; i++) {
  uint32_t color = Wheel(i);
  strip.setPixelColor(0, color);
  strip.show();
  delay(20);
}
```

- Recorre todos los colores posibles
- Cambia el LED poco a poco
- Produce una transición suave y continua

---

## 🎚️ Ajustes fáciles para experimentar

### Velocidad del arcoíris
```cpp
delay(20);
```

- Menor valor → más rápido
- Mayor valor → más lento

Ejemplo:
- `delay(5)` → muy rápido
- `delay(50)` → muy suave

---

## 🧪 Cómo usar el programa (paso a paso)

1. Instala **Arduino IDE**
2. Instala la librería **Adafruit NeoPixel**
3. Conecta el ESP32 por USB
4. Abre el archivo `PruebaPixelArcoiris.ino`
5. Selecciona:
   - **Tools → Board → ESP32 Dev Module**
   - **Tools → Port → (tu puerto)**
6. Presiona **Upload**

### Para detener el programa:
1. Abre **Serial Monitor**
2. Baud rate: **9600**
3. Escribe:
   ```text
   STOP
   ```
4. Presiona **Enter**

---

## ❗ Errores comunes

### El LED no enciende
- Revisa el pin de datos (GPIO2)
- Verifica alimentación del LED
- Revisa que la librería esté instalada

### El comando STOP no funciona
- Asegúrate de usar **115200 baud**
- Escribe `STOP` en mayúsculas
- Presiona **Enter**

---

## 🌟 Ideas de mejora

- Cambiar colores por comandos (`ROJO`, `AZUL`, etc.)
- Agregar botón físico para detener
- Usar varios LEDs con patrones distintos
- Combinar con sensores (luz, distancia, sonido)

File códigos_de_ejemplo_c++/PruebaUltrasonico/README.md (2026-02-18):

# 🦇 PruebaUltrasonico Sumobot que evita obstáculos a 10 cm

**Universidad CENFOTEC**  
**Autora:** Mariana Cubero  

Este programa controla un robot con **dos motores** y un sensor **ultrasónico**, para que avance solo y, cuando detecte un obstáculo muy cerca (**menos de 10 cm**), haga esto:

1. 🛑 Detecta el obstáculo  
2. ↩️ Retrocede por 1 segundo  
3. ➡️ Gira a la derecha por 1 segundo  
4. 🚀 Vuelve a avanzar  

Es un comportamiento sencillo, ideal como primera práctica para entender **motores + ultrasonido**.

---

## 🧠 ¿Qué hace este código?

En el `loop()`:

- Mide la distancia con `medirDistanciaCM()`
- Imprime esa distancia en el **Serial Monitor**
- Si la distancia es válida y menor a `10 cm`:
  - retrocede (`atras()`)
  - gira (`girarDerecha()`)
  - luego continúa avanzando
- Si no hay nada cerca:
  - avanza (`adelante()`)

---

## 📚 Librerías usadas

No usa librerías externas.

- pinMode
- digitalWrite
- delay / delayMicroseconds
- pulseIn
- Serial

---

## 🕹️ Funciones principales

### Movimiento
- `adelante()` → avanza
- `atras()` → retrocede
- `parar()` → detiene motores
- `girarDerecha()` → giro sobre su eje

### Ultrasonido
`medirDistanciaCM()`:
- Envía pulso TRIG
- Mide eco con pulseIn
- Convierte a centímetros
- Devuelve `-1` si no hay eco

---

## 🎚️ Ajustes recomendados

### Distancia de detección
```cpp
const float DISTANCIA_UMBRAL = 10.0;
```

Prueba valores como:
- 15 cm (más precaución)
- 5 cm (más agresivo)

### Tiempos
```cpp
delay(1000); // retroceso
delay(1000); // giro
```

---

## 🧪 Uso con Arduino IDE

1. Instala Arduino IDE  
2. Instala soporte ESP32  
3. Conecta el ESP32 por USB  
4. Selecciona placa y puerto  
5. Abre `PruebaUltrasonico.ino`  
6. Presiona **Upload**  

Para ver datos:
- Abre **Serial Monitor**
- Baud rate: **115200**

---

## ❗ Errores comunes

- Siempre marca `-1` → revisar TRIG/ECHO y voltajes, el jumper de la IdeaBoard debe de estar en Vin-Select y tener las baterías conectadas y encendidas.
- Motores en direcciones incorrectas  → Dale vuelta a los cables de los motores.

---

## 🌟 Ideas de mejora

- Giro aleatorio
- Uso de PWM para velocidad
- Promediar lecturas
- Usar `parar()` entre movimientos

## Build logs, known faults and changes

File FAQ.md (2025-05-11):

#  Preguntas Frecuentes

1. **¿Se puede modificar el código del robot?**
   - Sí, el código puede ser adaptado libremente.

2. **¿Se pueden agregar sensores?**
   - Sí, siempre y cuando no impliquen modificaciones estructurales al robot, y no exceda el peso permitido.

3. **¿Se puede modificar el chasis o los motores?**
   - No. Las partes estructurales, motores, ruedas y baterías deben permanecer como en el kit oficial.

4. **¿Los estudiantes deben llevar el código memorizado?**
   - No, pueden llevarlo preparado y modificarlo durante el evento. Se les proporcionará equipo si no tienen acceso a uno.

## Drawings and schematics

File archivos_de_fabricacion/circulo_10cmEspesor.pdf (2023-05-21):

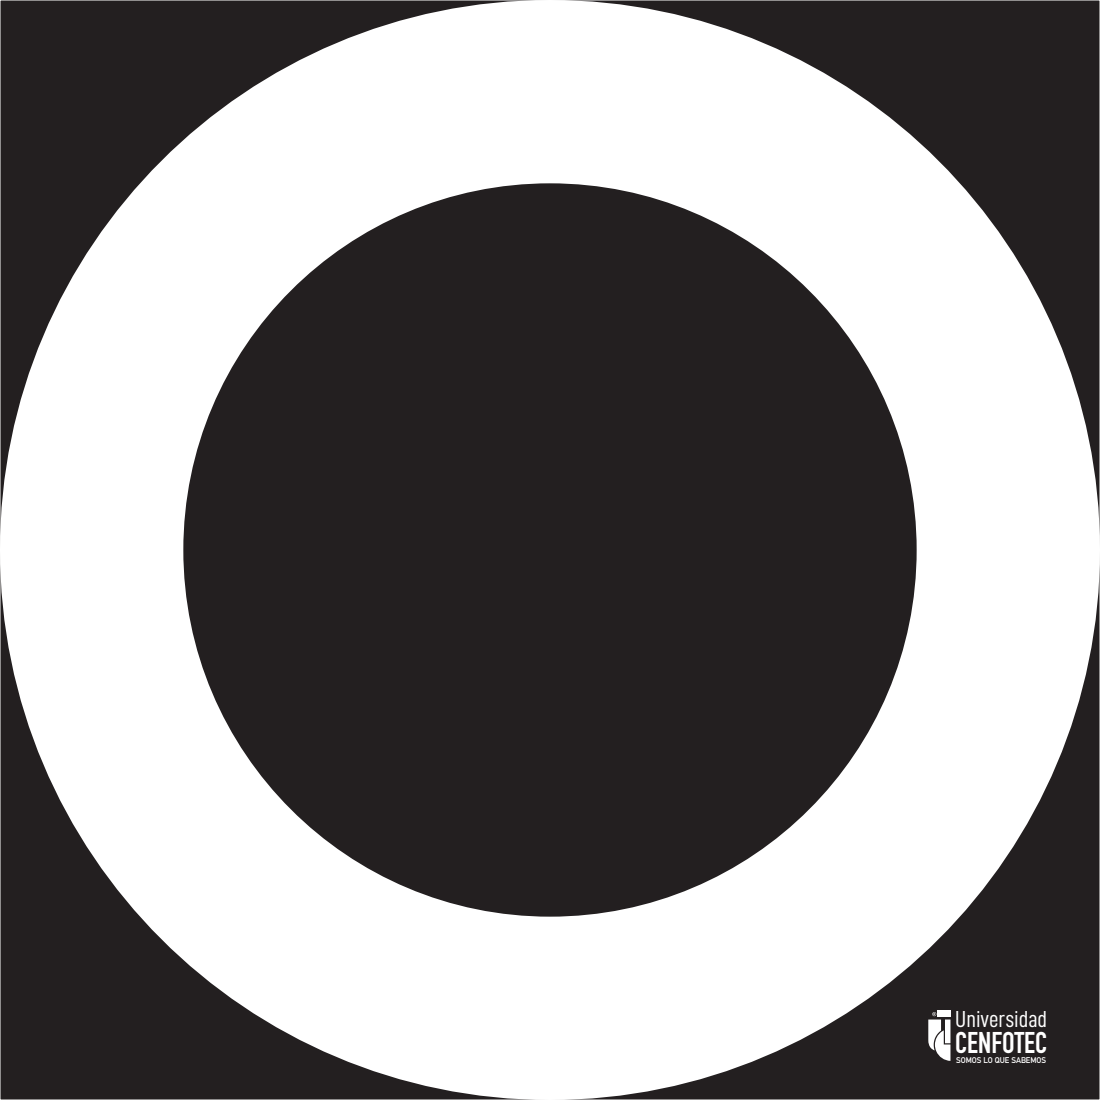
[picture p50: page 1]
Universidad CENFOTEC

SOMOS LO QUE SABEMOS

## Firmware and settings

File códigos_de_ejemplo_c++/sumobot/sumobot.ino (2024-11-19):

// Tomás de Camino Beck & Jeffry Valverde 
// Escuela de Sistemas Inteligentes
// Universidad Cenfotec

// Definición de pines para motores y sensores
#define A_IN1 13  // Motor A, dirección 1
#define A_IN2 15  // Motor A, dirección 2
#define B_IN1 12  // Motor B, dirección 1
#define B_IN2 14  // Motor B, dirección 2

#define TRIG_PIN 26   // Pin TRIG del sensor ultrasónico
#define ECHO_PIN 25   // Pin ECHO del sensor ultrasónico

#define SENSOR_1 35   // Sensor IR 1
#define SENSOR_2 34   // Sensor IR 2
#define SENSOR_3 39   // Sensor IR 3
#define SENSOR_4 36   // Sensor IR 4

#define THRESHOLD 500 // Umbral para detección en sensores IR

// Variables para la medición de distancia
float duration, distance;

// Configura los motores con velocidades específicas
void setMotors(int speedA1, int speedA2, int speedB1, int speedB2) {
  analogWrite(A_IN1, speedA1);  // Velocidad en Motor A (dirección 1)
  analogWrite(A_IN2, speedA2);  // Velocidad en Motor A (dirección 2)
  analogWrite(B_IN1, speedB1);  // Velocidad en Motor B (dirección 1)
  analogWrite(B_IN2, speedB2);  // Velocidad en Motor B (dirección 2)
}

// Realiza un movimiento oscilatorio (izquierda-derecha) n veces
void wiggle(float t, int n, int speed) {
  for (int i = 0; i < n; i++) {
    setMotors(0, speed, speed, 0); // Gira hacia la izquierda
    delay(t * 1000);               // Espera t segundos
    setMotors(speed, 0, 0, speed); // Gira hacia la derecha
    delay(t * 1000);               // Espera t segundos
    stop();                        // Detiene los motores
    delay(t * 1000);               // Pausa entre ciclos
  }
}

// Avanza hacia adelante por un tiempo t con una velocidad dada
void forward(float t, int speed) {
  setMotors(speed, 0, speed, 0); // Ambos motores avanzan
  delay(t * 1000);               // Espera t segundos
  stop();                        // Detiene el robot
}

// Retrocede por un tiempo t con una velocidad dada
void backward(float t, int speed) {
  setMotors(0, speed, 0, speed); // Ambos motores retroceden
  delay(t * 1000);               // Espera t segundos
  stop();                        // Detiene el robot
}

// Gira a la izquierda por un tiempo t con una velocidad dada
void left(float t, int speed) {
  setMotors(0, speed, speed, 0); // Gira a la izquierda
  delay(t * 1000);               // Espera t segundos
  stop();                        // Detiene el robot
}

// Gira a la derecha por un tiempo t con una velocidad dada
void right(float t, int speed) {
  setMotors(speed, 0, 0, speed); // Gira a la derecha
  delay(t * 1000);               // Espera t segundos
  stop();                        // Detiene el robot
}

// Detiene ambos motores
void stop() {
  setMotors(0, 0, 0, 0); // Apaga ambos motores
}

// Realiza un giro aleatorio hacia la izquierda o derecha
void randomTurn(float t, int speed) {
  int dir = random(0, 2); // Genera 0 (izquierda) o 1 (derecha)
  if (dir == 0) {
    left(t, speed);       // Gira a la izquierda
  } else {
    right(t, speed);      // Gira a la derecha
  }
}

// Mide la distancia hacia adelante con el sensor ultrasónico
float lookForward() {
  stop();                         // Detiene el robot para medir
  digitalWrite(TRIG_PIN, LOW);    // Asegura que TRIG esté en LOW
  delayMicroseconds(2);           
  digitalWrite(TRIG_PIN, HIGH);   // Envía pulso TRIG
  delayMicroseconds(10);          // Duración del pulso
  digitalWrite(TRIG_PIN, LOW);    // Finaliza el pulso
  duration = pulseIn(ECHO_PIN, HIGH); // Mide la duración del pulso ECHO
  distance = (duration * 0.0343) / 2; // Convierte duración a distancia en cm
  delay(200);                     
  return distance;                // Retorna la distancia medida
}

// Realiza un escaneo girando hacia la izquierda hasta encontrar un objeto
bool scan() {
  stop();                         // Detiene el robot
  int maxCount = 10;              // Máximo número de intentos
  int count = 0;                  // Contador de intentos
  float dist = lookForward();     // Mide la distancia inicial
  while (count < maxCount && (dist > 30 || dist == -1)) {
    left(0.2, 150);               // Gira a la izquierda
    count++;                      // Incrementa el contador
    dist = lookForward();         // Mide nuevamente
    stop();                       // Detiene el robot
  }
  return (count < maxCount);      // Devuelve true si encuentra algo
}

// Avanza verificando constantemente los sensores IR
void forwardCheck(float t, int speed) {
  int d = int(t / 0.1); // Divide el tiempo en pasos de 0.1 segundos
  for (int i = 0; i < d; i++) {
    // Lee los valores de los sensores IR
    int sensorValue1 = analogRead(SENSOR_1);
    int sensorValue2 = analogRead(SENSOR_2);
    int sensorValue3 = analogRead(SENSOR_3);
    int sensorValue4 = analogRead(SENSOR_4);

    // Si algún sensor detecta un obstáculo
    if (sensorValue1 > THRESHOLD || sensorValue2 > THRESHOLD || 
        sensorValue3 > THRESHOLD || sensorValue4 > THRESHOLD) {
      stop();                     // Detiene el robot
      delay(300);                 
      backward(1, 150);           // Retrocede
      randomTurn(1, 150);         // Gira aleatoriamente
      return;                     // Sale de la función
    }
    forward(0.1, speed);          // Avanza por 0.1 segundos
  }
  stop();                         // Detiene el robot           
}

// Configuración inicial
void setup() {
  pinMode(TRIG_PIN, OUTPUT); // Configura TRIG como salida
  pinMode(ECHO_PIN, INPUT);  // Configura ECHO como entrada
  pinMode(A_IN1, OUTPUT);    // Pines de motores como salida
  pinMode(A_IN2, OUTPUT);
  pinMode(B_IN1, OUTPUT);
  pinMode(B_IN2, OUTPUT);

  Serial.begin(115200);          
}

// Ciclo principal
void loop() {
  if (scan()) {                   // Si encuentra un camino libre
    delay(200);                  
    forwardCheck(0.5, 200);       // Intenta avanzar
  } else {                        // Si no encuentra camino libre
    delay(200);                   
    randomTurn(1, 200);           // Gira aleatoriamente
    forwardCheck(0.5, 200);       // Intenta avanzar nuevamente
  }
  delay(200);
}

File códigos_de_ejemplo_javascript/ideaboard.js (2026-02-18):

/**
 * @file ideaboard.js
 * @description
 * Port de `ideaboard.py` (CircuitPython) por Bentley Born para la
 * IdeaBoard de CRCibernética, adaptado a JavaScript usando Espruino.
 *
 * Este módulo expone una API similar a CircuitPython para facilitar
 * el control de motores, servos, entradas/salidas digitales,
 * entradas analógicas y el NeoPixel integrado.
 *
 * @author Emanuel Mena
 * @version 1.0.0
 * @date 2026-02-06
 */

const neopixel = require("neopixel");

// -----------------------------
// Helpers
// -----------------------------

/**
 * Limita un valor dentro de un rango.
 *
 * @param {number} x Valor de entrada
 * @param {number} a Límite inferior
 * @param {number} b Límite superior
 * @returns {number} Valor limitado entre `a` y `b`
 */
function clamp(x, a, b) {
  return x < a ? a : x > b ? b : x;
}


/**
 * Mapea un valor desde un rango a otro.
 *
 * @param {number} x Valor a mapear
 * @param {number} inMin Mínimo del rango de entrada
 * @param {number} inMax Máximo del rango de entrada
 * @param {number} outMin Mínimo del rango de salida
 * @param {number} outMax Máximo del rango de salida
 * @returns {number} Valor mapeado al nuevo rango
 */
function map_range(x, inMin, inMax, outMin, outMax) {
  if (inMax === inMin) return outMin;
  return outMin + ((x - inMin) * (outMax - outMin)) / (inMax - inMin);
}


// Rainbow colorwheel
function colorwheel(pos) {
  pos = ((pos % 256) + 256) % 256;
  if (pos < 85) {
    return [pos * 3, 255 - pos * 3, 0];
  } else if (pos < 170) {
    pos -= 85;
    return [255 - pos * 3, 0, pos * 3];
  } else {
    pos -= 170;
    return [0, pos * 3, 255 - pos * 3];
  }
}

// NeoPixel en Espruino usa GRB. (por alguna razón)
// Para "hacerlo igual" a CircuitPython (RGB), convertimos a GRB al enviar.
function rgbToGrb(rgb) {
  const r = clamp(rgb[0] | 0, 0, 255);
  const g = clamp(rgb[1] | 0, 0, 255);
  const b = clamp(rgb[2] | 0, 0, 255);
  return new Uint8Array([g, r, b]);
}

/**
 * Controlador de motor DC usando dos pines PWM.
 * Permite controlar dirección y velocidad con un valor de -1 a 1.
 */
class DCMotor {

    /**
   * @param {Pin} pinA Pin PWM para giro positivo
   * @param {Pin} pinB Pin PWM para giro negativo
   * @param {Object} [opts] Opciones de configuración
   * @param {number} [opts.freq=50] Frecuencia PWM en Hz
   */
  constructor(pinA, pinB, opts) {

    opts = opts || {};
    this.pinA = pinA;
    this.pinB = pinB;
    this.freq = opts.freq || 50;
    this._throttle = 0;

    pinMode(this.pinA, "output");
    pinMode(this.pinB, "output");

    //Inicializa PWM una vez para reservar canal
    analogWrite(this.pinA, 0, { freq: this.freq });
    analogWrite(this.pinB, 0, { freq: this.freq });

    this.stop("coast");

    return this;
  }

    /**
   * Velocidad del motor.
   * Rango: -1 (máxima reversa) a 1 (máximo avance).
   *
   * @type {number}
   */
  get throttle() {
    return this._throttle;
  }


    /**
   * @param {number} value Valor entre -1 y 1
   */
  set throttle(value) {

    const t = clamp(+value || 0, -1, 1);
    this._throttle = t;

    const mag = Math.abs(t);

    if (mag === 0) {
      this.stop("coast");
      return;
    }

    if (t > 0) {
      digitalWrite(this.pinB, 0);
      analogWrite(this.pinA, mag, { freq: this.freq });
    } else {
      digitalWrite(this.pinA, 0);
      analogWrite(this.pinB, mag, { freq: this.freq });
    }
  }

  stop(mode) {
    mode = mode || "coast";
    if (mode === "brake") {
      digitalWrite(this.pinA, 1);
      digitalWrite(this.pinB, 1);
    } else {
      digitalWrite(this.pinA, 0);
      digitalWrite(this.pinB, 0);
    }
    this._throttle = 0;
  }
}

/**
 * Control de servo estándar por PWM.
 * Compatible con servos de 0 a 180 grados.
 */
class Servo {

    /**
   * @param {Pin} pin Pin PWM
   * @param {number} [freq=50] Frecuencia en Hz
   * @param {number} [min_pulse=500] Pulso mínimo en microsegundos
   * @param {number} [max_pulse=2500] Pulso máximo en microsegundos
   */
  constructor(pin, freq, min_pulse, max_pulse) {

    this.pin = pin;
    this.freq = freq || 50;
    this.min_pulse = min_pulse == null ? 500 : min_pulse;
    this.max_pulse = max_pulse == null ? 2500 : max_pulse;
    this._angle = 0;

    pinMode(this.pin, "output");
    this.angle = 0;
    return this;
  }

  get angle() {
    return this._angle;
  }

  set angle(deg) {
    const a = clamp(+deg || 0, 0, 180);
    this._angle = a;

    // Convertir ángulo a pulso (us)
    const pulseUs = this.min_pulse + (a / 180) * (this.max_pulse - this.min_pulse);

    // En Espruino analogWrite duty es 0..1
    // periodo = 1/freq segundos => en microsegundos:
    const periodUs = 1e6 / this.freq;
    const duty = clamp(pulseUs / periodUs, 0, 1);

    analogWrite(this.pin, duty, { freq: this.freq });
  }
}
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

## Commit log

2023-04-07 Diseño en SVG del chasis para corte laser
2023-04-11 Agregó archivo para impresión 3d
2023-04-11 Corrección de errores
2023-05-08 para incluir videos youtube
2023-05-08 Explicación de instalación de Thonny
2023-06-01 Cambio el en forwardcheck()
    Sleep mas largo para evitar reset de placa
    [code.py]
2023-07-03 Ordenamiento de repositorio
    Se construyen carpetas con secciones para mayor claridad
    [SumoBot_Chasis3D.stl]
2023-07-14 FreeCAD model
    Modelo en FreeCAD con clip para ensamblaje fácil
    [Sumobot_acrilic_3mm.FCStd, base.dxf, laterales.dxf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]
2023-07-19 Mejora en techo
    Mejora en techo, agrado de topes para laterales
    [Sumobot_acrilic_3mm.FCStd, laterales.dxf, pared_trasera.dxf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]
2023-07-19 Ampliación parte trasera de base
    Ampliación parte trasera de base, prevenir fracturas por caídas altas
    [Sumobot_acrilic_3mm.FCStd, base.dxf]
2023-07-19 Refuerzo laterales
    Refuerzo laterales
    [Sumobot_acrilic_3mm.FCStd, base.dxf]
2024-03-01 Cambio en la reglamentación
    Se cambiaron las reglas para el torneo del 2024
2024-04-10 Delete archivos_de_fabricacion/SumoBot_Chasis3D.stl
    obsoleto
    [SumoBot_Chasis3D.stl]
2024-04-10 Update README.md
    Cambio en el peso del robot
2024-04-11 Update README.md
    Actualización de imágenes y links
2024-04-12 Archivo de corte laser
2024-04-30 Add files via upload
    Muestra como grabar archivos en el IdeaBoard
2024-06-14 Ejemplooo de uso de acelerómetro
2025-02-22 Explicación de Archivos .mpy y agregación de la libreria para versiones 9.x de CircuitPython
2025-02-23 Refactorización y Actualización de Archivos de fabricación
    [Chasis_Sumobot_3D_2025.stl, Sumobot_acrilic_3mm.FCStd, base.dxf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]
2025-02-24 refactorización de ordén de archivos
2025-02-24 actualización de código con nueva placa
2025-02-27 Mejoras de Documentación
2025-02-27 agregado de link a libreria y cambio de nombre por consistencia de códigos de lsm6ds
2025-05-17 Update code_lecturaIR_4Bit.py
    Cambio para que negro sea 0
2025-06-06 Funcion para controlar NeoPixel facilmente
2025-06-13 Añadido modelo 3D de Soporte para Motores
    [MOTOR_BRACKET.stl]
2025-06-15 Escaneo de red local para detectar dispositivos accesibles por puerto TCP
    Script en Python para identificar automáticamente dispositivos en la red local que tengan un puerto específico abierto (por defecto el 80). Este escáner es útil para encontrar la IP de microcontrolad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
    🔹 Obtiene automáticamente la red local en formato CIDR (e.g. 192.168.1.0/24)
    🔹 Escanea en paralelo con múltiples hilos
    🔹 Verifica si el puerto está abierto antes de mostrar la URL accesible
    🔹 Ideal para entornos educativos o pruebas con hardware IoT como la Idea Board
2025-06-15 Servidor web embebido para controlar tu SumoBot vía Wi-Fi
    Servidor HTTP en CircuitPython para controlar un robot SumoBot desde el navegador mediante una interfaz gráfica responsive y elegante. Esta solución transforma tu ESP32 (Idea Board) en un robot controlable por Wi-Fi, ideal para educación, demostraciones y pruebas sin conexión USB directa.
    🔹 Panel web con botones de dirección y duración configurable
    🔹 Control de motores a través de comandos HTTP (GET)
    🔹 Estética futurista optimizada para dispositivos móviles
    🔹 Manejo robusto de errores con registro local en error.out
    🔹 Código modular y comentado para facilitar su extensión
    Incluye una barra de progr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
    [wifiApp.py]
2025-12-28 Deprecado la libreria HCSR04 para CircuitPython 8.x y se actualizó la documentación
    Se trasladó la versión 8.x de la biblioteca HCSR04 a una carpeta obsoleta con un nuevo README que explica su estado de legado. Se actualizó el README principal para aclarar la compatibilidad entre Ci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
2025-12-28 Deleted Sumobot_Device_Files.zip
    Not really a reliable way for rapid restoration of device files
2026-01-15 Rename reglas_2025.md to reglas de competencia.md
2026-01-15 Revise SumoBot components and chassis sections
    Updated the content and title for the SumoBot documentation, removing the year and adjusting the descriptions.
2026-01-16 Refactor C++ examples: reorganize files and add docs
    Moved example sketches from the sumobot directory into topic-specific folders (NeoPixel, PruebaIR, PruebaMotores, PruebaPixelArcoiris, PruebaUltrasonico) and added detailed README.md files for each. 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
2026-02-02 Revise Cenfobot specifications and competition rules
    Updated specifications for the Cenfobot, including weight limits, energy source requirements, and modifications allowed. Clarified rules regarding contact with opponents and sensor installations.
2026-02-02 Update reglas de competencia.md
2026-02-07 Add Spanish Espruino examples and IdeaBoard
    Add a set of Spanish-language Espruino examples and supporting module.
    Files added:
    - códigos_de_ejemplo_javascript/README.md (Spanish README explaining Espruino and usage)
    - códigos_de_ejemplo_javascript/code.js (line-follower with obstacle detection)
    - códigos_de_ejemplo_javascript/batalla.js (SumoBot battle mode behavior)
    - códigos_de_ejemplo_javascript/ideaboard.js (JavaScript port of the IdeaBoard helper API: DCMotor, Servo, DigitalIn/Out, AnalogIn/Out, NeoPixel helpers, utility functions)
    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
2026-03-06 Enhance README with physical programming details
    Added detailed explanation of physical programming using infrared sensors for the Sumobot, including introduction, definition, and sensor reading process.
2026-03-06 Add programmable robot control with IR and gyroscope
    Implement programmable robot control using IR sensors and a gyroscope for precise movement.
2026-03-06 Add infrared sensor data logging script
2026-10-30 Add web monitor section for sensor data
    Updated the README to include information about the web monitor for sensors.
